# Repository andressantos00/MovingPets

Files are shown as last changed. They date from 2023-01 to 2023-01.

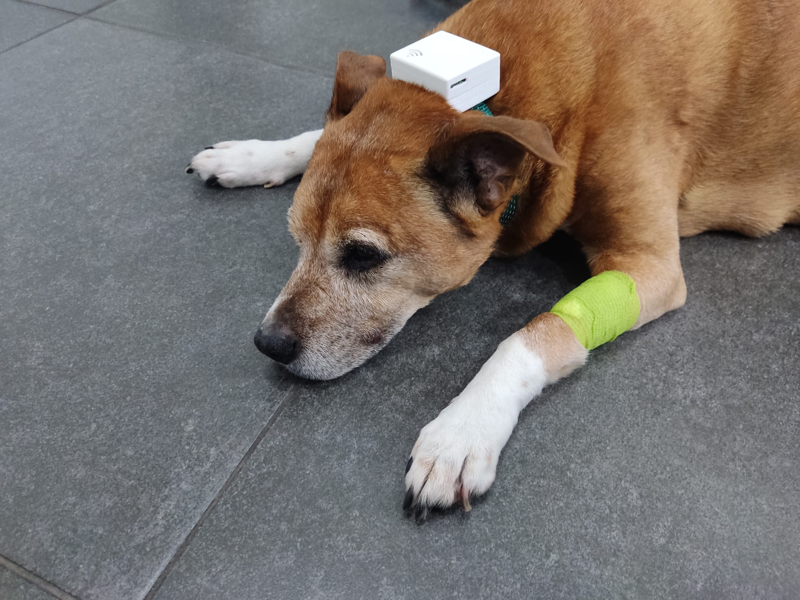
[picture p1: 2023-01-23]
Documentação/Sessão Final/Moving_Pets.jpg

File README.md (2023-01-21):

# MovingPets
Repositório de ficheiros elaborados no âmbito da cadeira de Projeto Industrial para a empresa "Pet Universal"

## Resumo
Quando um animal é sujeito a uma intervenção cirúrgica e há a necessidade de ficar hospitalizado, torna-se imperativo que, por parte da equipa veterinária, suceda um acompanhamento do estado de saúde do mesmo. Neste sentido, o projeto Moving Pets vem solucionar este problema, através do desenvolvimento de uma coleira capaz de medir o ritmo cardíaco, os níveis de oxigénio, a temperatura e, além disso, detetar o movimento do animal, dados que podem ser visualizados na aplicação móvel desenvolvida.

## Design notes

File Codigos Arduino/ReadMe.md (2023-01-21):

## Informações

Códigos criados pela equipa de hardware, com base nas bibliotecas existentes dos sensores usados, que se resumem a:
  - Código no concentrador;
  - Receber dados da esp8266 e enviar para a firebase;
  - Enviar dados da Esp8266 e enviar para o concentrador, com posterior envio destes para o wi-fi da clinica.

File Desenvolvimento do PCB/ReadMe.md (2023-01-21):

## Informações
A criação dos PCB`s foi da autoria dos membros do grupo, de modo a auxiliar a criação do primeiro protótipo de uma coleira.

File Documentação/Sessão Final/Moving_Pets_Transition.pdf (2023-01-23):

## 42088 – Projeto Industrial

# Relatório Final do Projeto

## Sessão Final - Transição

Nome do Projeto: | Moving Pets
Empresa: | Pet Universal
Orientador da Empresa: | Eng. Luís Pinto
Data: | 23/01/2023
Membros da Equipa: | Contacto principal: Bruna Pires | bruna.ramos.pires@ua.pt | +351 936 038 835 Membros do grupo: André Santos | andre.ssantos@ua.pt | +351 910 848 545 Daniel Almeida | danielba@ua.pt | +351 960 436 934 Gonçalo Martins | goncalom23@ua.pt | +351 934 554 483 João Francisco | joaofpedrosa@ua.pt | +351 962 478 430
Orientador: | Prof. Osvaldo Pacheco

## Índice

## I. Introdução

Atualmente, em situações onde um animal é sujeito a uma intervenção cirúrgica e se mostra necessário ficar hospitalizado, surge a necessidade, por parte da equipa veterinária, de verificar regularmente o estado de saúde destes seres, para garantir que está tudo bem com eles e acompanhar a sua evolução.

Neste sentido, o projeto Moving Pets vem solucionar este problema, uma vez que permitirá a monitorização do nível de atividade dos animais internados em box hospitalar.

Com o referido em mente, a solução idealizada pelo grupo é baseada na implementação de uma coleira com um microcontrolador - ESP8266 - e um conjunto de sensores, tais como: temperatura, ritmo cardíaco e níveis de oxigénio, como também um módulo acelerómetro digital. No que respeita à bateria, será utilizada uma Li-Po, que visa uma autonomia mínima de, aproximadamente, 5 dias.

Os dados recolhidos pelos sensores, face à interligação que terão com o microcontrolador, serão encaminhados via WiFi para um concentrador, também este composto por um microcontrolador - ESP8266.

Este concentrador irá estar ligado à rede WiFi da clínica veterinária e enviará os dados para uma base de dados (Firebase).

Através de uma aplicação móvel para tablet, o utilizador final terá acesso aos valores dos dados recolhidos pelos sensores.

O presente documento, referente à Sessão Final, aborda o progresso no desenvolvimento do projeto até ao momento e engloba a fase de transição, encontrando-se dividido em dezasseis secções, além da atual.

Começa-se por fazer um breve resumo, de forma a situar o leitor acerca das tarefas referentes ao projeto Moving Pets que se encontram concluídas, para que, a partir daí, se possam aprofundar mais os detalhes inerentes ao trabalho já efetuado.

O sexto ponto descrito, a Arquitetura do projeto, faz referência a diagramas de blocos e ao fluxograma, elementos desenvolvidos como parte da apresentação da solução idealizada para este produto.

De seguida, são apresentados as Tarefas especificadas (Calendarização vs. Implementação), englobando a explanação do progresso e desvio do plano inicial, bem como evidenciando o plano de trabalho para a próxima iteração, para que seja possível aferir, de uma forma mais detalhada, o que foi relatado no resumo previamente referido nesta secção.

O décimo tópico a abordar refere-se aos Riscos que afetaram o desenvolvimento do trabalho previsto, provocando alterações na forma como foi planeado e distribuído, quer temporalmente, quer com base nos recursos humanos disponíveis no momento inicial.

Segue-se uma análise ao orçamento apresentado na última entrega, com a respetiva retificação que se encontra detalhada e justificada no ponto Estado financeiro.

No décimo segundo ponto deste documento é elencado o trabalho que cada elemento da equipa desenvolveu, de uma forma mais pormenorizada, sendo possível aferir qual a contribuição individual de cada elemento para o bom desempenho que o grupo apresentou até ao momento.

Por fim, o último ponto deste documento pretende evidenciar as principais conclusões a retirar do trabalho efetuado, bem como deixar uma perspetiva clara acerca das tarefas a desenvolver num trabalho futuro.

## II. Breve sumário do estado do projeto

Até ao momento, uma vez concluída a fase de transição, o projeto possui um protótipo final da solução idealizada inicialmente pelo grupo.

De salientar que a equipa de hardware, responsável pela parte de sensorização do projeto, estabeleceu conectividade entre o microcontrolador - ESP8266 - e os três sensores utilizados no projeto:

- Sensor de temperatura;
- Sensor de ritmo cardíaco e níveis de oxigénio;
- Módulo acelerómetro.

Por sua vez, a equipa de backend, encarregue pelo desenvolvimento, numa fase inicial, de um web service - que permitisse expor, numa tabela, os dados recolhidos pelos sensores - encontrou-se a formular um setup que possibilite aos médicos veterinários definir o tempo de recolha de dados que considerem mais adequado.

No que concerne ao desenvolvimento da aplicação móvel para tablet a mesma apresenta as seguintes páginas, a saber:

- Página de Login;
- Escolha do concentrador sobre o qual o utilizador pretende obter informações;
- Indicação do nome do animal associado à coleira especificada;
- Apresentação dos dados recolhidos pelos sensores.

Tendo em consideração as fases de um projeto (Inception, Elaboration, Construction e Transition), bem como os objetivos principais inerentes às mesmas, e ainda a planificação destinada ao desenvolvimento do projeto, representada no Gantt Chart (em anexo), desenvolvido na fase Inception, podemos considerar que o projeto se encontrou alinhado, de forma a cumprir-se com as datas de entrega estipuladas.

No que concerne ao orçamento do projeto, este encontra-se dentro dos limites estabelecidos pela empresa Pet Universal.

Como referido acima, o projeto decorreu como previsto.

## III. Estado do projeto

Numa fase inicial do projeto e, após reunir com o Engenheiro Luís Pinto, orientador por parte da empresa, ficou definido que o produto a desenvolver se focava numa coleira capaz de recolher dados clínicos do animal, a saber: ritmo cardíaco e níveis de oxigénio, temperatura e o nível de atividade do animal.

Na sua versão final, o presente projeto é composto por uma coleira standart, por um concentrador e por uma aplicação móvel para tablet.

A coleira acima referida foi desenvolvida com o propósito de medir o ritmo cardíaco, os níveis de oxigénio, a temperatura e, além do elencado, detetar o movimento do animal.

O protótipo final da mesma é composto pela coleira (tecido) e por duas caixas, em que uma delas é composta por: um microcontrolador (ESP8266), um módulo boost step up (0.9..4.2V para 5V -40..480mA), uma bateria 3.7V (500mAh Li-Po), um módulo carregador de bateria Li-Ion 1A e, por último, um interruptor deslizante de duas posições. Por outro lado, a segunda caixa incorpora três sensores, a saber: sensor de ritmo cardíaco e níveis de oxigénio, sensor de temperatura e o módulo acelerómetro digital (três eixos).

No que respeita ao concentrador, está previsto que este se encontre ligado à rede WiFi da clínica veterinária e envie os dados recolhidos pelos sensores para uma base de dados, mais concretamente, para a Firebase.

O mesmo é composto por uma caixa que contém no seu interior um microcontrolador (ESP8266), sendo ainda constituído por um cabo USB 2.0 A macho/ micro-USB macho e por um carregador de tomada USB.

Em relação ao desenvolvimento da aplicação móvel para tablet, a mesma apresenta as seguintes páginas, a saber:

- Página de Login;
- Escolha, por parte do utilizador, do concentrador sobre o qual pretende obter informações;
- Indicação do nome do animal associado à coleira especificada;
- Apresentação dos dados recolhidos pelos sensores, em tempo real.

A Pet Universal, empresa com a qual o nosso grupo estabeleceu parceria ao longo do semestre, pretendia que, com o desenvolvimento do projeto Moving Pets, se criasse um produto capaz de monitorizar o nível de atividade de animais internados em box hospitalar.

Tendo em conta o mencionado anteriormente, podemos afirmar que o objetivo deste projeto foi concluído com êxito.

## IV. Resumo do projeto

Com o referido em mente, a solução idealizada pelo grupo foi baseada na implementação de uma coleira com um microcontrolador - ESP8266 - e um conjunto de sensores, tais como: temperatura, ritmo cardíaco e oxímetro, como também um módulo acelerómetro digital. No que respeita à
bateria, será utilizada uma célula de lithium 18650, com um módulo de carregamento visando uma autonomia mínima de 5 dias.
Os dados recolhidos pelos sensores, face à interligação que terão com o microcontrolador, serão encaminhados via WiFi para um concentrador, também este composto por um microcontrolador -ESP8266.
Este concentrador irá estar ligado à rede WiFi da clínica veterinária e enviará os dados para uma base de dados.
Através de uma aplicação móvel para tablet, o utilizador final terá acesso aos dados recolhidos pelos sensores.
A implementação desta solução permitirá a recolha de uma vasta gama de informações acerca do animal, a saber: a temperatura do mesmo, movimento do animal bem como batimentos cardíacos e níveis de oxigénio.

## V. Definição e esboço do projeto

Com este projeto ambicionamos obter uma coleira capaz de analisar os sinais vitais de animais em box hospitalares.
Uma coleira que deteta e interpreta nos animais os seus:
- Movimentos;
- Batimentos cardíacos;
- Níveis de Oxigénio no sangue;
- Temperatura.

Através do WiFi estas informações serão enviadas para uma base de dados - a Firebase - e a Pet Universal responsabilizou-se por criar um software que processa estes dados.

## VI. Arquitetura do projeto

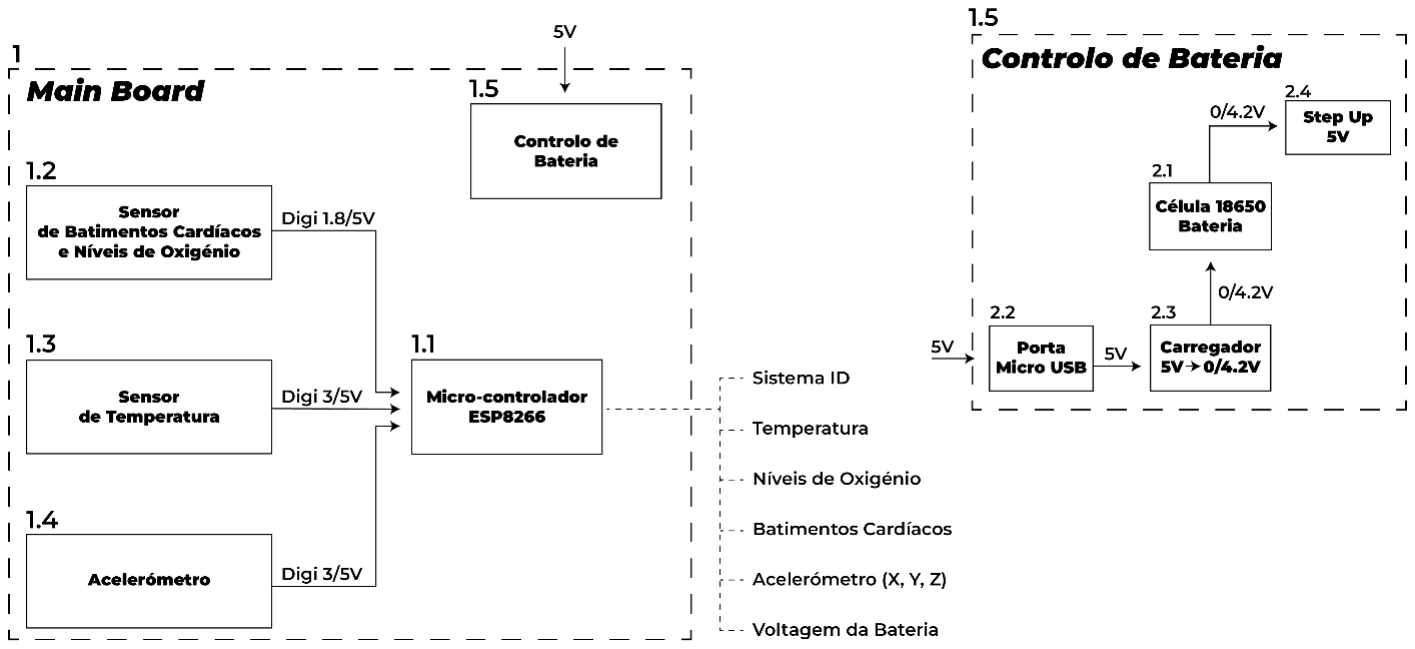
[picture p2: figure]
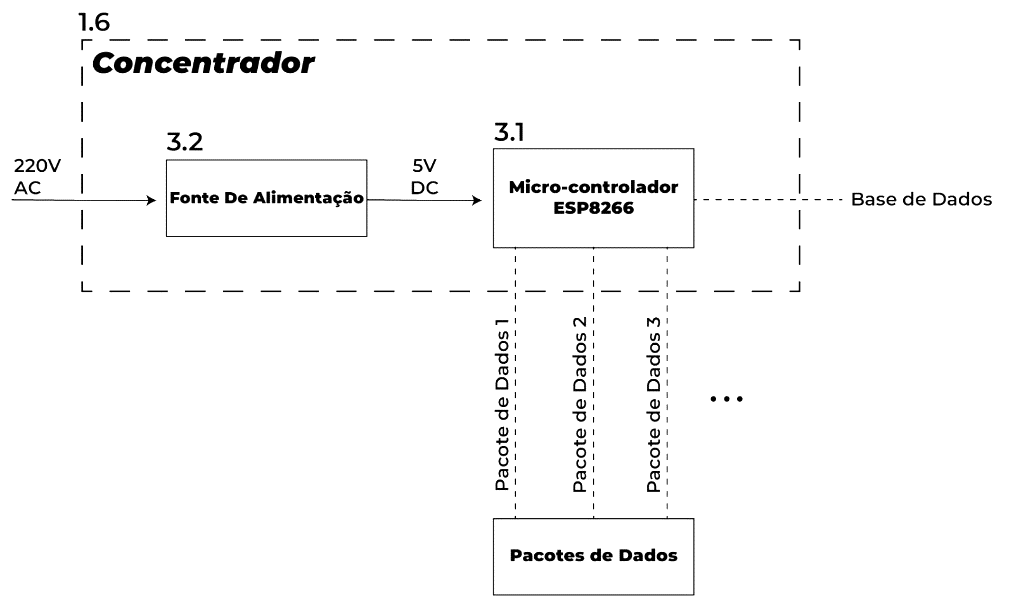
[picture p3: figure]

Figura 1 - Solução: Diagrama de Blocos

Em relação à arquitetura do sistema, contamos com dois diagramas de blocos, que correspondem ao sistema que vai estar presente na coleira do animal, e ao concentrador, que vai permitir o envio dos variados pacotes recebidos da coleira para a internet do hospital veterinário (Figura 1).

No fluxograma apresentado de seguida (Figura 2), temos os diferentes estados que o sistema empregue na coleira irá possuir.

Começamos pelo “DeepSleep” da ESP8266, que se concretiza por um modo de poupança de energia, com a duração de 5 minutos, onde esta estará desligada.

Após a passagem do tempo definido, a ESP8266 irá ligar-se, pedir valores aossensores(Acelerómetro, Temperatura e Oxímetro) e posteriormente criar um pacote de dados que irá ser enviado via WiFi para o concentrador.

De seguida, a ESP8266 irá voltar ao estado “DeepSleep”, o que resulta num período de operação de 1 segundo no seu estado ativo, intervalado por 5 minutos inativa. Com isto, temos um consumo 165mA por dia, o que se traduz em cerca de 5 dias de uso.

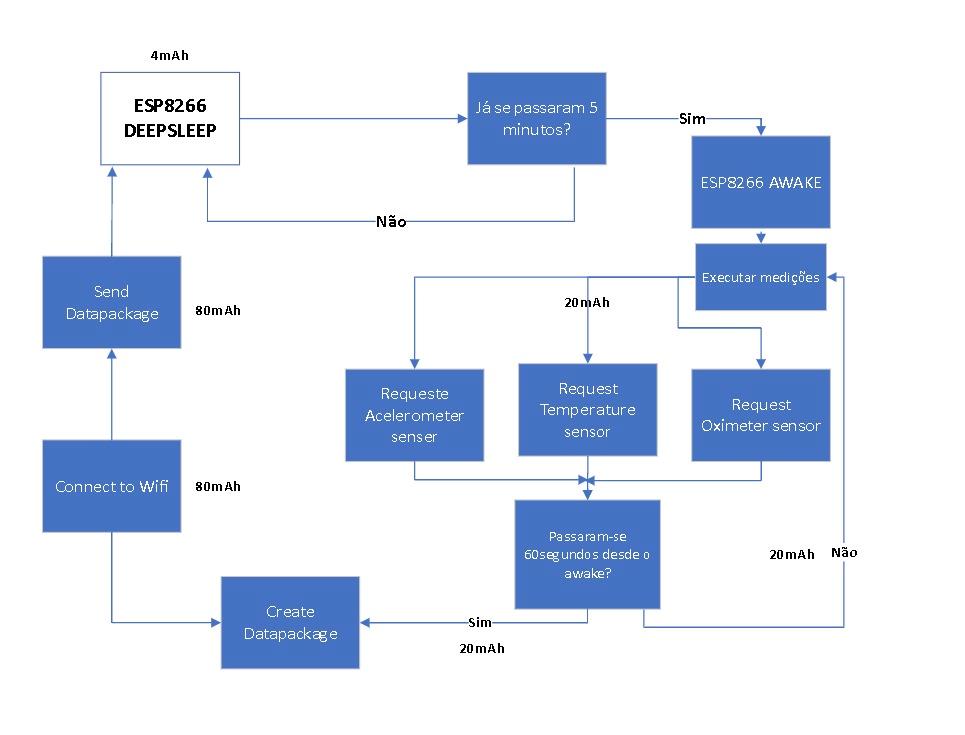
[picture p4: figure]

Figura 2 - Solução: Fluxograma

## VII. Documentos de design e produção

O grupo criou um repositório no GitHub onde se encontra a documentação técnica necessária para o desenvolvimento do presente projeto, pode ser consultado em:
- https://github.com/andressantos00/MovingPets

## VIII. Testes

No decorrer do desenvolvimento do projeto, o grupo testou o hardware desenvolvido que, posteriormente, será implementado nas coleiras. Esta ação teve como finalidade verificar a operacionalidade dos sensores, bem como a precisão dos dados recolhidos, quando empregues em animais.
Para isso, o primeiro teste realizado teve como cobaia uma gata de seis meses. O hardware implementado em placa branca, constituído por um microcontrolador - ESP8266 - e três sensores, foi aproximado junto do pescoço do animal e os dados recolhidos pelos sensores foram armazenados e apresentados num Google Sheets concretizado para o efeito – [Testes] - Coleira.
Alternativamente, o hardware foi aproximado na região tórax do animal a fim de verificar a variação dos dados recolhidos, permitindo concluir em que zona os dados se mostravam mais fidedignos e estáveis.
O resultado destes testes teve parecer positivo, porém o grupo quis generalizar mais esta testagem, por isso deslocou-se até ao Hospital Veterinário de Aveiro. Este contexto permitiu que o grupo realizasse ensaios, tanto em cães, como em gatos, com características diferenciadas, tais como: pelagens e dimensões.
Em suma, este primeiro período de testagens permitiu concluir que os dados recolhidos pelos sensores são mais satisfatórios quando são retirados junto do pescoço do animal, ou seja, existe a propensão de uma coleira standard para o protótipo do produto final.

IX. Tarefas especificadas (Calendarização vs.

## Implementação)

ID | Descrição | Data original | Data Reformulada | Data Real
1 | Especificação, escolha e aquisição dos sensores | 2ª e 3ª semana de outubro | Data original | Data original
2 | Especificação do concentrador | 2ª e 3ª semana de outubro | Data original | Data original
3 | Estudo e especificação do layout da coleira | 2ª e 3ª semana de outubro | Data original | Data original
4 | Design da arquitetura do sistema: Diagrama de blocos | 4ª semana de outubro à 1ª semana de novembro | Data original | Data original
5 | Implementação da componente de hardware: conectividade entre o microcontrolador (ESP8266) e os três sensores aplicados no projeto (sensor de temperatura, módulo acelerómetro e sensor de ritmo cardíaco eníveis de oxigénio) | 2ª semana de novembro à 3ª semana de dezembro | 3ª semana de novembro | 3ª semana de novembro
6 | Implementação do concentrador: comunicação entre microcontroladores e visualização em dashboard dos dados recebidos | 2ª semana de novembro à 3ª semana de dezembro | 3ª semana de novembro | 4ª semana de novembro
7 | Interligação Backend-Hardware | 1ª, 2ª e 3ª semana de dezembro | 4ª semana de novembro à 2ª semana de dezembro | 4ª semana de novembro
8 | Especificação da implementação do hardware na coleira | 1ª, 2ª e 3ª semana de dezembro | Data original | 1ª semana de janeiro
9 | Testes do produto | 1ª, 2ª e 3ª semana de dezembro | Data original | 2ª semana de janeiro
10 | Validação | 4ª semana de dezembro e 1ª semana de janeiro | Data original | 2ª semana de janeiro
11 | Montagem do produto | 2ª e 3ª semana de janeiro | Data original | 2ª semana de janeiro

## a) Progresso e desvio do plano

No que concerne ao layout da coleira, o plano inicial que o grupo equacionou consistia no desenvolvimento de uma caixa, onde estaria contida a parte de hardware - sensores e microcontrolador, e que, posteriormente, seria integrada numa coleira standard, como se encontra representado na Figura 3.

Porém, de forma a conseguir recolher a informação mais fidedigna possível, o grupo irá também considerar o layout de uma coleira dorsal, como se encontra representado na Figura 4, fazendo com que a recolha dos dados seja feita em dois locais diferentes, e se possam fazer testes, de forma a que a escolha entre coleira standard e a coleira dorsal, para o produto final, seja feita segundo a que mostre recolher melhores resultados.

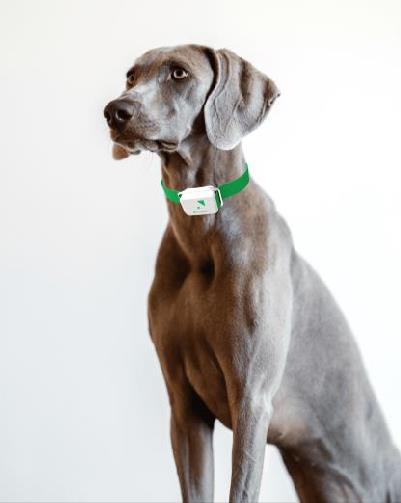
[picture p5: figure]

Figura 3 - Protótipo inicial da coleira a desenvolver

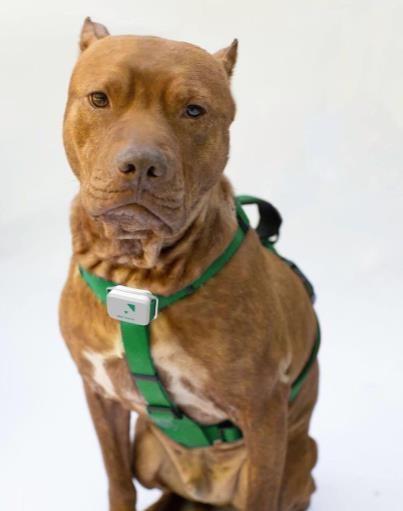
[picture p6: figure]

Figura 4 - Protótipo a considerar da coleira a desenvolver

## X. Riscos

Em relação aos riscos, não serão abordados os riscos de nível 4, uma vez que a probabilidade de se verificarem é muito baixa.

Iniciaremos pelos riscos que ocorreram ao longo do desenvolvimento do projeto.
O primeiro ponto a referir passa pelo software de visualização dos dados recolhidos desenvolvido pela empresa não ter sido terminado (em tempo útil). Neste contexto, o grupo para mitigar o risco em questão, passou pela elaboração de uma aplicação móvel para tablet, para que seja possível apresentar o produto final completamente funcional, sem depender de recursos externos para tal.

Outro risco a evidenciar é a qualidade do produto não atingir a expectativa do cliente, isto é, com o decorrer dos trabalhos, o produto que se está a desenvolver não corresponder ao idealizado pelo cliente. Como forma de mitigar este risco, utilizamos um método Agile para o desenvolvimento deste projeto, de forma a garantir a sinergia entre o que é desenvolvido pela equipa e o que é pretendido pelo cliente.

O terceiro maior risco a abordar, passa pela existência de defeitos no software. Estes podem não ser detetados até à implementação total dos componentes, ou seja, durante os testes individuais podem funcionar como pretendido, mas quando o produto estiver concluído e for testado no ambiente real, podem surgir falhas, provenientes de fatores não considerados em testes individuais dosmódulos funcionais.

De forma a colmatar situações como a descrita acima, serão efetuados testes em vários ambientes reais e será feita uma revisão do código frequente.

Apontando agora os riscos de nível 3, identificamos três riscos que vão ter influência direta no desenvolvimento do trabalho.

Um dos riscos que foi apresentado até ao momento, prendeu-se com a possibilidade de ocorrer um atraso na impressão do PCB desenvolvido, risco que acabou por se verificar, o que provocou demora no progresso dos trabalhos que, por sua vez, afetou a calendarização planeada. Na tentativa de evitar percalços deste género, optámos por criar uma margem de erro na calendarização, para minimizar o efeito de eventuais imprevistos como este.

O último risco a evidenciar prende-se com a imprecisão dos dados recolhidos pelos sensores, o que pode resultar no envio de valores pouco precisos para a aplicação. Uma situação deste género, além de desvalorizar o produto, trará uma vertente de incerteza e desconfiança por parte dos utilizadores, que não sabem se podem confiar nos dados apresentados. Especificando, podem pensar que está tudo beme o animal necessita de cuidados, e o inverso. Como medida para mitigar este risco, vamos testar, sempre que possível, em ambiente real.

De seguida, são apresentadas as tabelas de gestão de riscos.

11

Tabela 1 - Análise Inicial

Análise Inicial

# | Risco | Consequência | Probabilidade | Gravidade | Nível | Solução

1 | Imprecisão dos dados recolhidos pelos
| sensores | Alertas errados para a
| | aplicação | Ocasional | Marginal | 3 | Recolha de informação + Testes

3

Software de visualização dos dados recolhidos desenvolvido pela empresa (tempo útil)

Não ser possível analisar
os dados | Remoto | Crítico | 2 | Feature extra: Aplicação Móvel

### 5 Doença Inesperada

Falta defuncionamento
num dos componentes | Remoto | Negligenciável | 4 | Ter o trabalho sempre dentro dos prazos

9

Defeitos no software que poderão não

ser detetados atéà sua implementação Alterações de última hora | Ocasional | Crítico | 2 | Revisões dos programas e testagens sobre
| | | | qualquer ambiente

12

Tabela 2 - Análise Riscos Residuais

Análise Riscos Residuais

Consequência | R_Likel. | R_Sever. | R_Level
Alertas com uma imprecisão de percentagem baixa | Remoto | Negligenciável | 4
Nem todos os dados serem possíveis para análise | Ocasional | Marginal | 3
Produto ligeiramente desviado do pretendido | Remoto | Negligenciável | 4

## XI.Estado financeiro

Tabela 3 - Orçamento

# | Categoria | Descrição | Estado | Valor/un

4 | Microcontrolador | Microcontrolador com acesso ao WiFi (ESP8266) | Adquirido | 5,99 €
2 | Sensores | Módulo acelerómetro digital-3 eixos (ADXL-345) | Adquirido | 4,94 €
2 | Sensores | Sensor de temperatura | Adquirido | 3,70 €
2 | Sensores | Sensor de ritmo cardíaco e níveis de oxigenação | Adquirido | 7,32 €
2 | Botões e Interrupto-res/ Deslizantes | Interruptor deslizante 2 posições estáveis - ON-ON -250VAC 1A (6 pinos) | Adquirido | 0,73 €
1 | Baterias | 18650 cell | Adquirido | 5,48 €
2 | Baterias e Pilhas | Bateria Lítio Polímero 3.7v 500 mAh | Adquirido | 7,66 €
3 | Carregamento de ba-terias e BMS | Módulo carregador de bateria Li-Ion 1A - entrada Mi-cro-USB | Adquirido | 1,96 €
3 | Conversores Step Up | Módulo Boost Step Up - 0.9..4.2V para 5V -40..480mA | Adquirido | 2,05 €
6 | Terminais | Ficha Micro-USB (fêmea) | Adquirido | 0,85 €
Total: | 95,27 €

Foi adquirido um componente de cada tipo, para que fosse possível começar a realizar testes. Nesta primeira fase foi feito um investimento total de 45,27 €.

Após a aquisição anteriormente referida, no momento da montagem, em placa branca, da componente de hardware, o grupo deparou-se com dois componentes não funcionais, o que originou a necessidade de encomendar, novamente, esses componentes - módulo carregador de bateria Li-Ion 1A e módulo Boost Step Up.

Relativamente à bateria das coleiras, o grupo adquiriu, na primeira fase de compras, uma bateria 18650, porém optou-se pela escolha de uma bateria Li-Po ao invés da referida anteriormente, uma vez que o peso destas é um fator a ter em conta, não podendo este apresentar um valor significativo, já que nos referimos a uma coleira destinada a animais.

Desta forma, até ao momento, foi realizado um investimento total de 60,61 € (45,27 € + 15,34 €).

Se a testagem apresentarresultados positivos, está planeada a aquisição dosrestantes componentes, para que se possa terminar o projeto com duas coleiras funcionais bem como dois concentradores, o que vai culminar no orçamento total descrito na tabela acima (Tabela 3).

## XII. Contribuição do grupo

Membro do

Grupo | Maior(es) Contribuição(ões) | Percentagem de trabalho (%)

Bruna Pires

Fase Inicial até à fase de Elaboração, inclusive:
- Desenvolvimento da documentação referente a três propostas de projetos;
- Pesquisa: sensores a utilizar e métodos de implementação da solução idealizada;
- Desenvolvimento da apresentação referente à Milestone 1 e Milestone 2;
- Desenvolvimento do documento “Planeamento do Projeto”;
- Participação no desenvolvimento do Excel “Gestão Dos Riscos”;
- Participação no desenvolvimento do documento “Relatório do Estado do Projeto”;
- Realização da conectividade entre o microcontrolador - ESP8266 - e o sensor de ritmo cardíaco e níveis de oxigénio e posterior testagem do mesmo.
Fase de Construção I:
- Desenvolvimento da apresentação referente à Milestone 3;
- Participação no desenvolvimento de testes em animais do hardware a ser implementado nas coleiras;
- Desenvolvimento de uma aplicação móvel para tablet;
- Desenvolvimento do documento “Relatório do Estado do Projeto”.
Fase de Construção II:
- Arduino IDE: Conectividade entre os sensores e a base de dados (Firebase);
- Apresentação dos dados armazenados na Firebase na aplicação móvel para tablet;
- Desenvolvimento da apresentação referente à Milestone 4;
- Desenvolvimento do documento “Relatório do Estado do Projeto”.
Fase de Transição:
- Desenvolvimento da apresentação referente à Sessão Final;
- Desenvolvimento do documento “Relatório Final do Projeto”;
- Preenchimento do ficheiro markdown.

23%

André Santos

Fase Inicial até à fase de Elaboração, inclusive:
- Pesquisa: sensores a utilizar, métodos de implementação da solução idealizada, consumos energéticos e receção de dados com o Google Sheets;
- Participação no desenvolvimento do documento “Visão do Projeto”;
- Participação no desenvolvimento do Excel “Gestão Dos Riscos”;
- Participação no desenvolvimento do documento “Relatório do Estado do Projeto”;
- Criação de um esboço no Fusion 360 do modelo da coleira.
Fase de Construção I:
- Participação no desenvolvimento do modelo 3D da caixa do concentrador no Fusion 360;
- Participação no desenvolvimento de testes em animais do hardware a ser implementado nas coleiras.
Fase de Construção II:
- Desenvolvimento do modelo 3D da caixa a incorporar na coleira por intermédio do Fusion 360.
Fase de Transição:
- Desenvolvimento de um repositório no GitHub com a documentação do projeto.

18,5%

Membro do

Grupo | Maior(es) Contribuição(ões) | Percentagem de trabalho (%)

Daniel Almeida

Fase Inicial até à fase de Elaboração, inclusive:
- Participação no desenvolvimento do documento “Visão do Projeto”;
- Participação no desenvolvimento do Excel “Gestão Dos Riscos”;
- Participação no desenvolvimento do documento “Relatório do Estado do Projeto”;
- Formulação da comunicação entre dois microcontroladores - ESP8266 - e visualização em dashboard de dados recebidos.
Fase de Construção I:
- Participação no desenvolvimento do PCB no Fusion 360.
Fase de Construção II:
- Configuração da UI que permite ao utilizador configurar a ligação à rede com acesso à internet.
Fase de Transição:
- Participação no desenvolvimento do vídeo do projeto.

18,5%

Gonçalo
Martins

Fase Inicial até à fase de Elaboração, inclusive:
- Pesquisa: sensores a utilizar, métodos de implementação da solução idealizada, consumos
energéticos | e | receção | de | dados | com | o | Google | Sheets;
- Participação no desenvolvimento do documento “Visão do Projeto”;
- Desenvolvimento dos diagramas de blocos presentes na apresentação referente Milestone 2;
- Participação no desenvolvimento do documento “Relatório do Estado do Projeto”;
- Realização da conectividade entre o microcontrolador - ESP8266 - e o sensor de temperatura bem como o módulo acelerómetro;
- Arduino IDE: Programação do módulo ESP8266.
Fase de Construção I:
- Participação no desenvolvimento do modelo 3D da caixa do concentrador no Fusion 360;
- Impressão 3D do modelo desenvolvido da caixa do concentrador;
- Participação no desenvolvimento de testes em animais do hardware a ser implementado nas coleiras.
Fase de Construção II:
- Desenvolvimento do PCB no EasyEDA;
- Impressão 3D do modelo desenvolvido da caixa a incorporar na coleira.
Fase de Transição:
- Implementação de uma tabela de dados com comunicação com a Firebase na aplicação;
- Código que fornece a data e hora para o concentrador;
- Montagem e manutenção da coleira, soldar e ressoldar o PCB, substituir componentes que queimaram e debug;
- Novo esquemático;
- Novo design de PCB.

22%

João Pedrosa

Fase Inicial até à fase de Elaboração, inclusive:
- Participação no desenvolvimento do documento “Visão do Projeto”;
- Participação no desenvolvimento do Excel “Gestão Dos Riscos”;
- Participação no desenvolvimento do documento “Relatório do Estado do Projeto”;
- Formulação da comunicação entre dois microcontroladores - ESP8266 - e visualização em dashboard de dados recebidos.
Fase de Construção I:
- Participação no desenvolvimento do PCB no Fusion 360;
- Participação no desenvolvimento de testes em animais do hardware a ser implementado nas coleiras.
Fase de Construção II:
- Formulação do setup que possibilite aos médicos veterinários definir o tempo de recolha de dados que considerem mais adequado.
Fase de Transição:
- Participação no desenvolvimento do vídeo do projeto.

18%

## XIII. Outras questões

Nada a assinalar.

## XIV. Comentários e observações

Nada a assinalar.

## XV.Conclusões

Dado o atual progresso deste projeto, pode-se aferir que os objetivos essenciais, propostos numa fase inicial, foram cumpridos com sucesso.

De uma forma mais detalhada, o facto de ser possível recolher dados com valores credíveis provenientes de todos os sensores, de conseguir que estes comuniquem eficazmente com o concentrador e de armazenar e apresentar esses mesmos dados (no Google Sheets), todos estes fatores espelham o bom rumo do trabalho efetuado, até ao momento.

No seguimento do anteriormente referido, os avanços significativos alcançados pela equipa, fizeram com que fosse possível alocar alguns dos elementos a tarefas distinguidas inicialmente como secundárias, com vista a aumentar a utilidade e o valor do produto que se está a desenvolver, no seu mercadoalvo.

## XVI. Anexos Anexo 1 – Gantt Chart

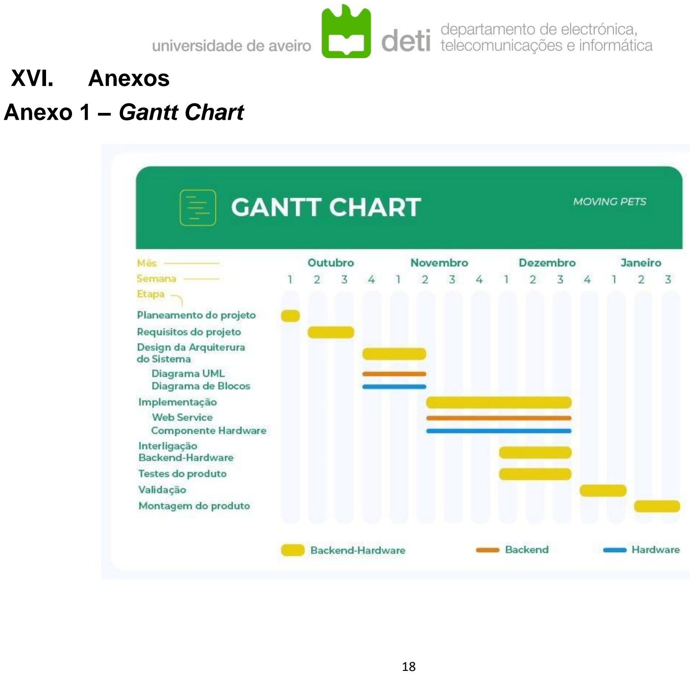
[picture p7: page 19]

18

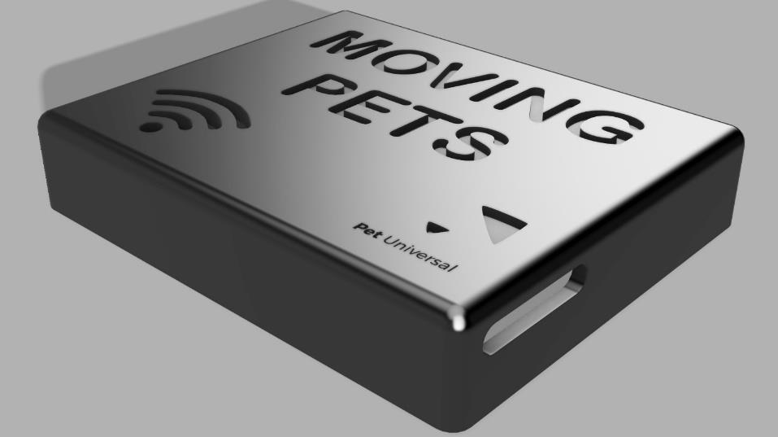
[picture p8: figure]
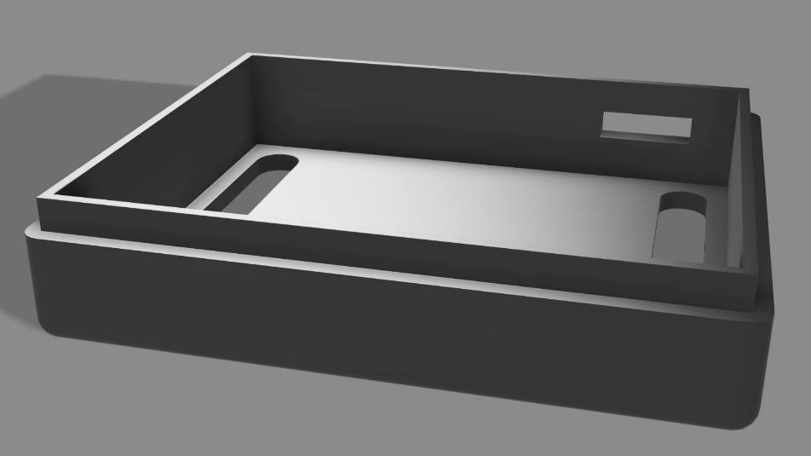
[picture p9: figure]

18

## Anexo 2 – Protótipo da caixa a incorporar na coleira

Figura 5 – Tampa da caixa

Figura 6 – Base da caixa

19

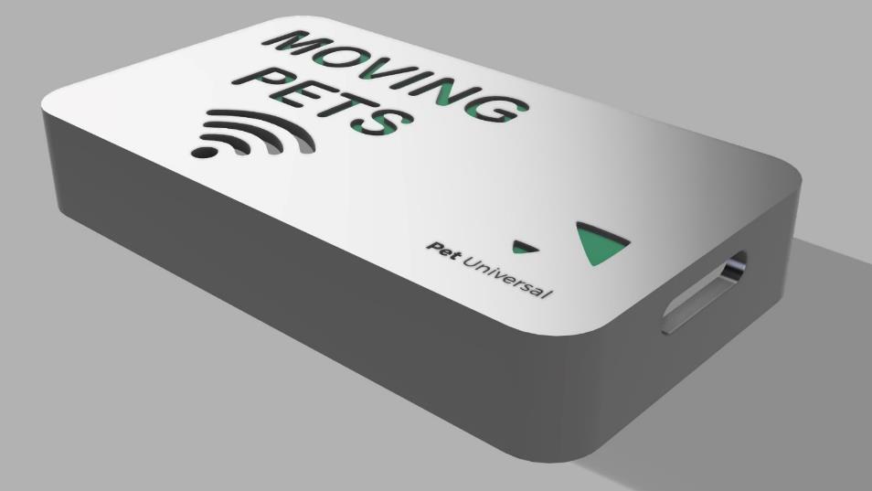
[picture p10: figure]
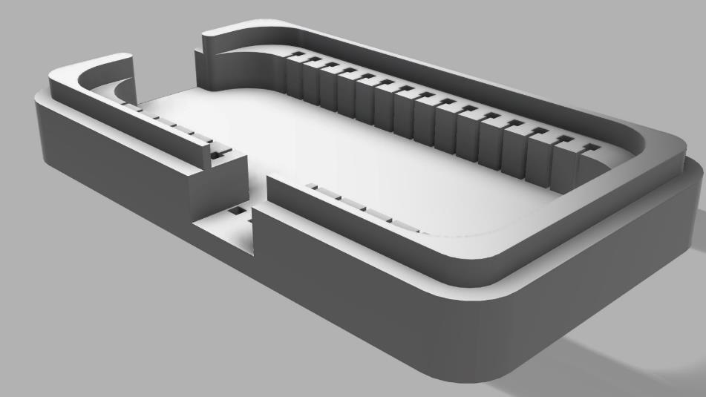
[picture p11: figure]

18

## Anexo 3 – Protótipo da caixa do concentrador

Figura 7 – Tampa do concentrador

Figura 8 – Base do concentrador

20

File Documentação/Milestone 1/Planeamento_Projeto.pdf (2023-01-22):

## 42088 – Projeto Industrial

# Planeamento do Projeto

Nome do projeto: | Moving pets
Empresa: | Pet Universal

Membros da equipa:

Contacto principal:
Bruna Pires | bruna.ramos.pires@ua.pt | +351 936 038 835.
Membros do grupo:
André Santos | andre.ssantos@ua.pt | +351 910 848 545
Daniel Almeida | danielba@ua.pt | +351 960 436 934
Gonçalo Martins | goncalom23@ua.pt | +351 934 554 483
João Francisco | joaofpedrosa@ua.pt | +351 962 478 430
Data: | 26/10/2022

Histórico de Revisões
Data | Edição | Descrição | Autor
22/10/2022 | 1.1 | Definição do que é o backend, o frontend e a sensorização; Definição das tarefas macro do projeto; Incorporar no documento as tarefas referidas no Gantt Chart; Fazer referência das tarefas que irão estar ao encargo da Pet Universal; Discriminar os valores finais da coleira e do concentrador. | Bruna Pires
25/10/2022 | 1.2 | Explicar a ideia inerente ao desenvolvimento de um diagrama UML. | Bruna Pires

### 1 Objetivos

Atualmente, em situações onde um animal é sujeito a uma intervenção cirúrgica e se mostra necessário ficar hospitalizado, surge a necessidade, por parte da equipa veterinária, de verificar regularmente o estado de saúde destes seres, para garantir que está tudo bem com eles e acompanhar a sua evolução.
Neste sentido, o projeto Moving Pets vem solucionar este problema, uma vez que permitirá a monitorização do nível de atividade dos animais internados em box hospitalar.
Com o referido em mente, a solução idealizada pelo grupo é baseada na implementação de uma coleira com um microcontrolador - ESP8266 - e um conjunto de sensores, tais como: temperatura, batimentos cardíacos e oxímetro, como também um módulo acelerômetro digital. No que respeita à bateria, será utilizada uma célula de lithium 18650, com um módulo de carregamento e manutenção da mesma, visando uma autonomia mínima de 30 dias.
Os dados recolhidos pelos sensores, face à interligação que terão com o microcontrolador, serão encaminhados via WiFi para um concentrador, também este composto por um microcontrolador - ESP8266. Este concentrador irá estar ligado à rede WiFi da clínica veterinária e enviará os dados para uma base de dados.
Através de um web service, o utilizador final terá acesso a uma tabela com os valores dos dados recolhidos pelos sensores.
O tratamento dos dados ficará encarregue da empresa - Pet Universal -, isto é, a plataforma que permitirá o utilizador final ser notificado sobre alterações do estado de cada animal e, em situações que o justifiquem, receber alertas.
A implementação desta solução permitirá a recolha de uma vasta gama de informações acerca do animal, a saber: a temperatura do mesmo, períodos/qualidade de descanso, a sua atividade (fazendo referência à intensidade da mesma), batimentos cardíacos e níveis de oxigénio.
Caso a solução apresentada seja concluída, com sucesso, dentro dos prazos convencionados, a nossa equipa compromete-se a desenvolver uma aplicação móvel que permitirá a visualização dos parâmetros recolhidos pelos sensores.

### 2 Calendário

Segue, em anexo (Anexo 1 – Gantt Chart), a calendarização prevista para o trabalho a realizar pela equipa.

### 2.1 Objetivos de cada iteração

Para o desenvolvimento da solução descrita no ponto 1 do presente documento, a equipa irá subdividir-se em duas: a equipa de hardware e a equipa de backend.
A equipa de hardware, que será composta por três elementos, ficará responsável pela parte de sensorização do projeto. Como tarefas macro do projeto, a equipa terá que especificar, escolher e adquirir os sensores bem como configurá-los e parametrizá-los.
Por sua vez, a equipa de backend, constituída por dois elementos, encarregar-se-á pelo desenvolvimento de um web service, permitindo, desta forma, expor numa tabela os dados recolhidos pelos sensores. Esta terá como tarefas macro do projeto, especificar e implementar o concentrador assim como implementar o software deste.
Em anexo a este documento, encontra-se um Gantt Chart com micro tarefas inerentes ao desenvolvimento da solução proposta.
Com o referido em mente, a equipa de backend ao longo das próximas três semanas, mais concretamente, até à fase seguinte – fase de elaboração –, irá obter de forma mais detalhada os requisitos necessários de maneira a comunicar com o microcontrolador. Assim sendo, a equipa desenvolverá um diagrama Unified Modeling Language - UML - de modo a especificar como todas as interações irão ser realizadas, isto é, um diagrama de componentes para um sistema de sensores onde será ilustrada a página Web e o desktop do utilizador final todos dependentes da base de dados, salientar que a parte de frontend está encarregue da Pet Universal.
A fim de mitigar alguns dos riscos que poderão estar inerentes, a equipa irá, com base neste documento, detalhar a solução que será mais eficiente.
Por sua vez, a equipa de hardware, paralelamente, irá de igual forma detalhar de forma mais pormenorizada os requisitos necessários de forma a obter interligação entre o microcontrolador e os sensores. Por esse motivo, desenvolverá um diagrama de blocos de modo a clarificar o funcionamento que se pretende que seja realizado.

### 3 Orçamento

Neste ponto são apresentados os custos referentes a cada componente a considerar nesta proposta.

Tabela 1 - Orçamento

Quantidade | ID | Categoria | Descrição | Valor
5 | ESP8266 | Microcontrolador | Microcontrolador com acesso ao WiFi | 5.99 €
2 | ADXL-345 | Sensores | Giroscópio | 4.94 €
2 | DS18B20 | Sensores | Sensor de temperatura | 3.70 €
2 | MAX30100 | Sensores | Sensor de ritmo cardíaco e níveis de oxigenação | 7.32 €
3 - | | Botões e Interrupto-res/ Deslizantes | Interruptor deslizante 2 posições estáveis - ON-ON - 250VAC 1A (6 pinos) | 0.73 €
2 | - | Baterias | 18650 cell | 5.48 €
3 | - | Baterias e Pilhas | Bateria Lítio Polímero 3.7v 500 mAh | 7.66 €
3 - | | Módulos e Kits/Alimentação/ Carregamento de baterias e BMS | Módulo carregador de bateria Li-Ion 1A - entra-da Micro-USB | 1.96 €
3 - | | Módulos e Kits/Alimentação/ Conversores Step Up | Módulo Boost Step Up - 0.9..4.2V para 5V -40..480mA | 2.05 €
6 - | | Fichas/Conectores/ Terminais | Ficha Micro-USB (fêmea) | 0.85 €
2 | - | - | PCB | 10.62 €
2 - | | Animais de Estima-ção/Coleiras, Trelas e Peitorais | Coleira TRIXIE Ajustável | 1.30 €
1 | - | Carregadores | Carregador Ewent USB Compacto 5W | 3.90 €
1 - | | Fichas e Cabos/ USB/ USB-A - micro-USB | Cabo USB 2.0 A macho - micro-USB macho 0.3m | 1.10 €
Total: | 143.97 €

Abaixo, segue-se de forma particularizada, o custo total intrínseco ao desenvolvimento de uma coleira, bem como, ao desenvolvimento de um concentrador.

Tabela 2 - Orçamento para o desenvolvimento de uma coleira

Quantidade | ID | Categoria | Descrição | Valor
1 | ESP8266 | Microcontrolador | Microcontrolador com acesso ao WiFi | 5.99 €
1 | DS18B20 | Sensores | Sensor de temperatura | 3.70 €
1 | MAX30100 | Sensores | Sensor de batimento cardíaco e níveis de oxigénio | 7.32 €
1 | ADXL-345 | Sensores | Giroscópio | 4.94 €
1 | - | Baterias | 18650 cell | 5.48 €
1 | - | Baterias e Pilhas | Bateria Lítio Polímero 3.7v 500 mAh | 7.66 €
1 - | | Módulos e Kits/Alimentação/ Carregamento de baterias e BMS | Módulo carregador de bateria Li-Ion 1A - entrada Micro-USB | 1.96 €
1 - | | Módulos e Kits/Alimentação/ Conversores Step Up | Módulo Boost Step Up - 0.9..4.2V para 5V - 40..480mA | 2.05 €
1 - | | Fichas/Conectores/ Terminais | Ficha Micro-USB (fêmea) | 0.85 €
1 | - | Botões e Interruptores/ Deslizantes | Interruptor deslizante 2 posições estáveis - ON-ON - 250VAC 1A (6 pinos) | 0.73 €
1 | - | - | PCB | 10.62 €
1 - | | Animais de Estimação/Coleiras, Trelas e Peitorais | Coleira TRIXIE Ajustável | 1.30 €
Total: | 52.60 €

Tabela 3 - Orçamento para o desenvolvimento de um concentrador

Quantidade | ID | Categoria | Descrição | Valor
1 | ESP8266 | Microcontrolador | Microcontrolador com acesso ao WiFi | 5.99 €
1 | - | Carregadores | Carregador Ewent USB Compacto 5W | 3.90 €
1 - | | Fichas e Cabos/ USB/ USB-A - micro-USB | Cabo USB 2.0 A macho - micro-USB macho 0.3m | 1.10 €
Total: | 10.99 €

### 4 Recursos

Para o desenvolvimento da solução apresentada no ponto 1 do presente documento, a equipa, coordenada pela Bruna Pires, irá subdividir-se em duas: a equipa de hardware e a equipa de backend.
A equipa responsável pelo hardware ficará encarregue pela parte do desenvolvimento do concentrador, bem como da sensorização do projeto – sensor de temperatura, sensor de ritmo cardíaco e níveis de oxigenação e pelo giroscópio – será composta pelo André Santos, pela Bruna Pires e pelo Gonçalo Martins, que ficarão encarregues por cada um dos sensores referidos anteriormente, respetivamente. Tendo em consideração que existirá no projeto uma parte dedicada ao desenvolvimento de um web service e uma aplicação móvel, esta última como feature extra, há uma parte a destacar: a parte que os utilizadores não podem ver ou interagir e que contém todas as funcionalidades do software, daí ser necessária a existência de uma equipa de backend, que estará ao encargo do João Francisco e do Daniel Almeida.
De forma a acompanhar os progressos de cada equipa, está prevista a realização de, pelo menos, três reuniões semanais, sendo uma delas a reunião com os orientadores, tanto por parte do DETI, como o representante da empresa, Pet Universal, que irá intervir na aprovação de decisões, bem como de documentos.

### 5 Comentários e observações

No ponto 3 do presente planeamento do projeto é elencado o orçamento, tendo em conta a abordagem referida nos objetivos.
Apesar de serem apresentadas nas tabelas 1 e 2 o valor inerente à aquisição de duas coleiras, estas irão ser fornecidas pela Pet Universal, porém é relevante a descriminação destas dado que representa um custo associado aquando de uma futura produção.
No desenvolvimento de qualquer produto, existem sempres riscos associados, não sendo este exceção.
Alguns destes riscos centram-se em aspetos tais como:
1. Imprecisão dos dados recolhidos pelos sensores:
a. Classificação do risco:
i. Possibilidade de ocorrer: Alta ii. Impacto: Alto
2. Atrasos na aquisição dos componentes:
a. Classificação do risco:
i. Possibilidade de ocorrer: Média ii. Impacto: Alto
3. Calendarização inadequada:
a. Classificação do risco:
i. Possibilidade de ocorrer: Baixa ii. Impacto: Médio
4. Software de visualização dos dados recolhidos desenvolvido pela empresa (em tempo útil) :
a. Classificação do risco:
i. Possibilidade de ocorrer: Baixa ii. Impacto: Alto
5. Dificuldades na integração com a equipa:
a. Classificação do risco:
i. Possibilidade de ocorrer: Baixa ii. Impacto: Médio.

Abaixo, é apresentado uma forma de mitigação dos riscos acima referidos, respetivamente:

1. Recolha de informação relativa a projetos no âmbito do desenvolvimento de hardware de monitorização de sinais fisiológicos em animais;
a. A equipa irá ter uma fase de testes de modo a averiguar a precisão dos sensores quando aplicados em animais.
2. Especial atenção na escolha do site para compra dos componentes, evitar AliExpress e derivados.
3. Calendarização com margens para erro e, caso se justifique, reformulação da mesma;
4. Feature extra: Aplicação Móvel;
5. Duas soluções possíveis a serem executadas: reformulação das equipas ou elemento “móvel”.
a. Como elemento “móvel” entende-se alguém com capacidades de ajudar tanto na equipa de hardware como na equipa de backend.

### 6 Anexo 1 – Gantt Chart

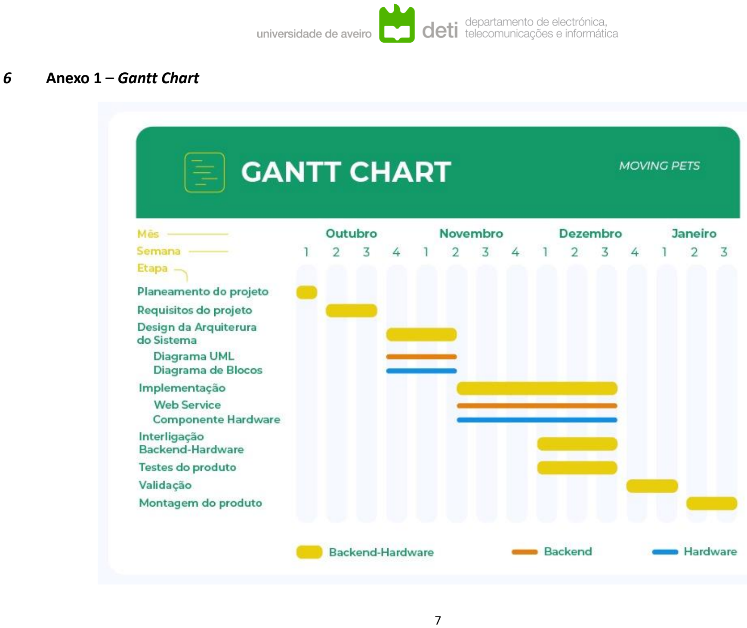
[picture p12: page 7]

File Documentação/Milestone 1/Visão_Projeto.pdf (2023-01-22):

## 42088 – Projeto Industrial

# Visão Do Projeto

Nome do projeto: | Moving pets
Empresa: | Pet Universal

Membros da equipa:

Contacto principal:
Bruna Pires | bruna.ramos.pires@ua.pt | +351 936 038 835.
Membros do grupo:
André Santos | andre.ssantos@ua.pt | +351 910 848 545
Daniel Almeida | danielba@ua.pt | +351 960 436 934
Gonçalo Martins | goncalom23@ua.pt | +351 934 554 483
João Francisco | joaofpedrosa@ua.pt | +351 962 478 430
Data: | 26/10/2022

Histórico de Revisões
Data | Edição | Descrição | Autor
22/10/2022 | 1.1 | Tópico 2: Especificação do produto principal a ser desenvolvido pela equipa. | Gonçalo Martins

### 1 Descrição do Projeto

Atualmente, em situações onde um animal é sujeito a uma intervenção cirúrgica e se mostra necessário ficar hospitalizado, surge a necessidade, por parte da equipa veterinária, de verificar regularmente o estado de saúde destes seres, para garantir que está tudo bem com eles e acompanhar a sua evolução.
Neste sentido, o projeto Moving Pets vem solucionar este problema, uma vez que permite a monitorização do nível de atividade dos animais internados em box hospitalar.
Com esta questão em mente, a solução idealizada pelo grupo é baseada na implementação de uma coleira com um microcontrolador - ESP8266 - e um conjunto de sensores, tais como: temperatura, batimentos cardíacos e oxímetro, bem como um módulo acelerômetro digital.
No que respeita à bateria, é utilizada uma célula de lithium 18650, com um módulo de carregamento e manutenção da mesma, visando uma autonomia mínima de 30 dias.
Os dados recolhidos pelos sensores, interligados com o microcontrolador, são encaminhados via WiFi para um concentrador, também este composto por um microcontrolador - ESP8266.
Este concentrador está ligado à rede WiFi da clínica veterinária e envia a informação recolhida para uma base de dados.
Através de um web service, o utilizador final tem acesso a uma tabela com os dados recolhidos pelos sensores.
A Pet Universal fica encarregue do tratamento dos dados, isto é, a plataforma que permite ao utilizador final ser notificado sobre alterações do estado de cada animal e, em situações que o justifiquem, receber alertas, fica ao encargo da empresa.
A implementação desta solução permite, através dos sensores referidos acima, a recolha de uma vasta gama de informações acerca do animal, a saber: a temperatura do mesmo, períodos/qualidade de descanso, a sua atividade (fazendo referência à intensidade da mesma), batimentos cardíacos e níveis de oxigénio.
Caso a solução apresentada seja concluída, com sucesso, dentro dos prazos convencionados, a nossa equipa compromete-se a desenvolver uma aplicação móvel que permitirá a visualização dos parâmetros recolhidos pelos sensores.

### 2 Entregas/Resultados

Com este projeto ambicionamos obter uma coleira capaz de analisar os sinais vitais de animais em box hospitalares.
Uma coleira que deteta e interpreta nos animais os seus:
- Movimentos;
- Batimentos cardíacos;
- Níveis de Oxigénio no sangue;
- Temperatura.
Através do WiFi estas informações serão enviadas para uma base de dados e a Pet Universal responsabilizou-se por criar um software que processa estes dados.

### 3 Funcionalidade e Tecnologia

O produto tem como finalidade monitorizar animais em box hospitalares.
- Vai recolher os seguintes dados:
- Movimentos;
- Batimentos cardíacos e níveis de oxigénio no sangue;
- Temperatura;
Os utilizadores irão ter ao seu dispor um software, cujo a Pet Universal se responsabilizou por criar, que os irá notificar quando os limites monitorizados forem causa de preocupação.

A informação é recolhida através de uma coleira com uma bateria, composta por uma célula 18650 e uma BMS (Batery Management System) com output de 5V, um microcontrolador ESP8266 que rege os sensores:
- Acelerómetro ADXL-345 (Movimentos)
- Sensor de ritmos cardíacos e níveis de oxigenação MAX30100 (Batimentos cardíacos e Níveis de Oxigénio)
- Temperatura -> Sensor de temperatura DS18B20
Todos estes dados vão ser encaminhados pelo microcontrolador para um concentrador (Composto também por um microcontrolador ESP8266) para uma rede WiFi que este mesmo gera para obter os dados de todas as box.
Este concentrador vai estar ligado à rede WiFi do hospital e enviará os dados para uma base de dados que será posteriormente processada por um software externo.

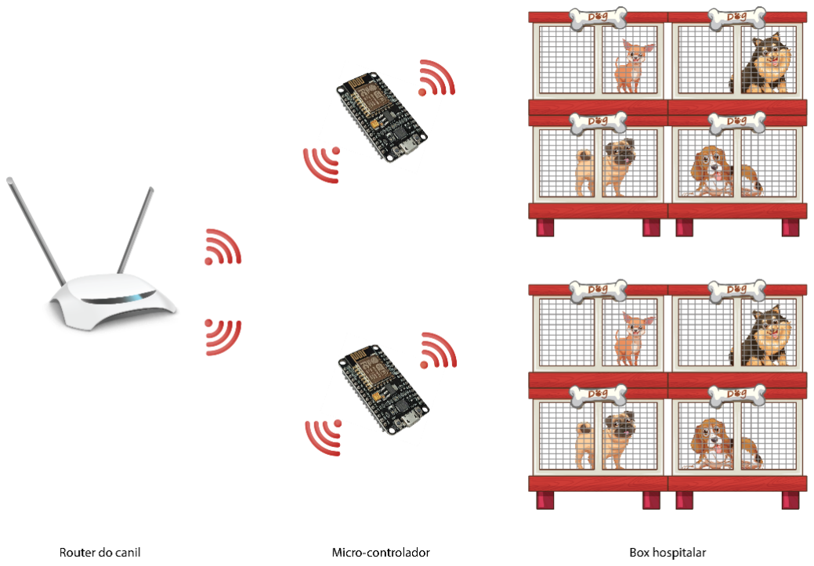
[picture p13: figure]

Figura 1 – Esquematização a ser desenvolvida num cenário real

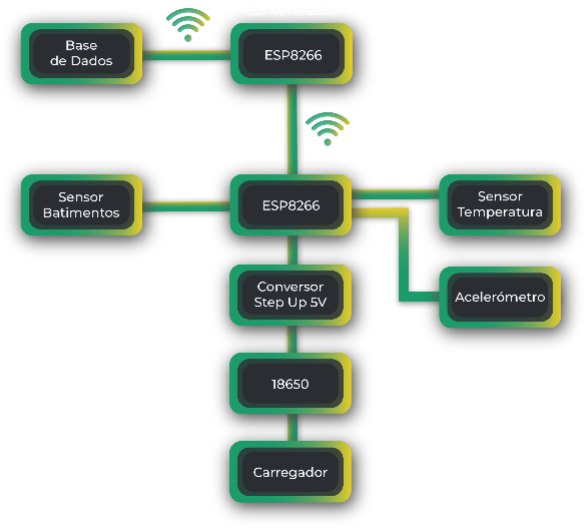
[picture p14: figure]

Figura 2 – Diagrama de blocos da solução a implementar

### 4 Cliente / Utilizadores Finais / Mercado

O cliente deste projeto é a Pet Universal, empresa dedicada ao sector veterinário, mais concretamente à gestão de centros, clínicas e hospitais veterinários. O produto a desenvolver vai ser maioritariamente usado em hospitais ou clínicas que pretendam monitorizar o estado de animais, sujeitos ou não a cirurgias, onde se mostre necessária uma vigilância durante algumas horas ou até dias. Pretendemos testar este produto presencialmente em hospitais/clínicas e entender se os dados apresentados são fidedignos para analisar o bem-estar do animal.

### 5 Parceiros

O projeto Moving Pets conta com a parceria entre duas entidades de grande prestígio: a Universidade de Aveiro e a Pet Universal.
A Universidade de Aveiro surge como a instituição que conduz os estudos dos elementos de todo o grupo. A mesma disponibiliza um docente para orientar a execução do presente projeto, realizado no âmbito da Unidade Curricular Projeto Industrial.
A Pet Universal é uma empresa de referência no sector veterinário, materializada numa plataforma modular de gestão veterinária, e foi deste parceiro que surgiu a ideia base deste projeto. Contamos com o seu apoio, quer no que respeita a financiamento de material, mas também no alinhamento e desenvolvimento do software, de forma a alinhar o nosso produto com a plataforma que vai receber e gerir os dados que estamos a recolher.
Além do referido, a Pet Universal, à semelhança da Universidade de Aveiro, disponibiliza um orientador, elemento que se mostra crucial no desenvolvimento do projeto, uma vez que tem um conhecimento ímpar sobre esta área e consegue alinhar o produto idealizado ao produto que está a ser criado efetivamente.
Como grupo, deixamos desde já, um agradecimento às duas instituições, em particular aos orientadores que as representam.

### 6 Comentários e observações

Nada a assinalar.

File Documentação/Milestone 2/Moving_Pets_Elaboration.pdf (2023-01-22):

## 42088 – Projeto Industrial

# Relatório do estado do projeto

## Milestone 2 – Elaboração

Nome do Projeto: | Moving Pets
Empresa: | Pet Universal
Orientador da Empresa: | Eng. Luís Pinto
Data: | 15/11/2022
Membros da Equipa: | Contacto principal: Bruna Pires | bruna.ramos.pires@ua.pt | +351 936 038 835 Membros do grupo: André Santos | andre.ssantos@ua.pt | +351 910 848 545 Daniel Almeida | danielba@ua.pt | +351 960 436 934 Gonçalo Martins | goncalom23@ua.pt | +351 934 554 483 João Francisco | joaofpedrosa@ua.pt | +351 962 478 430
Orientador: | Prof. Osvaldo Pacheco
Orientador de Aula: | Prof. Pedro Fonseca

## Breve sumário do estado do projeto:

Até ao momento, uma vez concluída a fase de elaboração, o projeto já possui uma arquitetura detalhada do que será a solução a ser implementada.

Além disso, a equipa de hardware, responsável pela parte de sensorização do projeto, já estabeleceu conectividade entre o microcontrolador - ESP8266 - e os três sensores aplicados no projeto:

- Sensor de temperatura;
- Sensor de ritmo cardíaco e níveis de oxigénio;
- Módulo acelerómetro.

Por sua vez, a equipa de backend, encarregue pelo desenvolvimento de um web service - que permita expor numa tabela os dados recolhidos pelos sensores - encontra-se a formular a comunicação entre dois microcontroladores - ESP8266 - e visualização em dashboard de dados recebidos.

Tendo em consideração as fases de um projeto (Inception, Elaboration, Construction e Transition), bem como os objetivos principais inerentes às mesmas, e ainda a planificação destinada ao desenvolvimento do projeto, representada no Gantt Chart (em anexo), que por sua vez foi desenvolvido na fase Inception, podemos considerar que o projeto se encontra alinhado de forma a cumprir as datas de entrega estipuladas.

No que concerne ao orçamento do projeto, este encontra-se dentro dos limites estabelecidos pela empresa Pet Universal. O orçamento contemplado tem em consideração possíveis danos em componentes, isto é, tem em conta um componente extra, caso exista algum percalço.

Como referido acima, o projeto está a decorrer como previsto. O único ponto ainda por ser decidido, prende-se com a definição do local onde serão integrados os sensores: se numa caixa ou se incorporados na coleira.

Esta questão surgiu pela eventualidade de surgirem dificuldades de comunicação entre a pulseira e o concentrador.

De forma a compreender qual a solução mais eficiente, o grupo desenvolverá os dois sistemas - caixa e coleira de Kevlar - para que seja possível testar e depreender qual irá trazer resultados mais fidedignos.

## Arquitetura

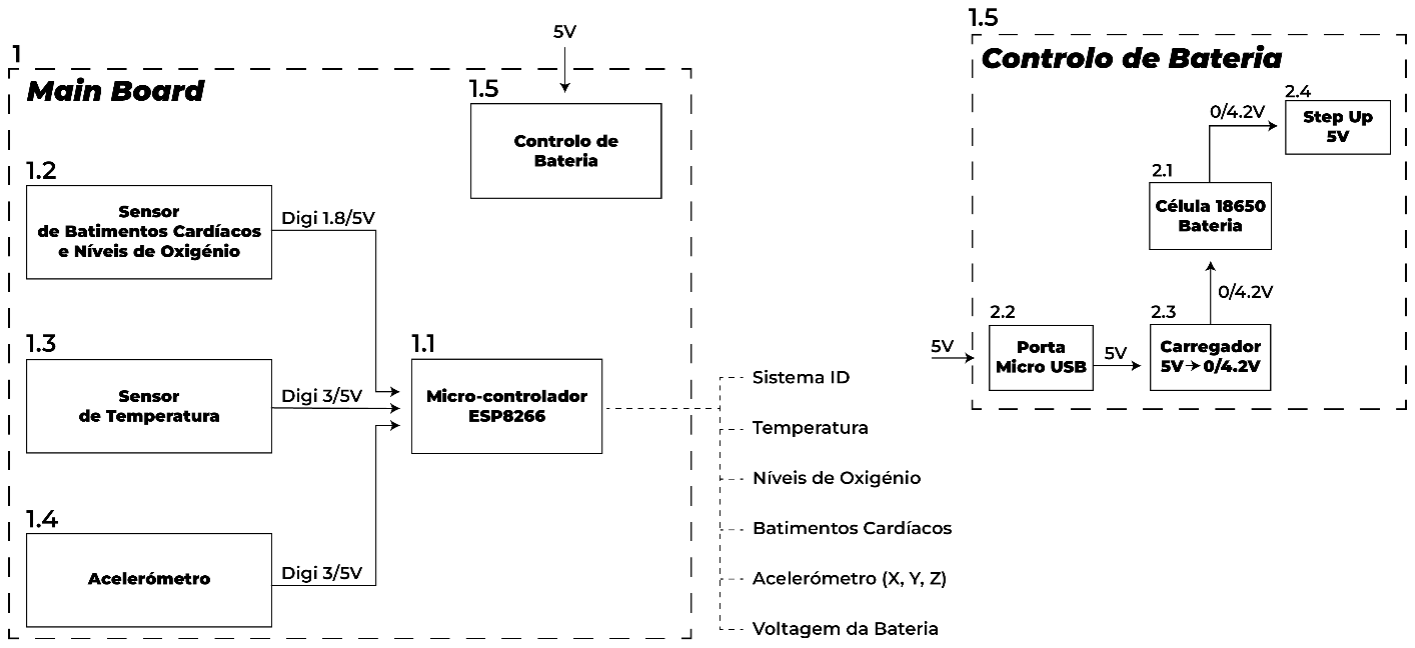
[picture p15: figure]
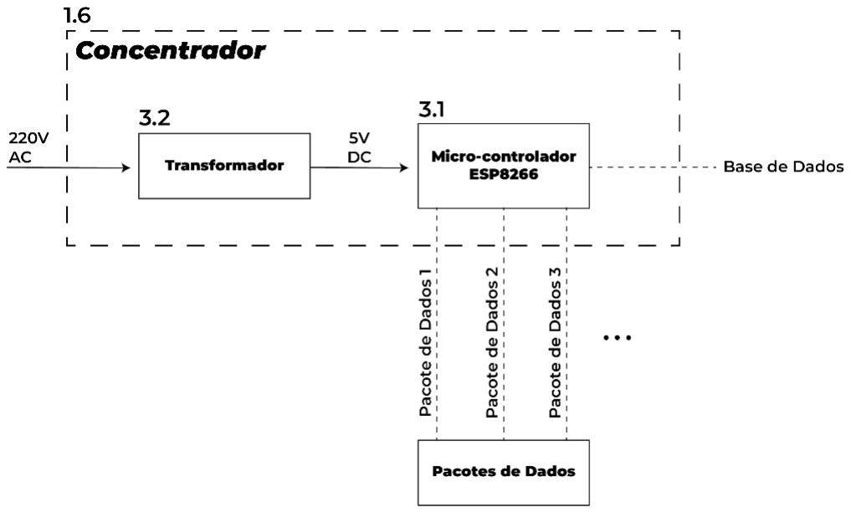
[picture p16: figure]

Figura 1 - Solução: Diagrama de Blocos

Em relação à arquitetura do sistema, contamos com dois diagramas de blocos, que correspondem ao sistema que vai estar presente na coleira do animal, e ao concentrador, que vai permitir o envio dos variados pacotes recebidos da coleira para a internet do hospital veterinário.

No fluxograma apresentado, temos os diferentes estados que o sistema empregue na coleira irá ter. Começando pelo “DeepSleep” da ESP8266 em que esta irá estar neste modo de poupança de energia durante 5 segundo, onde irá estar desligada. Após a passagem do tempo, a ESP8266 irá ligar-se, pedir valores aos sensores (Acelerómetro, Temperatura e Oxímetro) e posteriormente criar um pacote de dados que irá ser enviado por WiFi para o concentrador. De seguida, a ESP8266 irá voltar ao estado “DeepSleep”, no que resulta de 1 segundo de operação da ESP8266 no seu estado ativo, intervalado por 5 segundos inativa. Com isto, temos um consumo 192mA por dia, tendo por base que a ESP8266 irá estar ativa durante 2.4horas/dia.

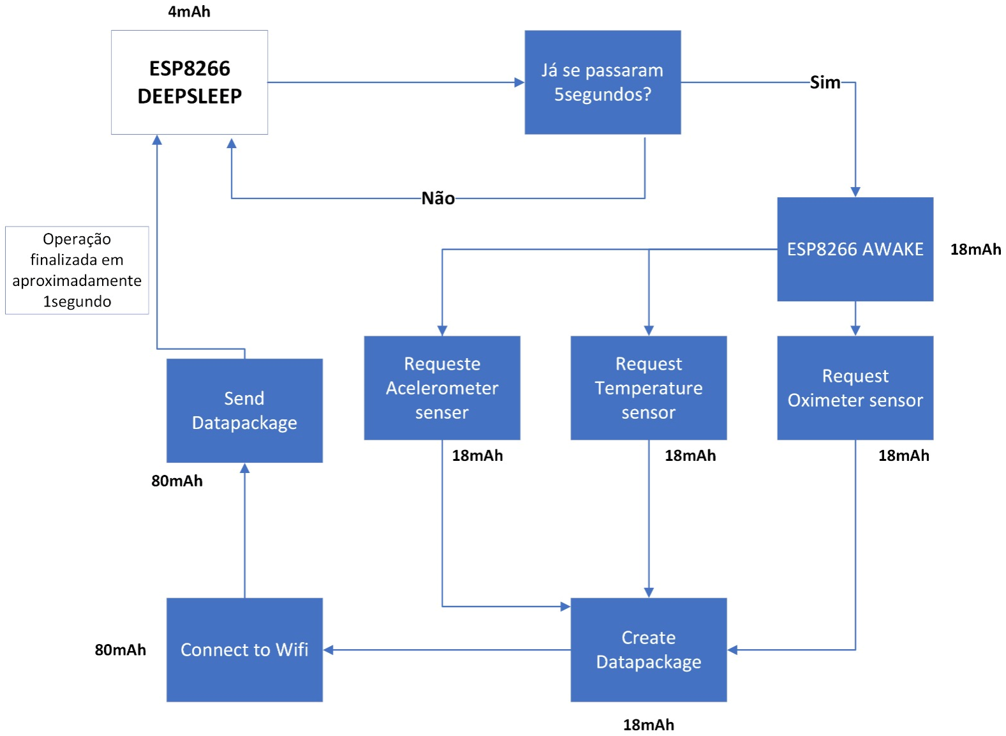
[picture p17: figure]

Figura 2 - Solução: Fluxograma

## Marcos principais

ID | Descrição | Data original para o término da tarefa | Data planeada para o término da tarefa | Data real para o término da tarefa
1 | Especificação, escolha e aquisição dos sensores | 2ª e 3ª semana de outubro | Data original | Data original
2 | Especificação do concentrador | 2ª e 3ª semana de outubro | Data original | Data original
3 | Estudo e especificação do layout da coleira | 2ª e 3ª semana de outubro | Data original | Data original
4 | Design da arquitetura do sistema: Diagrama de blocos | 4ª semana de outubro à 1ª semana de novembro | Data original | Data original

5

Implementação da componente de hardware: conectividade entre o microcontrolador (ESP8266) e os três sensores aplicados no projeto (sensor de temperatura, módulo acelerómetro e sensor de ritmo cardíaco e níveis de oxigénio)

2ª semana de
novembro à 3ª
semana de
dezembro

3ª semana de
novembro

3ª semana de
novembro
6 | Implementação do concentrador: comunicação entre microcontroladores e visualização em dashboard dos dados recebidos | 2ª semana de novembro à 3ª semana de dezembro | 3ª semana de novembro | -
7 | Interligação Backend-Hardware | 1ª, 2ª e 3ª semana de dezembro | 4ª semana de novembro à 2ª semana de dezembro | -
8 | Especificação da implementação do hardware na coleira | 1ª, 2ª e 3ª semana de dezembro | Data original | -
9 | Testes do produto | 1ª, 2ª e 3ª semana de dezembro | Data original | -
10 | Validação | 4ª semana de dezembro e 1ª semana de janeiro | Data original | -
11 | Montagem do produto | 2ª e 3ª semana de janeiro | Data original | -

## Progresso e desvio do plano

O plano inicial que o grupo idealizou para o layout da coleira, centrava-se no desenvolvimento de uma caixa que envolvia a componente de hardware, e que, posteriormente, seria integrada na coleira, como se encontra representado na figura 3. Porém, esta alternativa poderá apresentar algumas dificuldades na comunicação com o concentrador a ser desenvolvido.

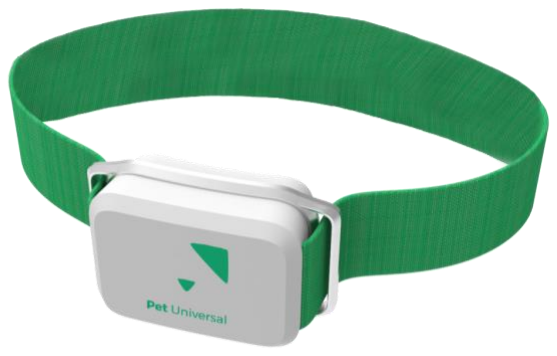
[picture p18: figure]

Figura 3 - Protótipo inicial da coleira a desenvolver

Adicionalmente, propomos também incorporar o PCB a ser desenvolvido numa coleira composta por Kevlar que, por sua vez, traz mais comodidade ao animal (Figuras 4 e 5).

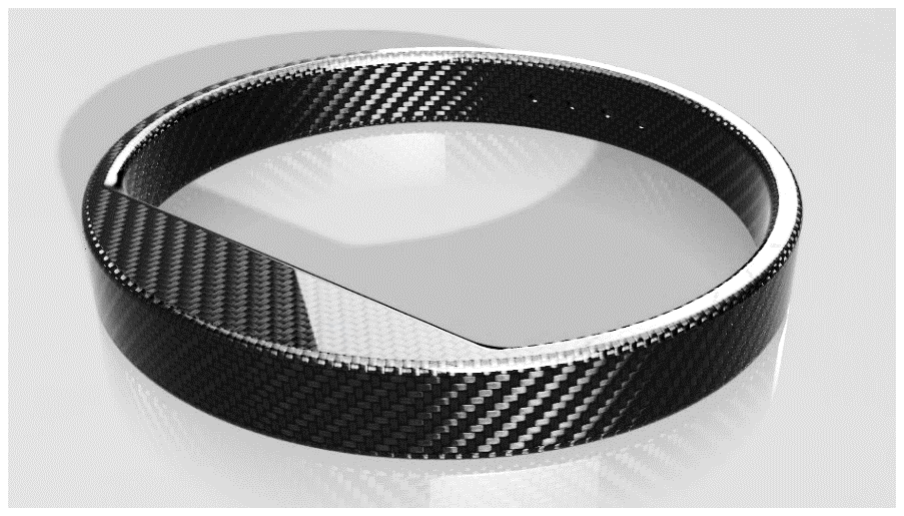
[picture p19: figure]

Figura 4 - Protótipo alternativo da coleira a desenvolver (perspetiva 1)

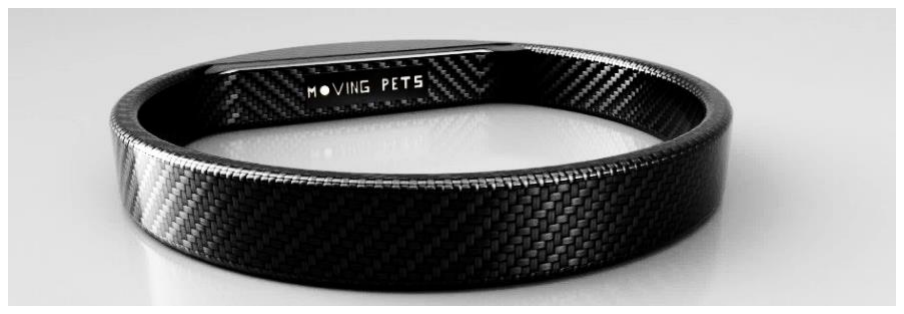
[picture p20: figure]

Figura 5 - Protótipo alternativo da coleira a desenvolver (perspetiva 2)

Uma outra opção, passa por substituir uma coleira típica por uma coleira dorsal, visto que poderá melhorar a precisão dos sensores nos animais, dado que o pelo pode interferir nos dados recolhidos.

## Plano de trabalho para a próxima iteração

Tendo em conta o trabalho desenvolvido até ao momento, a próxima etapa passa por enviar os dados recolhidos pelos sensores para o concentrador a ser implementado. Em relação à implementação do software, falta apenas registar os valores numa base de dados em tabela.

No que respeita ao protótipo da coleira, será estudada, junto do cliente, a solução a ser implementada.

Tendo em consideração o referido, já foi desenvolvido um modelo 3D da caixa a ser integrada na coleira bem como a sua especificação.

## Riscos

Em relação aos riscos, não iremos abordar os riscos de nível 4, uma vez que a probabilidade de se verificarem é muito baixa.

Começamos pelos riscos que, caso ocorram, nos vão provocar mais problemas, ou seja, os riscos de nível 2.

O primeiro ponto a referir passa pelo software de visualização dos dados recolhidos. Caso haja alguma falha de comunicação, que impossibilite o acesso aos dados dos sensores, não será possível mostrar ao cliente os dados sobre os animais. Em casos onde o animal tenha alguma necessidade de receber suporte após a cirurgia, a mesma não vai ser detetada rapidamente.

Outro risco a evidenciar é o desvio do objetivo inicial, isto é, com o decorrer dos trabalhos, o produto que se está a desenvolver não corresponder ao idealizado pelo cliente. Como forma de mitigar este risco, utilizamos o método Agile, de forma a garantir a sinergia entre o que é desenvolvido pela equipa e o que é pretendido pelo cliente.

O terceiro maior risco a abordar, passa pela existência de defeitos no software. Estes podem não ser detetados até à implementação total dos componentes, ou seja, durante os testes individuais podem funcionar como pretendido, mas quando o produto estiver concluído e for testado no ambiente real, podem surgir falhas, provenientes de fatores não considerados em testes individuais dos módulos funcionais.

De forma a colmatar situações como a descrita acima, serão efetuados testes em vários ambientes reais e será feita uma revisão do código frequente.

Apontando agora os riscos de nível 3, identificamos três riscos que vão ter influência direta no desenvolvimento do trabalho.

O primeiro prende-se com a eventualidade de ocorrer um atraso na aquisição dos componentes, o que iria provocar demora no começo dos trabalhos que, por sua vez, iria afetar a calendarização planeada. Para que não surjam percalços deste género, será tido em consideração o prazo de entrega apresentado pelos sites onde encomendamos os componentes. Além disso, optámos por criar uma margem de erro na calendarização, para minimizar o efeito de eventuais imprevistos como este.

Uma situação que pode afetar o desenvolvimento do trabalho passa por existir um (ou mais) elemento(s) com dificuldade(s) de integração na equipa, o que pode afetar o desenvolvimento do projeto. De forma a colmatar esta situação, fomentamos a mobilidade dentro do grupo, o que faz com que as funções nãos sejam definitivas e possa haver permuta entre elementos.

O último risco a evidenciar prende-se com a imprecisão dos dados recolhidos pelos sensores, o que pode resultar no envio de valores falsos para a aplicação. Uma situação deste género, além de desvalorizar o produto, trará uma vertente de incerteza e desconfiança por parte dos utilizadores, que não sabem se podem confiar nos dados apresentados. Especificando, podem pensar que está tudo bem e o animal necessita de cuidados, e o inverso. Como medida para mitigar este risco, vamos testar, sempre que possível, em ambiente real.

De seguida, são apresentadas as tabelas de gestão de riscos.

8

Tabela 1 - Análise Inicial

Análise Inicial

# | Risco | Consequência | Probabilidade | Gravidade | Nível | Solução

1 | Imprecisão dos dados recolhidos pelos sensores | Alertas errados para a aplicação | Ocasional | Marginal | 3 | Recolha de informação + Testes

### 2 Atrasos na aquisição dos componentes

Atraso no começo do trabalho que irá afeta o
ponto seguinte
| | | Ocasional | Marginal | 3

Ter em atenção o site para compra dos componentes

3 | Calendarização inadequada | Trabalho em atraso | Ocasional | Negligenciável | 3

Calendarização com margens para erro e/ou reformulação
4 | Software de visualização dos dados re- colhidos desenvolvido pela empresa (tempo útil) | Não ser possível analisar os dados
Remoto | Crítico | 2 | Feature extra: Aplicação Móvel

5

Dificuldades na integração com a
equipa

Mau ambiente durante o
trabalho
| | | Remoto | Marginal | 3 | Reformulação das equipas/elemento "móvel"

### 6 Doença Inesperada

| | Falta de funcionamento num dos componentes | Remoto | Negligenciável | 4 | Ter o trabalho sempre dentro dos prazos
7 | Desvio do objetivo inicial do trabalho | Alterações de última hora | Remoto | Crítico | 2 | Utilizar método: Agile

### 8 Mudanças Orçamentais

Não obtenção do produto
desenhado
| | | Remoto | Negligenciável | 4 | Criar um modelo de planeamento do projeto para esclarecer possíveis custos, e ir revendo regularmente o orçamento e como vão os gastos
9 | Sobrecarga/Burnout da equipa | Incumprimento de tarefas | Improvável | Marginal | 4 | Melhor divisão do trabalho
10 | Defeitos no software que poderão não ser detetados até à sua implementação | Alterações de última hora | Ocasional | Crítico | 2 | Revisões dos programas e testagens sobre qualquer ambiente

### 11 Falta de coordenação entre as equipas

| | Atraso na obtenção do produto | Remoto | Negligenciável | 4 | Calendarização bem organizada

9

Tabela 2 - Análise Riscos Residuais

Análise Riscos Residuais

Consequência | R_Likel. | R_Sever. | R_Level
Alertas com uma imprecisão de percentagem baixa | Remoto | Negligenciável | 4
Atraso ainda que menor do começa dos trabalhos | Ocasional | Negligenciável | 3
Ter de alterar datas | Remoto | Negligenciável | 4
Nem todos os dados serem possíveis para análise | Ocasional | Marginal | 3
O elemento mesmo assim não conseguir trabalhar | Improvável | Negligenciável | 4
Sobrecarga de um dos elementos | Remoto | Negligenciável | 4
Produto ligeiramente desviado do pretendido | Remoto | Negligenciável | 4
Mais tempo gasto a reorganizar | Improvável | Negligenciável | 4
Cenário de utilização inesperado | Ocasional | Marginal | 3
Equipa pode continuar a ter dificuldade a realizar a tarefa | Improvável | Negligenciável | 4

## Estado financeiro

Tabela 3 - Orçamento

# | Categoria | Descrição | Estado | Valor/un

5 | Microcontrolador | Microcontrolador com acesso ao WiFi(ESP8266) | Adquirido | 5,99 €
2 | Sensores | Módulo acelerómetro digital-3 ei-xos(ADXL-345) | Adquirido | 4,94 €
2 | Sensores | Sensor de temperatura | Adquirido | 3,70 €
2 | Sensores | Sensor de ritmo cardíaco e níveis de oxigenação | Adquirido | 7,32 €
3 | Botões e Interruptores/ Deslizantes | Interruptor deslizante 2 posições está-veis - ON-ON - 250VAC 1A (6 pinos) | Adquirido | 0,73 €
2 | Baterias | 18650 cell | Adquirido | 5,48 €
3 | Baterias e Pilhas | Bateria Lítio Polímero 3.7v 500 mAh | Adquirido | 7,66 €
3 | Carregamento de bate-rias e BMS | Módulo carregador de bateria Li-Ion 1A - entrada Micro-USB | Adquirido | 1,96 €
3 | Conversores Step Up | Módulo Boost Step Up - 0.9..4.2V para 5V - 40..480mA | Adquirido | 2,05 €
6 | Terminais | Ficha Micro-USB (fêmea) | Adquirido | 0,85 €
Total: | 115,13 €

Foi adquirido um componente de cada tipo, para que fosse possível começar a realizar testes. Nesta primeira fase foi feito um investimento total de 40,68 €.

Se a testagem apresentar resultados positivos, está planeada a aquisição dos restantes componentes, para que se possa terminar o projeto com duas coleiras funcionais, o que vai culminar no orçamento total descrito na tabela acima (Tabela 3).

## Contribuição do grupo

Membro do Grupo | Maior(es) Contribuição(ões) | Percentagem de trabalho (%)
Bruna Pires | - Desenvolvimento da documentação referente a três propostas de projetos; - Pesquisa: sensores a utilizar e métodos de implementação da solução idealizada; - Desenvolvimento da apresentação referente à Milestone 1 e Milestone 2; - Desenvolvimento do documento “Planeamento do Projeto”; - Participação no desenvolvimento do Excel “Gestão Dos Riscos”; - Participação no desenvolvimento do documento “Relatório do Estado do Projeto”; - Realização da conectividade entre o microcontrolador - ESP8266 - e o sensor de ritmo cardíaco e níveis de oxigénio e posterior testagem do mesmo. | 22%
André Santos | - Pesquisa: sensores a utilizar, métodos de implementação da solução idealizada, consumos energéticos e receção de dados com o Google Sheets; - Participação no desenvolvimento do documento “Visão do Projeto”; - Participação no desenvolvimento do Excel “Gestão Dos Riscos”; - Participação no desenvolvimento do documento “Relatório do Estado do Projeto”; - Criação de um esboço no Fusion 360 do modelo da coleira. | 19%
Daniel Almeida | - Participação no desenvolvimento do documento “Visão do Projeto”; - Participação no desenvolvimento do Excel “Gestão Dos Riscos”; - Participação no desenvolvimento do documento “Relatório do Estado do Projeto”; - Formulação da comunicação entre dois microcontroladores - ESP8266 - e visualização em dashboard de dados recebidos. | 19%
Gonçalo Martins | - Pesquisa: sensores a utilizar, métodos de implementação da solução idealizada, consumos energéticos e receção de dados com o Google Sheets; - Participação no desenvolvimento do documento “Visão do Projeto”; - Desenvolvimento dos diagramas de blocos presentes na apresentação referente Milestone 2; - Participação no desenvolvimento do documento “Relatório do Estado do Projeto”; - Realização da conectividade entre o microcontrolador - ESP8266 - e o sensor de temperatura bem como o módulo acelerómetro; - Programação do módulo ESP8266 pela IDE do Arduíno; | 21%

João
Pedrosa
- Participação no desenvolvimento do documento “Visão do Projeto”;
- Participação no desenvolvimento do Excel “Gestão Dos Riscos”;
- Participação no desenvolvimento do documento “Relatório do Estado do Projeto”;
- Formulação da comunicação entre dois microcontroladores - ESP8266 - e visualização em dashboard de dados recebidos.

19%

## Outras questões

Nada a assinalar.

## Comentários e observações

Nada a assinalar.

## Anexo 1 – Gantt Chart

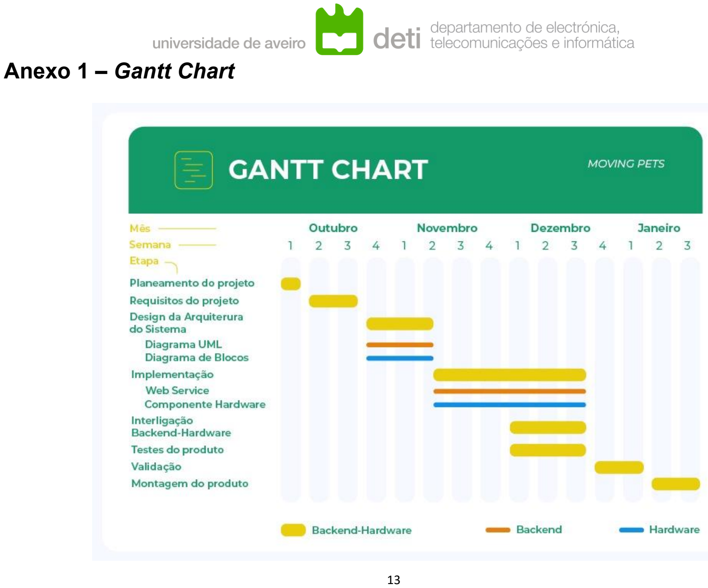
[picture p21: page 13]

13

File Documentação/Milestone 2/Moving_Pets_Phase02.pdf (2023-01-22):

# Moving Pets

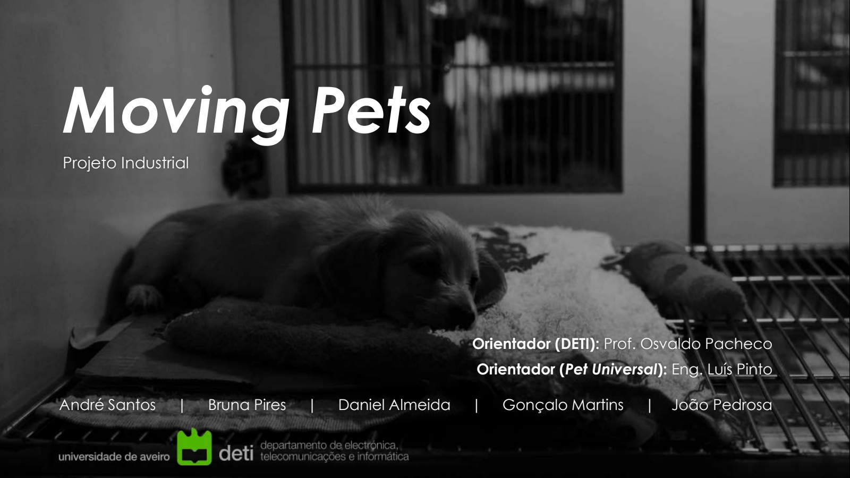
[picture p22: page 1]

Projeto Industrial

André Santos | | | Bruna Pires | | | Daniel Almeida | | | Gonçalo Martins | | João Pedrosa

Orientador (DETI): Prof. Osvaldo Pacheco Orientador (Pet Universal): Eng. Luís Pinto

# Outline

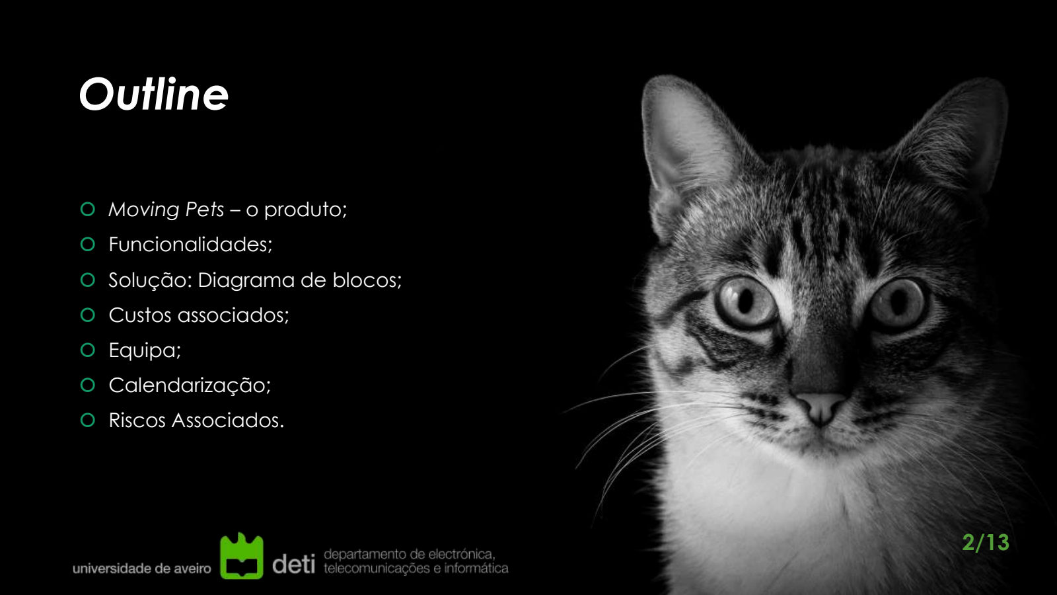
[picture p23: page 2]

- Moving Pets – o produto;
- Funcionalidades;
- Solução: Diagrama de blocos;
- Custos associados;
- Equipa;
- Calendarização;
- Riscos Associados.

2/13

# Moving Pets – o produto

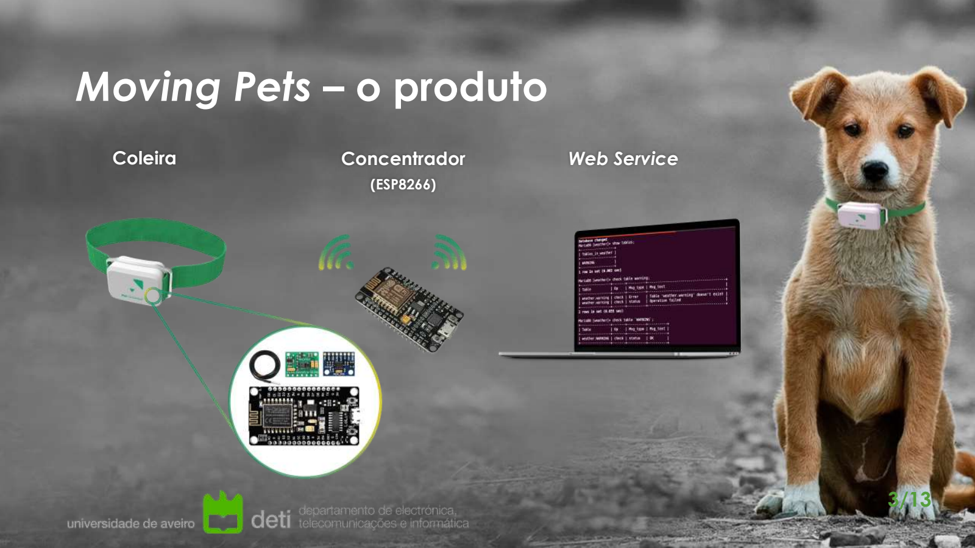
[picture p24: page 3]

Coleira | Concentrador | Web Service
| (ESP8266)

3/13

# Funcionalidades

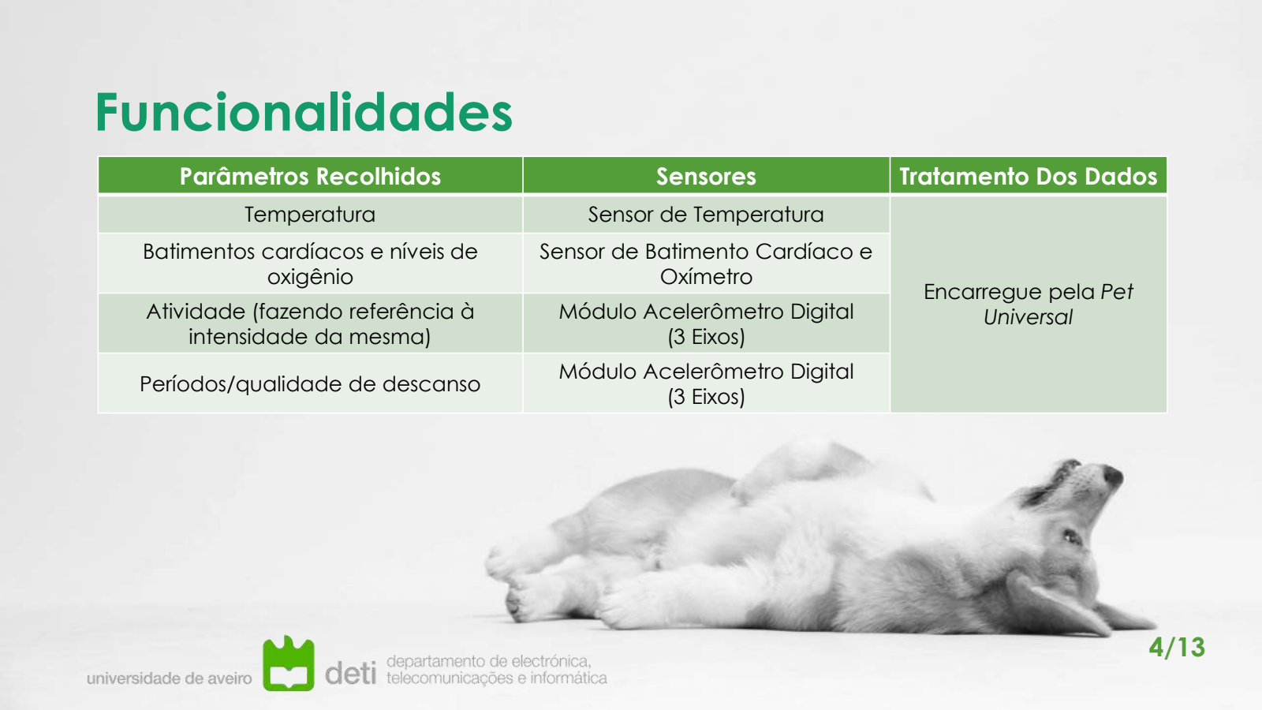
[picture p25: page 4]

Parâmetros Recolhidos | Sensores | Tratamento Dos Dados
Temperatura | Sensor de Temperatura
Batimentos cardíacos e níveis de oxigênio | Sensor de Batimento Cardíaco e Oxímetro
Atividade (fazendo referência à intensidade da mesma) | Módulo Acelerômetro Digital (3 Eixos)
Períodos/qualidade de descanso | Módulo Acelerômetro Digital (3 Eixos)

Encarregue pela Pet
Universal

4/13

# Solução: Diagrama de blocos - coleira


5/13

# Solução: Diagrama de blocos - concentrador


6/13

# Custos associados


Requisitos | Custo associado ao desenvolvimento do projeto
- Microcontrolador com acesso ao WiFi (ESP8266); • Sensores; • Interruptor; • Baterias. | Total | 143.97 €
Requisitos | Custo associado ao produto
Coleira + Concentrador | Total | 63.59 €

7/13

# Equipa


Daniel Almeida
Equipa de Backend

João Pedrosa
Equipa de Backend

Bruna Pires
Equipa de Hardware

André Santos
Equipa de Hardware

Gonçalo Martins
Equipa de Hardware

8/13

# Calendarização


Especificar
e implementar
o concentrador;

Especificar
e implementar
o software
do concentrador.

Especificar, escolher
e adquirir os sensores;

Configurar
e parametrizar
os sensores;

Estudar
e especificar
o layout da
coleira,
bem como a
implementação
das
comunicações;

Equipa
de Backend

Equipa
de Hardware

Tarefas Macro do Projeto

9/13

# Calendarização (Continuação)


10/13

## Riscos associados – processo de desenvolvimento

Riscos

Calendarização inadequada;


Sobrecarga/burnout da equipa;

Falta de coordenação entre as equipas;

Atrasos na aquisição dos componentes;

Dificuldades na integração com a equipa;

Doença inesperada;

Regresso da situação pandémica.


## Riscos associados – deficiente especificação do produto

Riscos

Resolução dos sensores a adquirir inadequada para o problema;

Software de visualização dos dados recolhidos desenvolvido pela empresa (não disponível em tempo útil);

Alterações à especificação inicial do trabalho;

Mudanças orçamentais;

Dificuldades em isolar o hardware da coleira;

Dificuldade em comunicar com o concentrador, por causa da caixa;


# Obrigado

André Santos | | | Bruna Pires | | | Daniel Almeida | | | Gonçalo Martins | | João Pedrosa

Orientador (DETI): Prof. Osvaldo Pacheco Orientador (Pet Universal): Eng. Luís Pinto

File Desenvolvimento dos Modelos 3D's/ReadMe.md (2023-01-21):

## Informações
Todas as figuras/objetos encontrados nesta pasta tem autoria do grupo, de modo a satisfazer as necessidades do mesmo no percurso do projeto.

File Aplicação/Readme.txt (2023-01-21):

A aplicação foi concebida, no Android Studio, por elementos do grupo, de modo a demonstrar os dados do projeto, vindos da ESP8266, num formato mais iterativo.

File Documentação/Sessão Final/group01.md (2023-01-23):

---
# Template para apresentação dos projetos desenvolvidos em 41686 - Projeto em Engenharia de Automação Industrial
# O template tem uma primeira parte com dados sobre o projeto. Após a linha com três traços
# ---
# começa o texto da página web do projeto.
# Não apagar a linha acima com três traços!

# Estes são os campos a adaptar para cada um dos grupos
title:      "Grupo 01 - Moving Pets"
group:      Grupo 01
projname:   Moving Pets
resumo: >- # ">-" serve para definir este campo com várias linhas até ao próximo campo (neste caso "company:")
        Quando um animal é sujeito a uma intervenção cirúrgica e há a necessidade de ficar hospitalizado, torna-se imperativo que, por parte da equipa veterinária, suceda um acompanhamento do estado de saúde do mesmo. Neste sentido, o projeto Moving Pets vem solucionar este problema, através do desenvolvimento de uma coleira capaz de medir o ritmo cardíaco, os níveis de oxigénio, a temperatura e, além disso, detetar o movimento do animal, dados que podem ser visualizados na aplicação móvel desenvolvida.

company:    Pet Universal
companyURL: https://petuniversal.com/pt-pt/

# Orientadores do projeto.
# Esta estrutura é uma lista em YAML, com o nome, email e organização (departamento da Universidade, empresa, ...) de cada orientador.
supervisors:
  - name: Osvaldo Pacheco
    email: orp@ua.pt
    organization: DETI
    organizationURL: http://www.ua.pt/DETI

  - name:  Luís Pinto
    email: luis.pinto@petuniversal.com
    organization: Pet Universal
    organizationURL: https://petuniversal.com/pt-pt/

# Team members
# Coordinator comes first
team:
- name: Bruna Pires
  email: bruna.ramos.pires@ua.pt
  role: coordinator

- name: André Santos 
  email: andre.ssantos@ua.pt
  role: developer

- name: Daniel Almeida 
  email: danielba@ua.pt
  role: developer

- name: Gonçalo Martins  
  email: goncalom23@ua.pt 
  role: developer

- name: João Pedrosa  
  email: joaofpedrosa@ua.pt
  role: developer

# Multimedia...
# Indicar nome dos ficheiros com o video do projeto e a imagem reoresentativa do projeto.
videoFilename:  Vídeo_Moving_Pets.mp4
thumbnailImage: Moving_Pets.jpg
# Não devem alterar as duas linhas seguintes (até à linha com "---")
layout: page
categories: pind
---

<!-- Info sobre o projeto -->
<!-- Não devem apagar a linha com o "include projinfo.md" -->
{% include projinfo.md %}

<!-- A partir deste ponto, e até ao final, está a descrição do vosso projeto -->

Aqui deve ir o texto completo do Projeto. Não deve repetir o que está no resumo escrito em cima.

# Desafio

O projeto Moving Pets tem como finalidade monitorizar o nível de atividade dos animais internados em box hospitalar.
Tendo esse objetivo em mente, as especificações inicias do presente projeto, centravam-se na necessidade de desenvolver uma coleira apta a medir os sinais vitais de um animal, bem como o seu nível de movimento.

# Resultados

Na sua versão final, o presente projeto é constituído por uma coleira standart, por um concentrador e por uma aplicação móvel para tablet.
A coleira acima referida foi desenvolvida com o propósito de medir o ritmo cardíaco, os níveis de oxigénio, a temperatura e, além do elencado, detetar os movimentos do animal. 
No que respeita ao concentrador, está previsto que se encontre ligado à rede WiFi da clínica veterinária e envie os dados recolhidos pelos sensores para uma base de dados, mais concretamente, para a Firebase. 
Em relação ao desenvolvimento da aplicação móvel para tablet, a mesma apresenta as seguintes páginas, a saber: página de login, escolha por parte do utilizador do concentrador sobre o qual pretende obter informações, indicação do nome do animal associado à coleira especificada e, por último, apresentação dos dados recolhidos pelos sensores em tempo real.

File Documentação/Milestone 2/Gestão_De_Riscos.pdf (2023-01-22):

# | Risk | Consequence | Likelihood | Severity | Level | Solution | Consequence | R_Likel. | R_Sever. | R_Level

1 | Imprecisão dos dados recolhidos pelos sensores | Alertas errados para a aplicação | Occasional | Marginal | 3 | Recolha de informação + Testes | Alertas com uma imprecisão de percentagem baixa | Remote | Negligible | 4
2 | Atrasos na aquisição dos componentes | Atraso no começo do trabalho que irá afeta o ponto seguinte | Occasional | Marginal | 3 | Ter em atenção o site para compra dos componentes | Atraso ainda que menor do começa dos trabalhos | Occasional | Negligible | 3
3 | Calendarização inadequada | Trabalho em atraso | Occasional | Negligible | 3 | Calendarização com margens para erro e/ou reformulação | Ter de alterar datas | Remote | Negligible | 4
4 | Software de visualização dos dados recolhidos desenvolvido pela empresa (tempo útil) | Não ser possivel analisar os dados | Remote | Critical | 2 | Feature extra: Aplicação Móvel | Nem todos os dados serem possiveis de análise | Occasional | Marginal | 3
5 | Dificuldades na integração com a equipa | Mau ambiente durante o trabalho | Remote | Marginal | 3 | Reformulação das equipas/elemento "móvel" | O elemento mesmo assim não conseguir trabalhar | Unlikely | Negligible | 4
6 | Doença Inesperada | Falta de funcionamento num dos componentes | Remote | Negligible | 4 | Ter o trabalho sempre dentro dos prazos | Sobrecarga de um dos elementos | Remote | Negligible | 4
7 | Desvio do objetivo inicial do trabalho | Alterações de última hora | Remote | Critical | 2 | Utilizar método: Agile | Ter de alterar datas | Occasional | Marginal | 3
8 | Mudanças Orçamentais | Não obtenção do produto desenhado | Remote | Negligible | 4 | Criar um modelo de planeamento do projeto para esclarecer possíveis custos,e ir revendo regularmente o orçamento e como vão os gastos | Produto ligeiramente desviado do pretendido | Remote | Negligible | 4
9 | Sobrecarga/Burnout da equipa | Incumprimento de tarefas | Unlikely | Marginal | 4 | Melhor divisão do trabalho | Mais tempo gasto a reorganizar | Unlikely | Negligible | 4
10 | Defeitos no software que poderão não ser detetados até à sua implementação | Alterações de última hora | Occasional | Critical | 2 | Revisões dos programas e testagens sobre qualquer ambiente | Cenário de utilização inesperado | Occasional | Marginal | 3
11 | Falta de coordenação entre as equipas | Atraso na obtenção do produto | Remote | Negligible | 4 | Calendarização bem organizada | Equipa pode continuar a ter dificuldade a realizar a tarefa | Unlikely | Negligible | 4
Initial analysis | Residual risk analysis

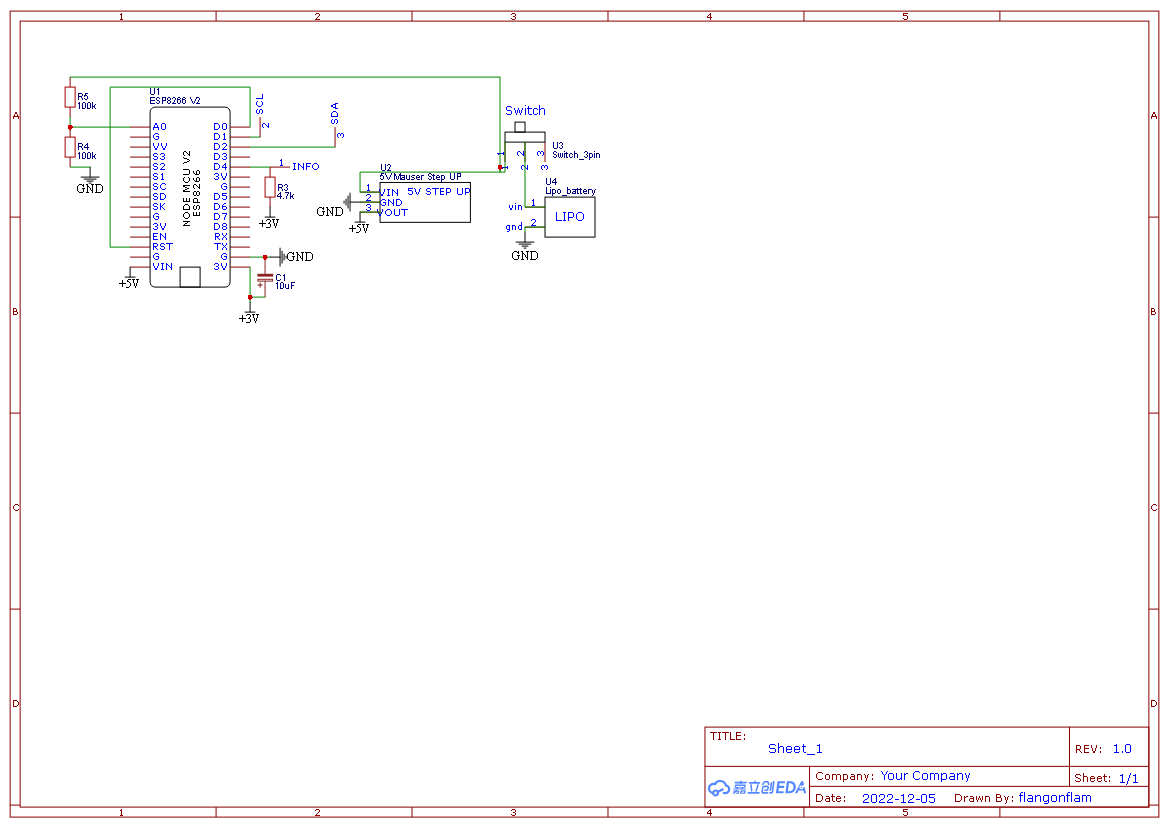
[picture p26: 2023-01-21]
Desenvolvimento do PCB/Schematic_MovingPets_ESP_2023-01-21.png

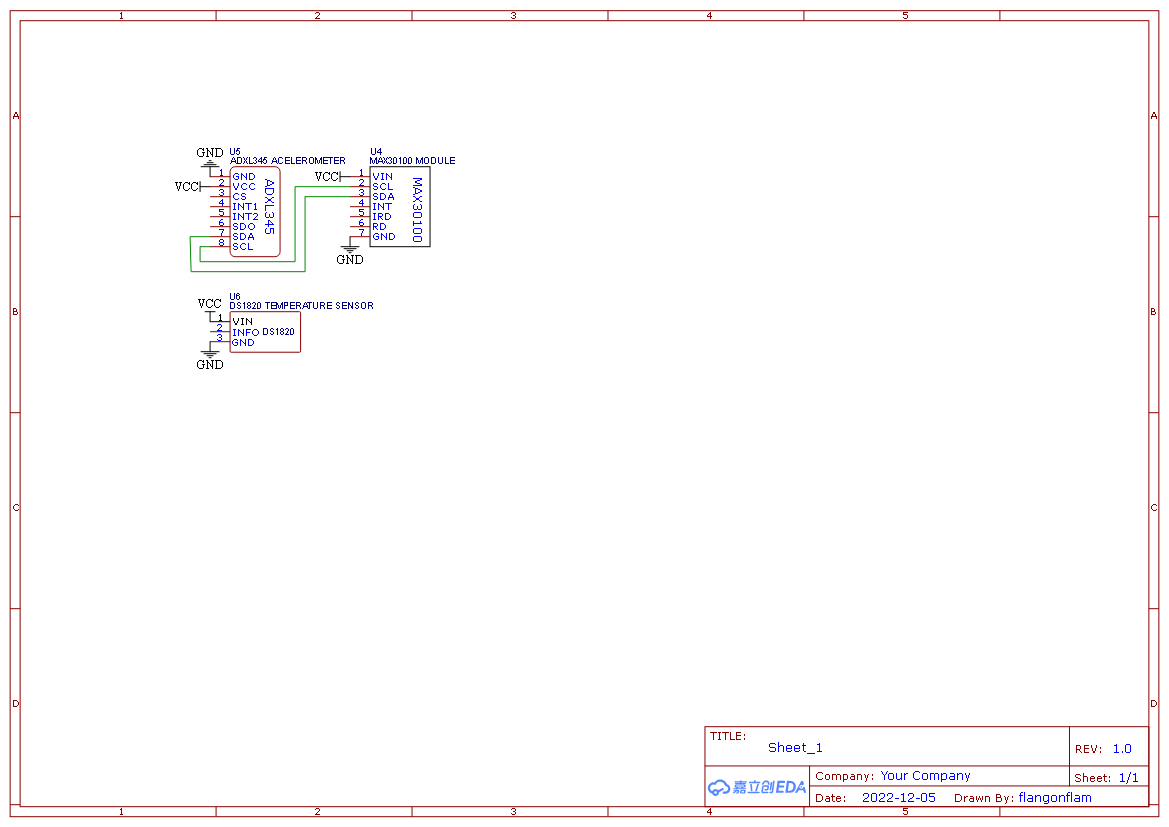
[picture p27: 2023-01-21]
Desenvolvimento do PCB/Schematic_MovingPets_Sensores_2023-01-21.png

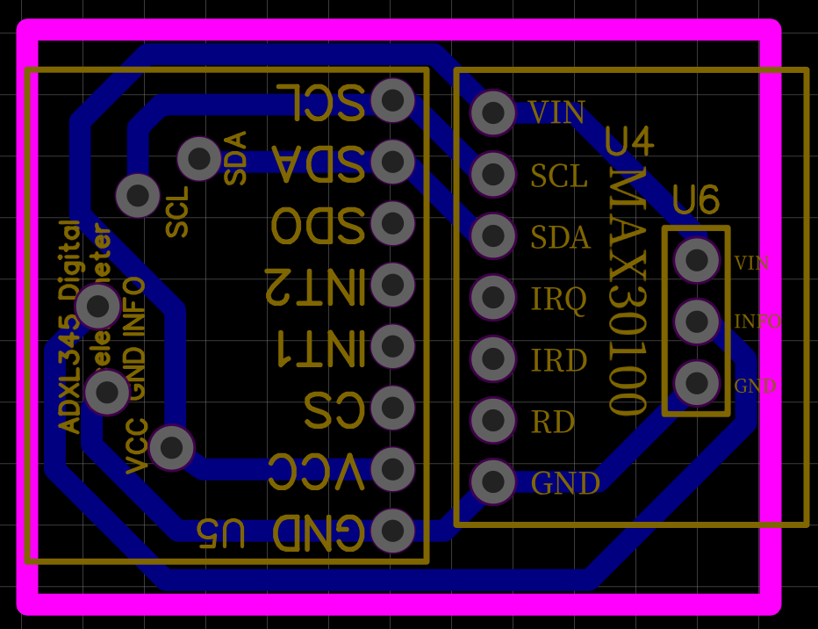
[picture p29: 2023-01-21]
Desenvolvimento do PCB/PCB_Sensores_2023-01-21.png

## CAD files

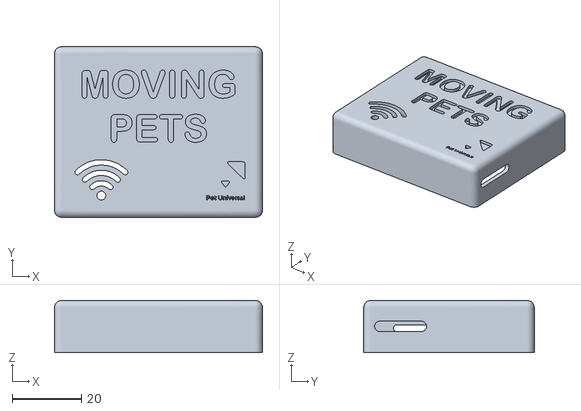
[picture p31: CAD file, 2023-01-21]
Desenvolvimento dos Modelos 3D's/Caixa Main Coleira/Box Coleira - Tampa.stl
60.0 x 49.2 x 15.0

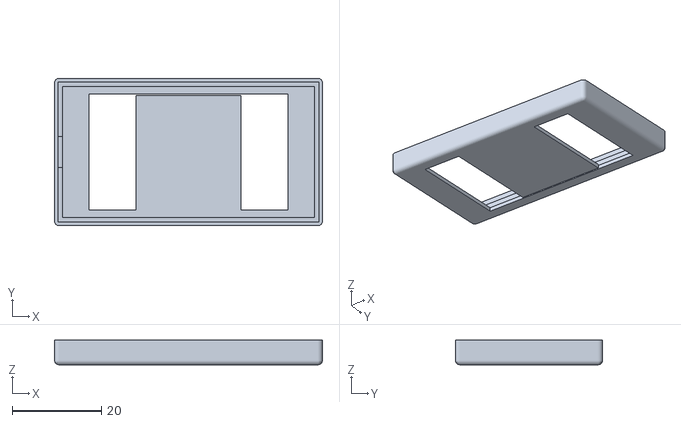
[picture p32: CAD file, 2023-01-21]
Desenvolvimento dos Modelos 3D's/Caixa Sensores Coleira/Caixa Sensores - Tampa.stl
60.0 x 33.0 x 5.50

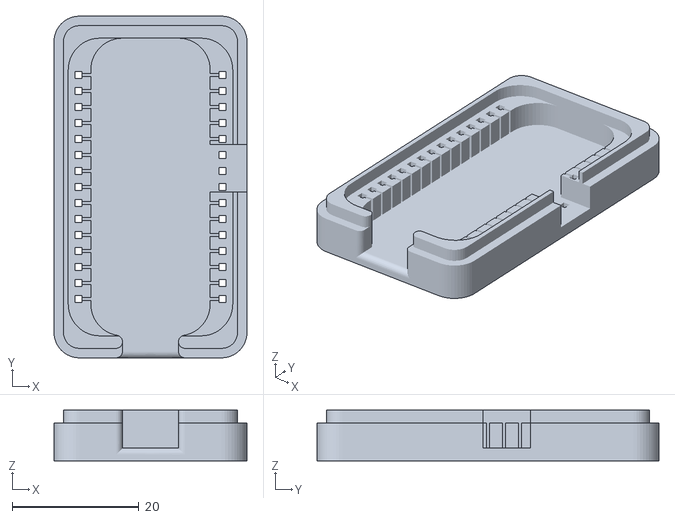
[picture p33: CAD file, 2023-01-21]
Desenvolvimento dos Modelos 3D's/Concentrador/Concentrador_Base.stl
30.5 x 54.0 x 8.00

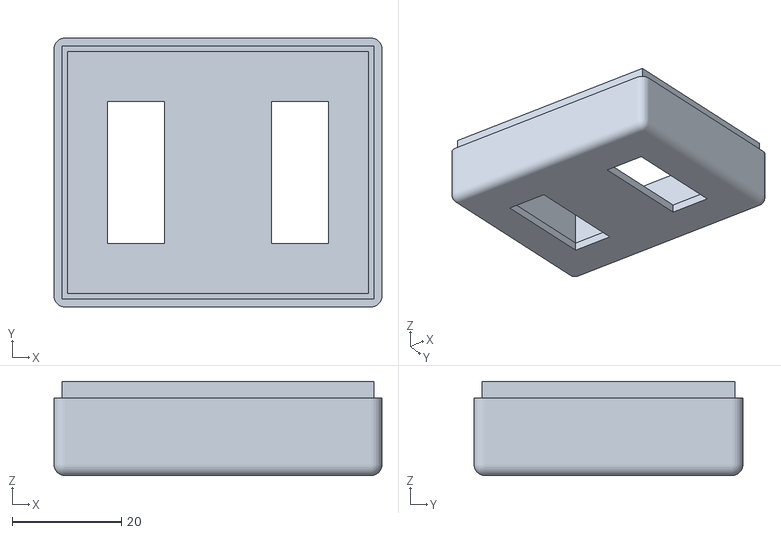
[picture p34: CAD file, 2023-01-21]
Desenvolvimento dos Modelos 3D's/Caixa Main Coleira/Box Coleira_Base.stl
60.0 x 49.2 x 17.2

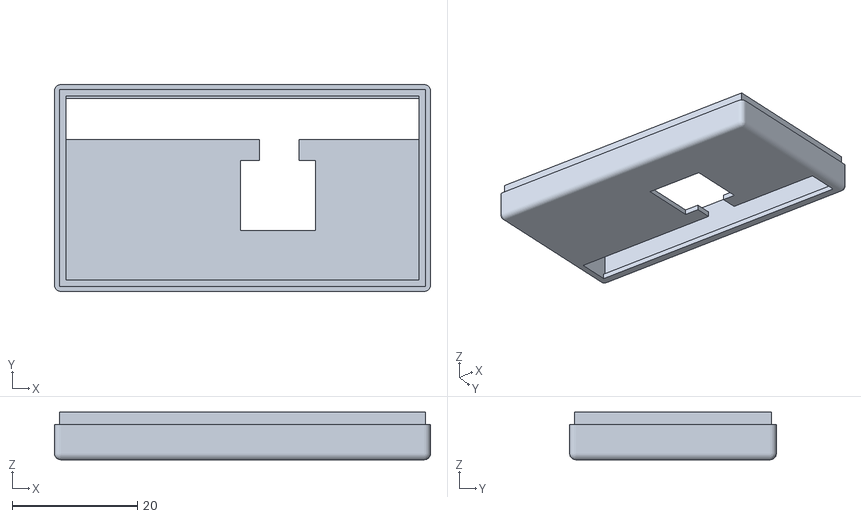
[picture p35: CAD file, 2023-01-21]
Desenvolvimento dos Modelos 3D's/Caixa Sensores Coleira/Caixa Sensores - Base.stl
60.0 x 33.0 x 7.60

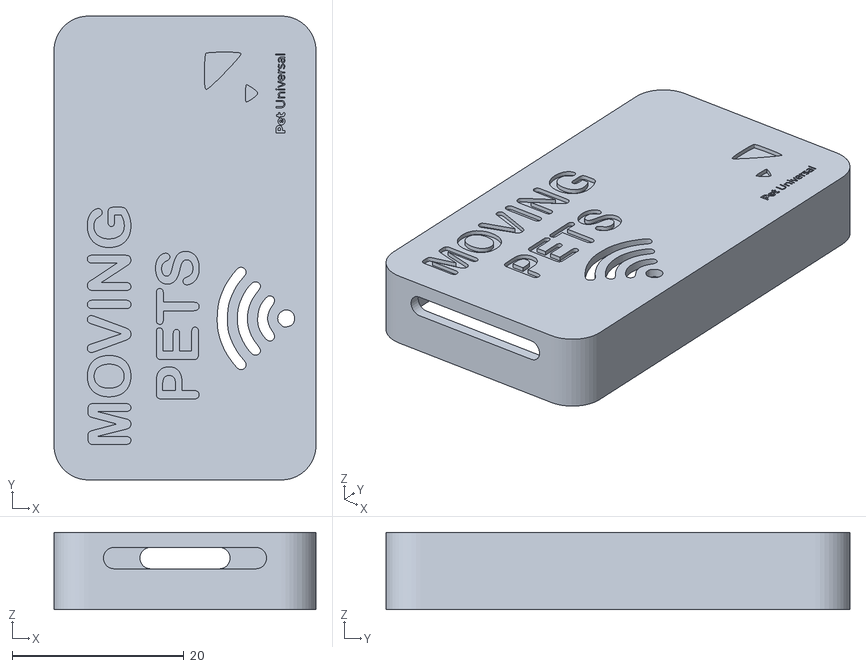
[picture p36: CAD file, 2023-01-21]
Desenvolvimento dos Modelos 3D's/Concentrador/Concentrador_Tampa.stl
30.5 x 54.0 x 9.00

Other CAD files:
Desenvolvimento dos Modelos 3D's/Caixa Main Coleira/Box Coleira - Base.f3d
Desenvolvimento dos Modelos 3D's/Caixa Main Coleira/Box Coleira - Tampa.f3d
Desenvolvimento dos Modelos 3D's/Caixa Sensores Coleira/Caixa Sensores - Base.f3d
Desenvolvimento dos Modelos 3D's/Caixa Sensores Coleira/Caixa Sensores - Tampa.f3d
Desenvolvimento dos Modelos 3D's/Concentrador/Concentrador_Base.f3d
Desenvolvimento dos Modelos 3D's/Concentrador/Concentrador_Tampa.f3d

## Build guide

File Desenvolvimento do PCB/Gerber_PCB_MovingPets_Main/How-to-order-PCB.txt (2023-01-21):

How to Order PCB

Please refer to:
https://docs.easyeda.com/en/PCB/Order-PCB

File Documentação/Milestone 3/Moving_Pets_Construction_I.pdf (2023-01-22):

## 42088 – Projeto Industrial

# Relatório do estado do projeto

## Milestone 3 – Construção I

Nome do Projeto: | Moving Pets
Empresa: | Pet Universal
Orientador da Empresa: | Eng. Luís Pinto
Data: | 07/12/2022
Membros da Equipa: | Contacto principal: Bruna Pires | bruna.ramos.pires@ua.pt | +351 936 038 835 Membros do grupo: André Santos | andre.ssantos@ua.pt | +351 910 848 545 Daniel Almeida | danielba@ua.pt | +351 960 436 934 Gonçalo Martins | goncalom23@ua.pt | +351 934 554 483 João Francisco | joaofpedrosa@ua.pt | +351 962 478 430
Orientador: | Prof. Osvaldo Pacheco
Orientador de Aula: | Prof. Pedro Fonseca

## Índice

## I. Introdução

O presente documento, referente à Milestone 3 e que engloba a primeira fase da etapa da construção, encontra-se dividido em dez secções, além da atual.

Começa-se por fazer um breve resumo, de forma a situar o leitor acerca das tarefas referentes ao projeto Moving Pets que já se encontram concluídas, para que, a partir daí, se possam aprofundar mais os detalhes inerentes ao trabalho já efetuado.

O terceiro ponto descrito, a Arquitetura, faz referência a diagramas de blocos e ao fluxograma, elementos desenvolvidos como parte da apresentação da solução idealizada para este produto.

De seguida, são apresentados os Marcos principais, englobando a explanação do progresso e desvio do plano inicial, bem como evidenciando o plano de trabalho para a próxima iteração, para que seja possível aferir, de uma forma mais detalhada, o que foi relatado no resumo previamente referido nesta secção.

O quinto tópico a abordar refere-se aos Riscos que podem afetar o desenvolvimento do trabalho previsto, provocando, em caso de ocorrência, alterações na forma como foi planeado e distribuído, quer temporalmente, quer com base nos recursos humanos disponíveis no momento inicial.

Segue-se uma análise ao orçamento apresentado na última entrega, com a respetiva retificação que se encontra detalhada e justificada no ponto Estado financeiro.

No sétimo ponto deste documento é elencado o trabalho que cada elemento da equipa desenvolveu, de uma forma mais pormenorizada, sendo possível aferir qual a contribuição individual de cada elemento para o bom desempenho que o grupo tem apresentado até ao momento.

Já numa fase final, o tópico Outras questões é utilizado para realçar algum do trabalho que foi realizado e não se enquadrou nos pontos referidos até então, como por exemplo: testes realizados em contextos reais, testes realizados em alguns animais dos elementos do grupo, visita a uma clínica veterinária e também o armazenamento e apresentação dos dados recolhidos no Google Sheets.

Por fim, o último ponto deste documento pretende evidenciar as principais conclusões a retirar do trabalho já efetuado, bem como deixar uma perspetiva clara acerca das tarefas a desenvolver até à próxima iteração.

## II. Breve sumário do estado do projeto

Até ao momento, uma vez concluída a fase de construção I, o projeto já possui um progresso significativo do que será a solução a ser implementada.

De salientar que a equipa de hardware, responsável pela parte de sensorização do projeto, já estabeleceu conectividade entre o microcontrolador - ESP8266 - e os três sensores utilizados no projeto:

- Sensor de temperatura;
- Sensor de ritmo cardíaco e níveis de oxigénio;
- Módulo acelerómetro.

Por sua vez, a equipa de backend, encarregue pelo desenvolvimento de um web service - que permita expor, numa tabela, os dados recolhidos pelos sensores - encontra-se a formular um setup que possibilite aos médicos veterinários definir o tempo de recolha de dados que considerem mais adequado.

Tendo em consideração as fases de um projeto (Inception, Elaboration, Construction e Transition), bem como os objetivos principais inerentes às mesmas, e ainda a planificação destinada ao desenvolvimento do projeto, representada no Gantt Chart (em anexo), desenvolvido na fase Inception, podemos considerar que o projeto se encontra alinhado, de forma a cumprir as datas de entrega estipuladas.

No que concerne ao orçamento do projeto, este encontra-se dentro dos limites estabelecidos pela empresa Pet Universal. O orçamento contemplado tem em consideração possíveis danos em componentes, isto é, tem em conta um componente extra, caso exista algum percalço.

Como referido acima, o projeto está a decorrer como previsto. O único ponto ainda por ser decidido, prende-se com a definição do local onde serão integradas as coleiras: se numa coleira standard ou se numa coleira dorsal.

Esta questão surgiu pela necessidade de obter informação fidedigna, proveniente dos dados recolhidos pelos sensores.

## III. Arquitetura

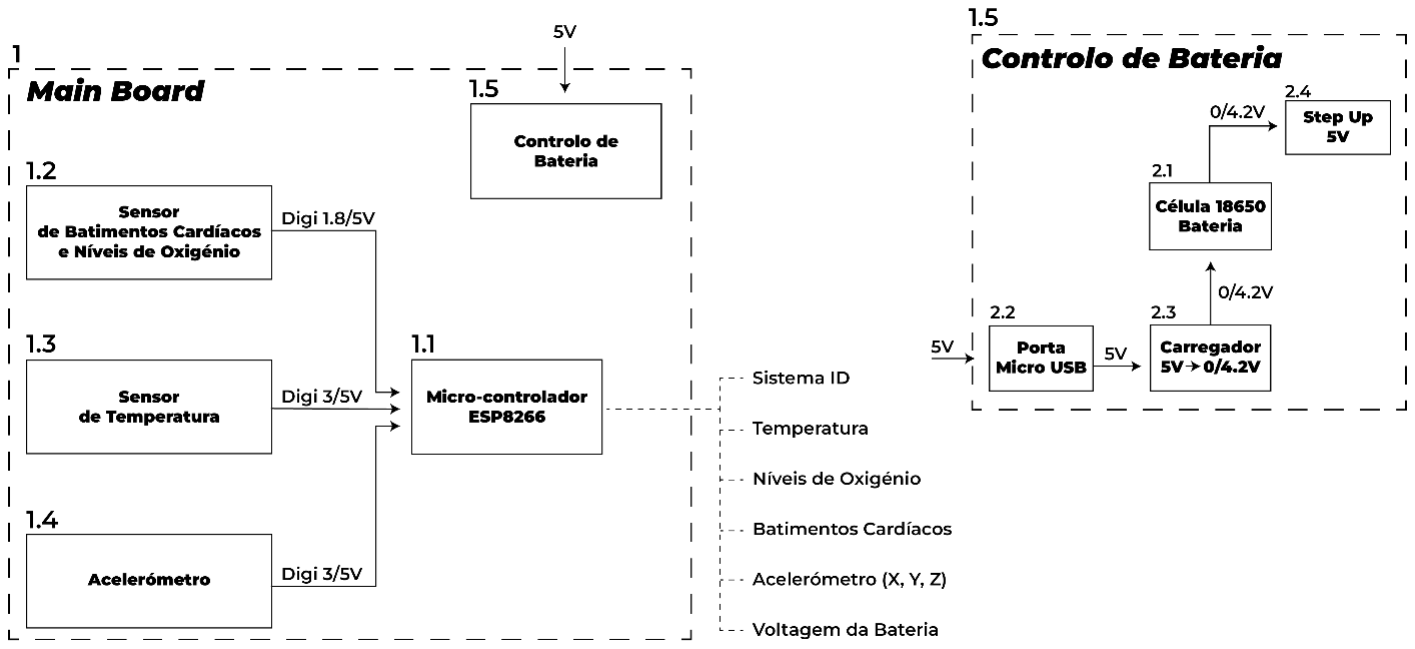
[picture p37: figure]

Figura 1 - Solução: Diagrama de Blocos

Em relação à arquitetura do sistema, contamos com dois diagramas de blocos, que correspondem ao sistema que vai estar presente na coleira do animal, e ao concentrador, que vai permitir o envio dos variados pacotes recebidos da coleira para a internet do hospital veterinário (Figura 1).

No fluxograma apresentado de seguida (Figura 2), temos os diferentes estados que o sistema empregue na coleira irá possuir.

Começamos pelo “DeepSleep” da ESP8266, que se concretiza por um modo de poupança de energia, com a duração de 5 minutos, onde esta estará desligada.

Após a passagem do tempo definido, a ESP8266 irá ligar-se, pedir valores aos sensores (Acelerómetro, Temperatura e Oxímetro) e posteriormente criar um pacote de dados que irá ser enviado via WiFi para o concentrador.

De seguida, a ESP8266 irá voltar ao estado “DeepSleep”, o que resulta num período de operação de 1 segundo no seu estado ativo, intervalado por 5 minutos inativa. Com isto, temos um consumo 192mA por dia, tendo por base que a ESP8266 irá estar ativa durante 2.4horas/dia.

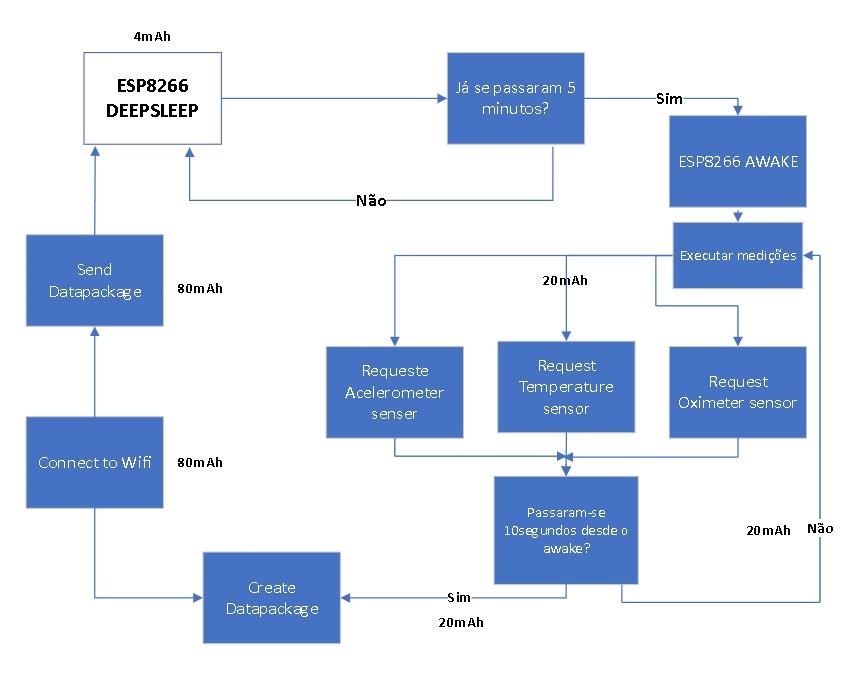
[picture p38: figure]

Figura 2 - Solução: Fluxograma

## IV. Marcos principais

ID | Descrição | Data original para o término da tarefa | Data planeada para o término da tarefa | Data real para o término da tarefa
1 | Especificação, escolha e aquisição dos sensores | 2ª e 3ª semana de outubro | Data original | Data original
2 | Especificação do concentrador | 2ª e 3ª semana de outubro | Data original | Data original
3 | Estudo e especificação do layout da coleira | 2ª e 3ª semana de outubro | Data original | Data original
4 | Design da arquitetura do sistema: Diagrama de blocos | 4ª semana de outubro à 1ª semana de novembro | Data original | Data original

5

Implementação da componente de hardware: conectividade entre o microcontrolador (ESP8266) e os três sensores aplicados no projeto (sensor de temperatura, módulo acelerómetro e sensor de ritmo cardíaco e níveis de oxigénio)

2ª semana de
novembro à 3ª
semana de
dezembro

3ª semana de
novembro

3ª semana de
novembro
6 | Implementação do concentrador: comunicação entre microcontroladores e visualização em dashboard dos dados recebidos | 2ª semana de novembro à 3ª semana de dezembro | 3ª semana de novembro | 4ª semana de novembro
7 | Interligação Backend-Hardware | 1ª, 2ª e 3ª semana de dezembro | 4ª semana de novembro à 2ª semana de dezembro | 4ª semana de novembro
8 | Especificação da implementação do hardware na coleira | 1ª, 2ª e 3ª semana de dezembro | Data original | -
9 | Testes do produto | 1ª, 2ª e 3ª semana de dezembro | Data original | -
10 | Validação | 4ª semana de dezembro e 1ª semana de janeiro | Data original | -
11 | Montagem do produto | 2ª e 3ª semana de janeiro | Data original | -

## a) Progresso e desvio do plano

No que concerne ao layout da coleira, o plano inicial que o grupo equacionou consistia no desenvolvimento de uma caixa, onde estaria contida a parte de hardware - sensores e microcontrolador, e que, posteriormente, seria integrada numa coleira standard, como se encontra representado na Figura 3.

Porém, de forma a conseguir recolher a informação mais fidedigna possível, o grupo irá também considerar o layout de uma coleira dorsal, como se encontra representado na Figura 4, fazendo com que a recolha dos dados seja feita em dois locais diferentes, e se possam fazer testes, de forma a que a escolha entre coleira standard e a coleira dorsal, para o produto final, seja feita segundo a que mostre recolher melhores resultados.

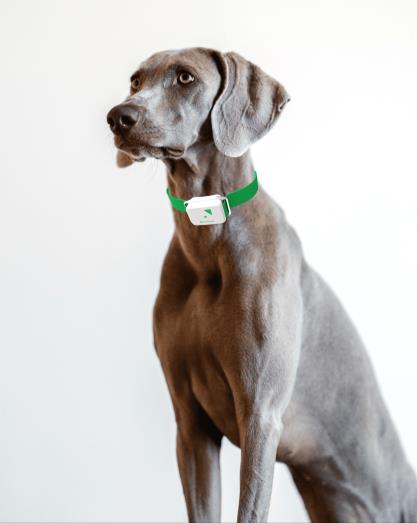
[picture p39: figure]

Figura 3 - Protótipo inicial da coleira a desenvolver

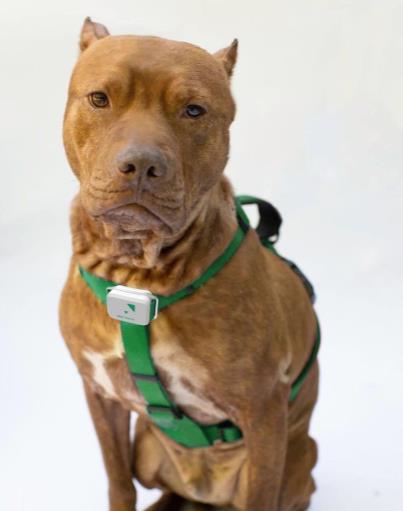
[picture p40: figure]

Figura 4 - Protótipo a considerar da coleira a desenvolver

## b) Plano de trabalho para a próxima iteração

Tendo em conta o trabalho desenvolvido até ao momento, uma das próximas etapas passa por desenvolver um setup que permita aos médicos veterinários definir o tempo de recolha de dados que pretendem, isto porque cada animal irá necessitar de um tipo de vigilância diferente.

Tendo em consideração que o hardware a ser integrado nas coleiras possui uma bateria - Li-Po - que poderá tornar-se perigosa quando possui uma baixa carga, a próxima fase passa por desenvolver um alerta para quando se verificam níveis de bateria fracos.

No que respeita ao protótipo da coleira, o desenvolvimento do modelo 3D - no Fusion 360 - da caixa a ser integrada nas coleiras está dependente da impressão do PCB, uma vez que é necessário saber as dimensões que este irá apresentar.

Em relação ao progresso da aplicação móvel para tablet, a próxima etapa foca-se no armazenamento dos dados recolhidos pelos sensores numa base de dados - Firebase - para que, posteriormente, sejam apresentados numa página, a definir, da aplicação móvel.

No que concerne ao tipo de coleira a considerar - standard ou dorsal - irão realizar-se testes em animais com características diferenciadas, nomeadamente: espécies, pelagens e dimensões.

Em última instância, irá optar-se pela opção que permita aos sensores conceder dados mais fidedignos.

## V. Riscos

Em relação aos riscos, não serão abordados os riscos de nível 4, uma vez que a probabilidade de se verificarem é muito baixa.

Iniciaremos pelos riscos que, caso ocorram, irão provocar mais problemas, ou seja, os riscos de nível 2.

O primeiro ponto a referir passa pelo software de visualização dos dados recolhidos. Caso haja alguma falha de comunicação, que impossibilite o acesso aos dados dos sensores, não será possível mostrar ao cliente os dados sobre os animais. Em casos onde o animal tenha alguma necessidade de receber suporte após a cirurgia, a mesma não vai ser detetada rapidamente.

Outro risco a evidenciar é o desvio do objetivo inicial, isto é, com o decorrer dos trabalhos, o produto que se está a desenvolver não corresponder ao idealizado pelo cliente. Como forma de mitigar este risco, utilizamos um método Agile para o desenvolvimento deste projeto, de forma a garantir a sinergia entre o que é desenvolvido pela equipa e o que é pretendido pelo cliente.

O terceiro maior risco a abordar, passa pela existência de defeitos no software. Estes podem não ser detetados até à implementação total dos componentes, ou seja, durante os testes individuais podem funcionar como pretendido, mas quando o produto estiver concluído e for testado no ambiente real, podem surgir falhas, provenientes de fatores não considerados em testes individuais dos módulos funcionais.

De forma a colmatar situações como a descrita acima, serão efetuados testes em vários ambientes reais e será feita uma revisão do código frequente.

Apontando agora os riscos de nível 3, identificamos três riscos que vão ter influência direta no desenvolvimento do trabalho.

O primeiro prende-se com a eventualidade de ocorrer um atraso na impressão do PCB desenvolvido, o que iria provocar demora no progresso dos trabalhos que, por sua vez, iria afetar a calendarização planeada. Para que não surjam percalços deste género, optámos por criar uma margem de erro na calendarização, para minimizar o efeito de eventuais imprevistos como este.

Uma situação que pode afetar o desenvolvimento do trabalho passa por existir um (ou mais) elemento(s) com dificuldade(s) de integração na equipa, o que pode afetar o desenvolvimento do projeto. De forma a colmatar esta situação, fomentamos a mobilidade dentro do grupo, o que faz com que as funções não sejam definitivas e possa haver permuta entre elementos.

O último risco a evidenciar prende-se com a imprecisão dos dados recolhidos pelos sensores, o que pode resultar no envio de valores pouco precisos para a aplicação. Uma situação deste género, além de desvalorizar o produto, trará uma vertente de incerteza e desconfiança por parte dos utilizadores, que não sabem se podem confiar nos dados apresentados. Especificando, podem pensar que está tudo bem e o animal necessita de cuidados, e o inverso. Como medida para mitigar este risco, vamos testar, sempre que possível, em ambiente real.

De seguida, são apresentadas as tabelas de gestão de riscos.

11

Tabela 1 - Análise Inicial

Análise Inicial

# | Risco | Consequência | Probabilidade | Gravidade | Nível | Solução

1 | Imprecisão dos dados recolhidos pelos sensores | Alertas errados para a aplicação | Ocasional | Marginal | 3 | Recolha de informação + Testes
2 | Calendarização inadequada | Trabalho em atraso | Ocasional | Negligenciável | 3 | Calendarização com margens para erro e/ou reformulação
3 | Software de visualização dos dados re- colhidos desenvolvido pela empresa (tempo útil) | Não ser possível analisar os dados | Remoto | Crítico | 2 | Feature extra: Aplicação Móvel

4

Dificuldades na integração com a
equipa

Mau ambiente durante o
trabalho
| | | Remoto | Marginal | 3 | Reformulação das equipas/elemento "móvel"

### 5 Doença Inesperada

| | Falta de funcionamento num dos componentes | Remoto | Negligenciável | 4 | Ter o trabalho sempre dentro dos prazos
6 | Desvio do objetivo inicial do trabalho | Alterações de última hora | Remoto | Crítico | 2 | Utilizar método: Agile

### 7 Mudanças Orçamentais

Não obtenção do produto
desenhado
| | | Remoto | Negligenciável | 4 | Criar um modelo de planeamento do projeto para esclarecer possíveis custos, e ir revendo regularmente o orçamento e como vão os gastos
8 | Sobrecarga/Burnout da equipa | Incumprimento de tarefas | Improvável | Marginal | 4 | Melhor divisão do trabalho
9 | Defeitos no software que poderão não ser detetados até à sua implementação | Alterações de última hora | Ocasional | Crítico | 2 | Revisões dos programas e testagens sobre qualquer ambiente

### 10 Falta de coordenação entre as equipas

| | Atraso na obtenção do produto | Remoto | Negligenciável | 4 | Calendarização bem organizada

12

Tabela 2 - Análise Riscos Residuais

Análise Riscos Residuais

Consequência | R_Likel. | R_Sever. | R_Level
Alertas com uma imprecisão de percentagem baixa | Remoto | Negligenciável | 4
Ter de alterar datas | Remoto | Negligenciável | 4
Nem todos os dados serem possíveis para análise | Ocasional | Marginal | 3
O elemento mesmo assim não conseguir trabalhar | Improvável | Negligenciável | 4
Sobrecarga de um dos elementos | Remoto | Negligenciável | 4
Produto ligeiramente desviado do pretendido | Remoto | Negligenciável | 4
Mais tempo gasto a reorganizar | Improvável | Negligenciável | 4
Cenário de utilização inesperado | Ocasional | Marginal | 3
Equipa pode continuar a ter dificuldade a realizar a tarefa | Improvável | Negligenciável | 4

## VI. Estado financeiro

Tabela 3 - Orçamento

# | Categoria | Descrição | Estado | Valor/un

4 | Microcontrolador | Microcontrolador com acesso ao WiFi (ESP8266) | Adquirido | 5,99 €
2 | Sensores | Módulo acelerómetro digital-3 eixos (ADXL-345) | Adquirido | 4,94 €
2 | Sensores | Sensor de temperatura | Adquirido | 3,70 €
2 | Sensores | Sensor de ritmo cardíaco e níveis de oxigenação | Adquirido | 7,32 €
2 | Botões e Interrupto-res/ Deslizantes | Interruptor deslizante 2 posições estáveis - ON-ON -250VAC 1A (6 pinos) | Adquirido | 0,73 €
1 | Baterias | 18650 cell | Adquirido | 5,48 €
2 | Baterias e Pilhas | Bateria Lítio Polímero 3.7v 500 mAh | Adquirido | 7,66 €
3 | Carregamento de ba-terias e BMS | Módulo carregador de bateria Li-Ion 1A - entrada Mi-cro-USB | Adquirido | 1,96 €
3 | Conversores Step Up | Módulo Boost Step Up - 0.9..4.2V para 5V -40..480mA | Adquirido | 2,05 €
6 | Terminais | Ficha Micro-USB (fêmea) | Adquirido | 0,85 €
Total: | 95,27 €

Foi adquirido um componente de cada tipo, para que fosse possível começar a realizar testes. Nesta primeira fase foi feito um investimento total de 45,27 €.

Após a aquisição anteriormente referida, no momento da montagem, em placa branca, da componente de hardware, o grupo deparou-se com dois componentes não funcionais, o que originou a necessidade de encomendar, novamente, esses componentes - módulo carregador de bateria Li-Ion 1A e módulo Boost Step Up.

Relativamente à bateria das coleiras, o grupo adquiriu, na primeira fase de compras, uma bateria 18650, porém optou-se pela escolha de uma bateria Li-Po ao invés da referida anteriormente, uma vez que o peso destas é um fator a ter em conta, não podendo este apresentar um valor significativo, já que nos referimos a uma coleira destinada a animais.

Desta forma, até ao momento, foi realizado um investimento total de 60,61 € (45,27 € + 15,34 €).

Se a testagem apresentar resultados positivos, está planeada a aquisição dos restantes componentes, para que se possa terminar o projeto com duas coleiras funcionais bem como dois concentradores, o que vai culminar no orçamento total descrito na tabela acima (Tabela 3).

## VII. Contribuição do grupo

Membro do

Grupo | Maior(es) Contribuição(ões) | Percentagem de trabalho (%)

Bruna Pires

Fase Inicial até à fase de Elaboração, inclusive:
- Desenvolvimento da documentação referente a três propostas de projetos;
- Pesquisa: sensores a utilizar e métodos de implementação da solução idealizada;
- Desenvolvimento da apresentação referente à Milestone 1 e Milestone 2;
- Desenvolvimento do documento “Planeamento do Projeto”;
- Participação no desenvolvimento do Excel “Gestão Dos Riscos”;
- Participação no desenvolvimento do documento “Relatório do Estado do Projeto”;
- Realização da conectividade entre o microcontrolador - ESP8266 - e o sensor de ritmo cardíaco e níveis de oxigénio e posterior testagem do mesmo.
Fase de Construção I:
- Desenvolvimento da apresentação referente à Milestone 3;
- Participação no desenvolvimento de testes em animais do hardware a ser implementado nas coleiras;
- Desenvolvimento de uma aplicação móvel para tablet;
- Desenvolvimento do documento “Relatório do Estado do Projeto”.

22%

André
Santos

Fase Inicial até à fase de Elaboração, inclusive:
- Pesquisa: sensores a utilizar, métodos de implementação da solução idealizada, consumos energéticos e receção de dados com o Google Sheets;
- Participação no desenvolvimento do documento “Visão do Projeto”;
- Participação no desenvolvimento do Excel “Gestão Dos Riscos”;
- Participação no desenvolvimento do documento “Relatório do Estado do Projeto”;
- Criação de um esboço no Fusion 360 do modelo da coleira.
Fase de Construção I:
- Participação no desenvolvimento do modelo 3D da caixa do concentrador no Fusion 360;
- Participação no desenvolvimento de testes em animais do hardware a ser implementado nas coleiras.

19%

Daniel
Almeida

Fase Inicial até à fase de Elaboração, inclusive:
- Participação no desenvolvimento do documento “Visão do Projeto”;
- Participação no desenvolvimento do Excel “Gestão Dos Riscos”;
- Participação no desenvolvimento do documento “Relatório do Estado do Projeto”;
- Formulação da comunicação entre dois microcontroladores - ESP8266 - e visualização em dashboard de dados recebidos.
Fase de Construção I:
- Participação no desenvolvimento do PCB no Fusion 360.

19%

Membro do

Grupo | Maior(es) Contribuição(ões) | Percentagem de trabalho (%)

Gonçalo
Martins

Fase Inicial até à fase de Elaboração, inclusive:
- Pesquisa: sensores a utilizar, métodos de implementação da solução idealizada, consumos energéticos e receção de dados com o Google Sheets;
- Participação no desenvolvimento do documento “Visão do Projeto”;
- Desenvolvimento dos diagramas de blocos presentes na apresentação referente Milestone 2;
- Participação no desenvolvimento do documento “Relatório do Estado do Projeto”;
- Realização da conectividade entre o microcontrolador - ESP8266 - e o sensor de temperatura bem como o módulo acelerómetro;
- Programação do módulo ESP8266 pela IDE do Arduíno;
Fase de Construção I:
- Participação no desenvolvimento do modelo 3D da caixa do concentrador no Fusion 360;
- Impressão 3D do modelo desenvolvido da caixa do concentrador;
- Participação no desenvolvimento de testes em animais do hardware a ser implementado nas coleiras.

21%

João
Pedrosa

Fase Inicial até à fase de Elaboração, inclusive:
- Participação no desenvolvimento do documento “Visão do Projeto”;
- Participação no desenvolvimento do Excel “Gestão Dos Riscos”;
- Participação no desenvolvimento do documento “Relatório do Estado do Projeto”;
- Formulação da comunicação entre dois microcontroladores - ESP8266 - e visualização em dashboard de dados recebidos.
Fase de Construção I:
- Participação no desenvolvimento do PCB no Fusion 360;
- Participação no desenvolvimento de testes em animais do hardware a ser implementado nas coleiras.

19%

## VIII. Outras questões

No decorrer da primeira fase de construção, o grupo testou o hardware desenvolvido que, posteriormente, será implementado nas coleiras. Esta ação teve como finalidade verificar a operacionalidade dos sensores, bem como a precisão dos dados recolhidos, quando empregues em animais.

Para isso, o primeiro teste realizado teve como cobaia uma gata de seis meses. O hardware implementado em placa branca, constituído por um microcontrolador - ESP8266 - e três sensores, foi aproximado junto do pescoço do animal e os dados recolhidos pelos sensores foram armazenados e apresentados num Google Sheets concretizado para o efeito – [Testes] - Coleira. (https://uapt33090-my.sharepoint.com/:f:/g/personal/bruna_ramos_pires_ua_pt/EoT96MfmKVpOvyAZ0qaJJScBB-0CUR4OS664QRZ63gWRUQ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)

Alternativamente, o hardware foi aproximado na região tórax do animal a fim de verificar a variação dos dados recolhidos, permitindo concluir em que zona os dados se mostravam mais fidedignos e estáveis.

O resultado destes testes teve parecer positivo, porém o grupo quis generalizar mais esta testagem, por isso deslocou-se até ao Hospital Veterinário de Aveiro. Este contexto permitiu que o grupo realiza-se ensaios, tanto em cães, como em gatos, com características diferenciadas, tais como: pelagens e dimensões.

Em suma, este primeiro período de testagens permitiu concluir que os dados recolhidos pelos sensores são mais satisfatórios quando são retirados junto do pescoço do animal, ou seja, existe a propensão de uma coleira standard para o protótipo do produto final.

## IX. Comentários e observações

Nada a assinalar.

## X. Conclusões

Dado o atual progresso deste projeto, pode-se aferir que os objetivos essenciais, propostos numa fase inicial, vão ser cumpridos com sucesso.

De uma forma mais detalhada, o facto de já ser possível recolher dados com valores credíveis provenientes de todos os sensores, de conseguir que estes comuniquem eficazmente com o concentrador e de armazenar e apresentar esses mesmos dados (no Google Sheets), todos estes fatores espelham o bom rumo do trabalho efetuado, até ao momento.

No seguimento do anteriormente referido, os avanços significativos alcançados pela equipa, fazem com que seja possível alocar alguns dos elementos a tarefas distinguidas inicialmente como secundárias, com vista a aumentar a utilidade e o valor do produto que se está a desenvolver, no seu mercado alvo.

Segue-se uma fase onde o protótipo a ser utilizado nos testes se aproxima bastante do que será o produto final, o que vai ser um fator relevante e benéfico aquando da realização desses mesmos testes, uma vez que vai permitir que praticamente todos os fatores sejam semelhantes a um contexto real, em detrimento do que aconteceu nos testes realizados anteriormente, por exemplo, onde o facto dos sensores estarem alocados a uma placa branca, tornava os testes mais difíceis para o grupo e para os animais também, já que requeria que estes se encontrassem quietos e é de conhecimento geral a dificuldade que é conseguir esse cenário.

Uma vez que se consiga ter o hardware condensado com PCB's, dentro das devidas caixas e colocadas em coleiras, todo o produto vai ser submetido a um conjunto final de testes, para os quais a equipa se encontra bastante otimista, uma vez que os resultados obtidos até este momento foram bastante favoráveis.

## XI. Anexos Anexo 1 – Gantt Chart

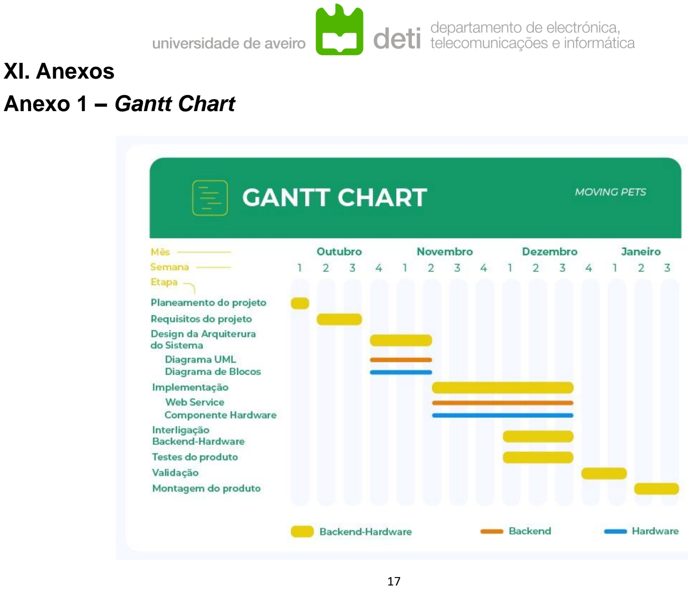
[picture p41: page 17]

17

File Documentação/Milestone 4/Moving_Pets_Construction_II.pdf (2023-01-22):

## 42088 – Projeto Industrial

# Relatório do estado do projeto

## Milestone 4 – Construção II

Nome do Projeto: | Moving Pets
Empresa: | Pet Universal
Orientador da Empresa: | Eng. Luís Pinto
Data: | 04/01/2023
Membros da Equipa: | Contacto principal: Bruna Pires | bruna.ramos.pires@ua.pt | +351 936 038 835 Membros do grupo: André Santos | andre.ssantos@ua.pt | +351 910 848 545 Daniel Almeida | danielba@ua.pt | +351 960 436 934 Gonçalo Martins | goncalom23@ua.pt | +351 934 554 483 João Francisco | joaofpedrosa@ua.pt | +351 962 478 430
Orientador: | Prof. Osvaldo Pacheco
Orientador de Aula: | Prof. Pedro Fonseca

## Índice

## I. Introdução

Atualmente, em situações onde um animal é sujeito a uma intervenção cirúrgica e se mostra necessário ficar hospitalizado, surge a necessidade, por parte da equipa veterinária, de verificar regularmente o estado de saúde destes seres, para garantir que está tudo bem com eles e acompanhar a sua evolução.

Neste sentido, o projeto Moving Pets vem solucionar este problema, uma vez que permitirá a monitorização do nível de atividade dos animais internados em box hospitalar.

Com o referido em mente, a solução idealizada pelo grupo é baseada na implementação de uma coleira com um microcontrolador - ESP8266 - e um conjunto de sensores, tais como: temperatura, batimentos cardíacos e níveis de oxigénio, como também um módulo acelerómetro digital. No que respeita à bateria, será utilizada uma Li-Po, que visa uma autonomia mínima de, aproximadamente, 5 dias.

Os dados recolhidos pelos sensores, face à interligação que terão com o microcontrolador, serão encaminhados via WiFi para um concentrador, também este composto por um microcontrolador - ESP8266.

Este concentrador irá estar ligado à rede WiFi da clínica veterinária e enviará os dados para uma base de dados (Firebase).

Através de uma aplicação móvel para tablet, o utilizador final terá acesso aos valores dos dados recolhidos pelos sensores.

O presente documento, referente à Milestone 4, aborda o progresso no desenvolvimento do projeto até ao momento e engloba a segunda fase da etapa da construção, encontrando-se dividido em dez secções, além da atual.

Começa-se por fazer um breve resumo, de forma a situar o leitor acerca das tarefas referentes ao projeto Moving Pets que já se encontram concluídas, para que, a partir daí, se possam aprofundar mais os detalhes inerentes ao trabalho já efetuado.

O terceiro ponto descrito, a Arquitetura, faz referência a diagramas de blocos e ao fluxograma, elementos desenvolvidos como parte da apresentação da solução idealizada para este produto.

De seguida, são apresentados as Tarefas especificadas (Calendarização vs. Implementação), englobando a explanação do progresso e desvio do plano inicial, bem como evidenciando o plano de trabalho para a próxima iteração, para que seja possível aferir, de uma forma mais detalhada, o que foi relatado no resumo previamente referido nesta secção.

O quinto tópico a abordar refere-se aos Riscos que podem afetar o desenvolvimento do trabalho previsto, provocando, em caso de ocorrência, alterações na forma como foi planeado e distribuído, quer temporalmente, quer com base nos recursos humanos disponíveis no momento inicial.

Segue-se uma análise ao orçamento apresentado na última entrega, com a respetiva retificação que se encontra detalhada e justificada no ponto Estado financeiro.

No sétimo ponto deste documento é elencado o trabalho que cada elemento da equipa desenvolveu, de uma forma mais pormenorizada, sendo possível aferir qual a contribuição individual de cada elemento para o bom desempenho que o grupo tem apresentado até ao momento.

Já numa fase final, o tópico Outras questões é utilizado para realçar algum do trabalho que foi realizado e não se enquadrou nos pontos referidos até então, como por exemplo: testes realizados em contextos reais, testes realizados em alguns animais dos elementos do grupo, visita a uma clínica veterinária e também o armazenamento e apresentação dos dados recolhidos no Google Sheets.

Por fim, o último ponto deste documento pretende evidenciar as principais conclusões a retirar do trabalho já efetuado, bem como deixar uma perspetiva clara acerca das tarefas a desenvolver até à próxima iteração.

## II. Breve sumário do estado do projeto

Até ao momento, uma vez concluída a fase de construção II, o projeto já possui um progresso significativo do que será a solução a ser implementada.

De salientar que a equipa de hardware, responsável pela parte de sensorização do projeto, já estabeleceu conectividade entre o microcontrolador - ESP8266 - e os três sensores utilizados no projeto:

- Sensor de temperatura;
- Sensor de ritmo cardíaco e níveis de oxigénio;
- Módulo acelerómetro.

Porsua vez, a equipa de backend, encarregue pelo desenvolvimento de um web service - que permita expor, numa tabela, os dados recolhidos pelos sensores - encontra-se a formular um setup que possibilite aos médicos veterinários definir o tempo de recolha de dados que considerem mais adequado.

Além do referido acima, esta equipa encontra-se simultaneamente a desenvolver um alerta para bateria fraca.

No que concerne ao progresso do desenvolvimento da aplicação móvel para tablet, até ao momento, a mesma apresenta as seguintes páginas, a saber:

- Página de Login;
- Escolha do concentrador sobre o qual o utilizador pretende obter informações;
- Indicação do nome do animal associado à coleira especificada;
- Apresentação dos dados recolhidos pelos sensores.

No que diz respeito ao modelo 3D da caixa a incorporar na coleira, este já se encontra elaborado, com o auxílio do Fusion 360, porém, até ao momento, não se encontra impresso.

Tendo em consideração as fases de um projeto (Inception, Elaboration, Construction e Transition), bem como os objetivos principais inerentes às mesmas, e ainda a planificação destinada ao desenvolvimento do projeto, representada no Gantt Chart (em anexo), desenvolvido na fase Inception, podemos considerar que o projeto se encontra alinhado, de forma a cumprir as datas de entrega estipuladas.

No que concerne ao orçamento do projeto, este encontra-se dentro dos limites estabelecidos pela empresa Pet Universal. O orçamento contemplado tem em consideração possíveis danos em componentes, isto é, tem em conta um componente extra, caso exista algum percalço.

Como referido acima, o projeto está a decorrer como previsto. O único ponto ainda por ser decidido, prende-se com a definição do local onde serão integradas as coleiras: se numa coleira standard ou se numa coleira dorsal.

Esta questão surgiu pela necessidade de obter informação fidedigna, proveniente dos dados recolhidos pelos sensores.

## III. Arquitetura

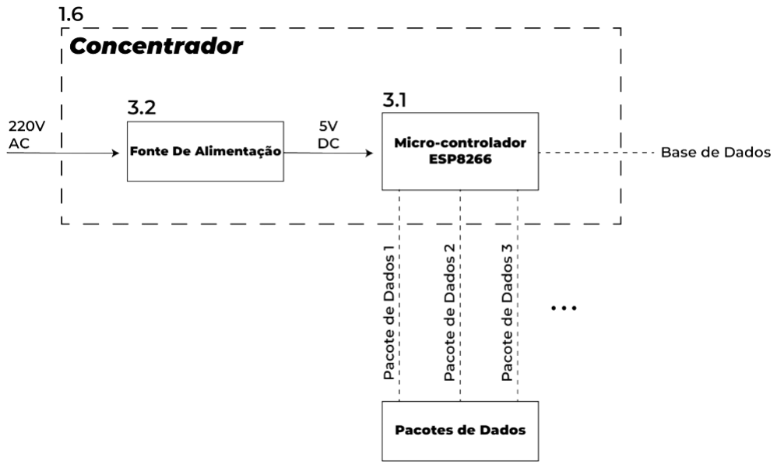
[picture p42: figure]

Figura 1 - Solução: Diagrama de Blocos

Em relação à arquitetura do sistema, contamos com dois diagramas de blocos, que correspondem ao sistema que vai estar presente na coleira do animal, e ao concentrador, que vai permitir o envio dos variados pacotes recebidos da coleira para a internet do hospital veterinário (Figura 1).

No fluxograma apresentado de seguida (Figura 2), temos os diferentes estados que o sistema empregue na coleira irá possuir.

Começamos pelo “DeepSleep” da ESP8266, que se concretiza por um modo de poupança de energia, com a duração de 5 minutos, onde esta estará desligada.

Após a passagem do tempo definido, a ESP8266 irá ligar-se, pedir valores aossensores(Acelerómetro, Temperatura e Oxímetro) e posteriormente criar um pacote de dados que irá ser enviado via WiFi para o concentrador.
De seguida, a ESP8266 irá voltar ao estado “DeepSleep”, o que resulta num período de operação de 1 segundo no seu estado ativo, intervalado por 5 minutos inativa. Com isto, temos um consumo 165mA por dia, o que se traduz em cerca de 5 dias de uso.


Figura 2 - Solução: Fluxograma

IV. Tarefas especificadas (Calendarização vs.

## Implementação)

ID | Descrição | Data original | Data Reformulada | Data Real
1 | Especificação, escolha e aquisição dos sensores | 2ª e 3ª semana de outubro | Data original | Data original
2 | Especificação do concentrador | 2ª e 3ª semana de outubro | Data original | Data original
3 | Estudo e especificação do layout da coleira | 2ª e 3ª semana de outubro | Data original | Data original
4 | Design da arquitetura do sistema: Diagrama de blocos | 4ª semana de outubro à 1ª semana de novembro | Data original | Data original
5 | Implementação da componente de hardware: conectividade entre o microcontrolador (ESP8266) e os três sensores aplicados no projeto (sensor de temperatura, módulo acelerómetro e sensor de ritmo cardíaco eníveis de oxigénio) | 2ª semana de novembro à 3ª semana de dezembro | 3ª semana de novembro | 3ª semana de novembro
6 | Implementação do concentrador: comunicação entre microcontroladores e visualização em dashboard dos dados recebidos | 2ª semana de novembro à 3ª semana de dezembro | 3ª semana de novembro | 4ª semana de novembro
7 | Interligação Backend-Hardware | 1ª, 2ª e 3ª semana de dezembro | 4ª semana de novembro à 2ª semana de dezembro | 4ª semana de novembro
8 | Especificação da implementação do hardware na coleira | 1ª, 2ª e 3ª semana de dezembro | Data original | -
9 | Testes do produto | 1ª, 2ª e 3ª semana de dezembro | Data original | -
10 | Validação | 4ª semana de dezembro e 1ª semana de janeiro | Data original | -
11 | Montagem do produto | 2ª e 3ª semana de janeiro | Data original | -

## a) Progresso e desvio do plano

No que concerne ao layout da coleira, o plano inicial que o grupo equacionou consistia no desenvolvimento de uma caixa, onde estaria contida a parte de hardware - sensores e microcontrolador, e que, posteriormente, seria integrada numa coleira standard, como se encontra representado na Figura 3.

Porém, de forma a conseguir recolher a informação mais fidedigna possível, o grupo irá também considerar o layout de uma coleira dorsal, como se encontra representado na Figura 4, fazendo com que a recolha dos dados seja feita em dois locais diferentes, e se possam fazer testes, de forma a que a escolha entre coleira standard e a coleira dorsal, para o produto final, seja feita segundo a que mostre recolher melhores resultados.


Figura 3 - Protótipo inicial da coleira a desenvolver


Figura 4 - Protótipo a considerar da coleira a desenvolver

## b) Plano de trabalho para a próxima iteração

Tendo em conta o trabalho desenvolvido até ao momento, uma das próximas etapas passa por finalizar o setup que permita aos médicos veterinários definir o tempo de recolha de dados que pretendem, isto porque cada animal irá necessitar de um tipo de vigilância diferente.

Tendo em consideração que o hardware a ser integrado nas coleiras possui uma bateria - Li-Po - que poderá tornar-se perigosa quando possui uma baixa carga, a próxima fase passa por desenvolver um alerta para quando se verificam níveis de bateria fracos.

No que respeita ao protótipo da coleira, o desenvolvimento do modelo 3D da caixa a ser integrada na mesma, realizado no software Fusion 360, encontra-se finalizado, uma vez que já foi possível imprimir o PCB, tendo, portanto, conhecimento das dimensões reais que este irá apresentar (Anexo 2).

Além do referido, também se encontra desenvolvido o modelo 3D do concentrador que, tal como a caixa da coleira, também foi consequência de trabalho realizado no Fusion 360 (Anexo 3).

Em relação ao progresso da aplicação móvel para tablet, neste momento a aplicação já tem operacionais todas as funcionalidades que foram definidas inicialmente como necessárias. Consequentemente, já é possível visualizar a apresentação das medições realizadas pelos sensores.

Até à fase final do projeto, o grupo compromete-se a trabalhar na melhoria das funcionalidades já apresentadas.

No que concerne ao tipo de coleira a considerar - standard ou dorsal - irão realizar-se testes em animais com características diferenciadas, nomeadamente: espécies, pelagens e dimensões.

Em última instância, irá optar-se pela opção que permita aos sensores conceder dados mais fidedignos.

## V. Riscos

Em relação aos riscos, não serão abordados os riscos de nível 4, uma vez que a probabilidade de se verificarem é muito baixa.

Iniciaremos pelos riscos que, caso ocorram, irão provocar mais problemas, ou seja, os riscos de nível 2.
O primeiro ponto a referir passa pelo software de visualização dos dados recolhidos desenvolvido pela empresa não estar terminado (em tempo útil). Num contexto em que este não se encontra-se finalizado, não nos seria possível mostrar ao cliente os dados recolhidos dos animais. A forma que o grupo encontrou para mitigar o risco em questão, passou pela elaboração de uma aplicação móvel para tablet, para que seja possível apresentar o produto final completamente funcional, sem depender de recursos externos para tal.

Outro risco a evidenciar é a qualidade do produto não atingir a expectativa do cliente, isto é, com o decorrer dos trabalhos, o produto que se está a desenvolver não corresponder ao idealizado pelo cliente. Como forma de mitigar este risco, utilizamos um método Agile para o desenvolvimento deste projeto, de forma a garantir a sinergia entre o que é desenvolvido pela equipa e o que é pretendido pelo cliente.

O terceiro maior risco a abordar, passa pela existência de defeitos no software. Estes podem não ser detetados até à implementação total dos componentes, ou seja, durante os testes individuais podem funcionar como pretendido, mas quando o produto estiver concluído e for testado no ambiente real, podem surgir falhas, provenientes de fatores não considerados em testes individuais dosmódulos funcionais.

De forma a colmatar situações como a descrita acima, serão efetuados testes em vários ambientes reais e será feita uma revisão do código frequente.

Apontando agora os riscos de nível 3, identificamos três riscos que vão ter influência direta no desenvolvimento do trabalho.

Um dos riscos que foi apresentado até ao momento, prendeu-se com a possibilidade de ocorrer um atraso na impressão do PCB desenvolvido, risco que acabou por se verificar, o que provocou demora no progresso dos trabalhos que, por sua vez, afetou a calendarização planeada. Na tentativa de evitar percalços deste género, optámos por criar uma margem de erro na calendarização, para minimizar o efeito de eventuais imprevistos como este.

O último risco a evidenciar prende-se com a imprecisão dos dados recolhidos pelos sensores, o que pode resultar no envio de valores pouco precisos para a aplicação. Uma situação deste género, além de desvalorizar o produto, trará uma vertente de incerteza e desconfiança por parte dos utilizadores, que não sabem se podem confiar nos dados apresentados. Especificando, podem pensar que está tudo beme o animal necessita de cuidados, e o inverso. Como medida para mitigar este risco, vamos testar, sempre que possível, em ambiente real.

De seguida, são apresentadas as tabelas de gestão de riscos.

11

Tabela 1 - Análise Inicial

Análise Inicial

# | Risco | Consequência | Probabilidade | Gravidade | Nível | Solução

1 | Imprecisão dos dados recolhidos pelos
| sensores | Alertas errados para a
| | aplicação | Ocasional | Marginal | 3 | Recolha de informação + Testes

3

Software de visualização dos dados recolhidos desenvolvido pela empresa (tempo útil)

Não ser possível analisar
os dados | Remoto | Crítico | 2 | Feature extra: Aplicação Móvel

### 5 Doença Inesperada

Falta defuncionamento
num dos componentes | Remoto | Negligenciável | 4 | Ter o trabalho sempre dentro dos prazos

9

Defeitos no software que poderão não

ser detetados atéà sua implementação Alterações de última hora | Ocasional | Crítico | 2 | Revisões dos programas e testagens sobre
| | | | qualquer ambiente

12

Tabela 2 - Análise Riscos Residuais

Análise Riscos Residuais

Consequência | R_Likel. | R_Sever. | R_Level
Alertas com uma imprecisão de percentagem baixa | Remoto | Negligenciável | 4
Nem todos os dados serem possíveis para análise | Ocasional | Marginal | 3
Produto ligeiramente desviado do pretendido | Remoto | Negligenciável | 4

## VI. Estado financeiro

Tabela 3 - Orçamento

# | Categoria | Descrição | Estado | Valor/un

4 | Microcontrolador | Microcontrolador com acesso ao WiFi (ESP8266) | Adquirido | 5,99 €
2 | Sensores | Módulo acelerómetro digital-3 eixos (ADXL-345) | Adquirido | 4,94 €
2 | Sensores | Sensor de temperatura | Adquirido | 3,70 €
2 | Sensores | Sensor de ritmo cardíaco e níveis de oxigenação | Adquirido | 7,32 €
2 | Botões e Interrupto-res/ Deslizantes | Interruptor deslizante 2 posições estáveis - ON-ON -250VAC 1A (6 pinos) | Adquirido | 0,73 €
1 | Baterias | 18650 cell | Adquirido | 5,48 €
2 | Baterias e Pilhas | Bateria Lítio Polímero 3.7v 500 mAh | Adquirido | 7,66 €
3 | Carregamento de ba-terias e BMS | Módulo carregador de bateria Li-Ion 1A - entrada Mi-cro-USB | Adquirido | 1,96 €
3 | Conversores Step Up | Módulo Boost Step Up - 0.9..4.2V para 5V -40..480mA | Adquirido | 2,05 €
6 | Terminais | Ficha Micro-USB (fêmea) | Adquirido | 0,85 €
Total: | 95,27 €

Foi adquirido um componente de cada tipo, para que fosse possível começar a realizar testes. Nesta primeira fase foi feito um investimento total de 45,27 €.

Após a aquisição anteriormente referida, no momento da montagem, em placa branca, da componente de hardware, o grupo deparou-se com dois componentes não funcionais, o que originou a necessidade de encomendar, novamente, esses componentes - módulo carregador de bateria Li-Ion 1A e módulo Boost Step Up.

Relativamente à bateria das coleiras, o grupo adquiriu, na primeira fase de compras, uma bateria 18650, porém optou-se pela escolha de uma bateria Li-Po ao invés da referida anteriormente, uma vez que o peso destas é um fator a ter em conta, não podendo este apresentar um valor significativo, já que nos referimos a uma coleira destinada a animais.

Desta forma, até ao momento, foi realizado um investimento total de 60,61 € (45,27 € + 15,34 €).

Se a testagem apresentarresultados positivos, está planeada a aquisição dosrestantes componentes, para que se possa terminar o projeto com duas coleiras funcionais bem como dois concentradores, o que vai culminar no orçamento total descrito na tabela acima (Tabela 3).

## VII. Contribuição do grupo

Membro do

Grupo | Maior(es) Contribuição(ões) | Percentagem de trabalho (%)

Bruna Pires

Fase Inicial até à fase de Elaboração, inclusive:
- Desenvolvimento da documentação referente a três propostas de projetos;
- Pesquisa: sensores a utilizar e métodos de implementação da solução idealizada;
- Desenvolvimento da apresentação referente à Milestone 1 e Milestone 2;
- Desenvolvimento do documento “Planeamento do Projeto”;
- Participação no desenvolvimento do Excel “Gestão Dos Riscos”;
- Participação no desenvolvimento do documento “Relatório do Estado do Projeto”;
- Realização da conectividade entre o microcontrolador - ESP8266 - e o sensor de ritmo cardíaco e níveis de oxigénio e posterior testagem do mesmo.
Fase de Construção I:
- Desenvolvimento da apresentação referente à Milestone 3;
- Participação no desenvolvimento de testes em animais do hardware a ser implementado nas coleiras;
- Desenvolvimento de uma aplicação móvel para tablet;
- Desenvolvimento do documento “Relatório do Estado do Projeto”.
Fase de Construção II:
- Arduino IDE: Conectividade entre os sensores e a base de dados (Firebase);
- Apresentação dos dados armazenados na Firebase na aplicação móvel para tablet;
- Desenvolvimento da apresentação referente à Milestone 4;
- Desenvolvimento do documento “Relatório do Estado do Projeto”.

23%

André
Santos

Fase Inicial até à fase de Elaboração, inclusive:
- Pesquisa: sensores a utilizar, métodos de implementação da solução idealizada, consumos energéticos e receção de dados com o Google Sheets;
- Participação no desenvolvimento do documento “Visão do Projeto”;
- Participação no desenvolvimento do Excel “Gestão Dos Riscos”;
- Participação no desenvolvimento do documento “Relatório do Estado do Projeto”;
- Criação de um esboço no Fusion 360 do modelo da coleira.
Fase de Construção I:
- Participação no desenvolvimento do modelo 3D da caixa do concentrador no Fusion 360;
- Participação no desenvolvimento de testes em animais do hardware a ser implementado nas coleiras.
Fase de Construção II:
- Desenvolvimento do modelo 3D da caixa a incorporar na coleira por intermédio do Fusion 360.

19%

Membro do Grupo | Maior(es) Contribuição(ões) | Percentagem de trabalho (%)
Daniel Almeida | Fase Inicial até à fase de Elaboração, inclusive: - Participação no desenvolvimento do documento “Visão do Projeto”; - Participação no desenvolvimento do Excel “Gestão Dos Riscos”; - Participação no desenvolvimento do documento “Relatório do Estado do Projeto”; - Formulação da comunicação entre dois microcontroladores - ESP8266 - e visualização em dashboard de dados recebidos. Fase de Construção I: - Participação no desenvolvimento do PCB no Fusion 360. Fase de Construção II: - Configuração da UI que permite ao utilizador configurar a ligação à rede com acesso à internet. | 19%

Gonçalo
Martins

Fase Inicial até à fase de Elaboração, inclusive:
- Pesquisa: sensores a utilizar, métodos de implementação da solução idealizada, consumos energéticos e receção de dados com o Google Sheets;
- Participação no desenvolvimento do documento “Visão do Projeto”;
- Desenvolvimento dos diagramas de blocos presentes na apresentação referente Milestone 2;
- Participação no desenvolvimento do documento “Relatório do Estado do Projeto”;
- Realização da conectividade entre o microcontrolador - ESP8266 - e o sensor de temperatura bem como o módulo acelerómetro;
- Arduino IDE: Programação do módulo ESP8266.
Fase de Construção I:
- Participação no desenvolvimento do modelo 3D da caixa do concentrador no Fusion 360;
- Impressão 3D do modelo desenvolvido da caixa do concentrador;
- Participação no desenvolvimento de testes em animais do hardware a ser implementado nas coleiras.
Fase de Construção II:
- Desenvolvimento do PCB no EasyEDA;
- Impressão 3D do modelo desenvolvido da caixa a incorporar na coleira

22%

João Pedrosa

Fase Inicial até à fase de Elaboração, inclusive:
- Participação no desenvolvimento do documento “Visão do Projeto”;
- Participação no desenvolvimento do Excel “Gestão Dos Riscos”;
- Participação no desenvolvimento do documento “Relatório do Estado do Projeto”;
- Formulação da comunicação entre dois microcontroladores - ESP8266 - e visualização em dashboard de dados recebidos.
Fase de Construção I:
- Participação no desenvolvimento do PCB no Fusion 360;
- Participação no desenvolvimento de testes em animais do hardware a ser implementado nas coleiras.
Fase de Construção II:
- Formulação do setup que possibilite aos médicos veterinários definir o tempo de recolha de dados que considerem mais adequado.

17%

## VIII. Outras questões

No decorrer da primeira fase de construção, o grupo testou o hardware desenvolvido que, posteriormente, será implementado nas coleiras. Esta ação teve como finalidade verificar a operacionalidade dos sensores, bem como a precisão dos dados recolhidos, quando empregues em animais.

Para isso, o primeiro teste realizado teve como cobaia uma gata de seis meses. O hardware implementado em placa branca, constituído por um microcontrolador - ESP8266 - e três sensores, foi aproximado junto do pescoço do animal e os dados recolhidos pelos sensores foram armazenados e apresentados num Google Sheets concretizado para o efeito – [Testes] - Coleira.

Alternativamente, o hardware foi aproximado na região tórax do animal a fim de verificar a variação dos dados recolhidos, permitindo concluir em que zona os dados se mostravam mais fidedignos e estáveis. O resultado destes testes teve parecer positivo, porém o grupo quis generalizar mais esta testagem, por isso deslocou-se até ao Hospital Veterinário de Aveiro. Este contexto permitiu que o grupo realiza-se ensaios, tanto em cães, como em gatos, com características diferenciadas, tais como: pelagens e dimensões.

Em suma, este primeiro período de testagens permitiu concluir que os dados recolhidos pelos sensores são maissatisfatórios quando são retirados junto do pescoço do animal, ou seja, existe a propensão de uma coleira standard para o protótipo do produto final.

## IX. Comentários e observações

Nada a assinalar.

## X. Conclusões

Dado o atual progresso deste projeto, pode-se aferir que os objetivos essenciais, propostos numa fase inicial, vão ser cumpridos com sucesso.

De uma forma mais detalhada, o facto de já ser possível recolher dados com valores credíveis provenientes de todos os sensores, de conseguir que estes comuniquem eficazmente com o concentrador e de armazenar e apresentar esses mesmos dados (no Google Sheets), todos estes fatores espelham o bom rumo do trabalho efetuado, até ao momento.

No seguimento do anteriormente referido, os avanços significativos alcançados pela equipa, fazem com que seja possível alocar alguns dos elementos a tarefas distinguidasinicialmente como secundárias, com vista a aumentar a utilidade e o valor do produto que se está a desenvolver, no seu mercadoalvo.

Segue-se uma fase onde o protótipo a ser utilizado nos testes se aproxima bastante do que será o produto final, o que vai ser um fator relevante e benéfico aquando da realização desses mesmos testes, uma vez que vai permitir que praticamente todos osfatoressejam semelhantes a um contexto real, em detrimento do que aconteceu nos testes realizados anteriormente, por exemplo, onde o facto dos sensores estarem alocados a uma placa branca, tornava os testes mais difíceis para o grupo e para os animais também, já que requeria que estes se encontrassem quietos e é de conhecimento geral a dificuldade que é conseguir esse cenário.

Uma vez que se consiga ter o hardware condensado com PCB's, dentro das devidas caixas e colocadas em coleiras, todo o produto vai ser submetido a um conjunto final de testes, para os quais a equipa se encontra bastante otimista, uma vez que osresultados obtidos até este momento foram bastante favoráveis.

## XI. Anexos Anexo 1 – Gantt Chart

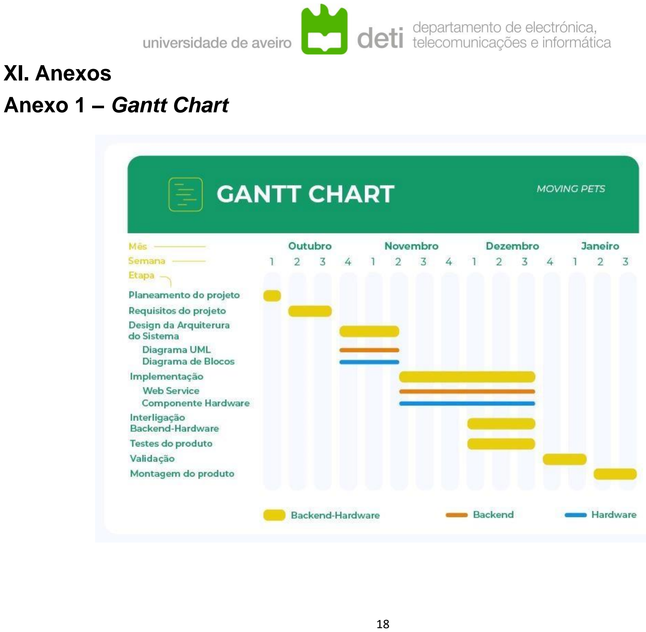
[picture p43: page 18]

18


18

## Anexo 2 – Protótipo da caixa a incorporar na coleira

Figura 5 – Tampa da caixa

Figura 6 – Base da caixa

19


18

## Anexo 3 – Protótipo da caixa do concentrador

Figura 7 – Tampa do concentrador

Figura 8 – Base do concentrador

20

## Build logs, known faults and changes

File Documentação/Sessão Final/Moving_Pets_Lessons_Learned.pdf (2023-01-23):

## 42088 – Projeto Industrial

# Lições Aprendidas

Nome do Projeto: | Moving Pets
Empresa: | Pet Universal
Orientador da Empresa: | Eng. Luís Pinto
Data: | 23/01/2023
Membros da Equipa: | Contacto principal: Bruna Pires | bruna.ramos.pires@ua.pt | +351 936 038 835 Mem-bros do grupo: André Santos | andre.ssantos@ua.pt | +351 910 848 545 Daniel Almeida | danielba@ua.pt | +351 960 436 934 Gonçalo Martins | goncalom23@ua.pt | +351 934 554 483 João Francisco | joaofpedrosa@ua.pt | +351 962 478 430
Orientador: | Prof. Osvaldo Pacheco

O que foi feito corretamente
Maiores Sucessos do Projeto | Fatores que promoveram este sucesso | Ações para promover o sucesso
Protótipo completamente funcional. | - Trabalho paralelo; - Montagem do protótipo em placa branca. | - Organização do grupo; - Cedência de materiais por conta própria; - Boa gestão temporal por parte de cada elemento do grupo.
Rapidez no desenvolvimento do projeto. | - Rápida organização/comunicação com a empresa; - Reuniões eficientes. | - Encomenda rápida de componentes; - Criação de um Gantt Chart.

O que foi feito corretamente
Outros sucessos que a equipa gostaria de destacar | Fatores que promoveram este sucesso | Ações para promover o sucesso
Protótipos 3D. | - Dedicação do elemento responsável à tarefa. | Pesquisa por parte do elemento responsável por informação sobre o tema.
Aplicação. | - Dedicação do elemento responsável à tarefa. | Pesquisa por parte do elemento responsável por informação sobre o tema.

O que foi feito de errado
Falhas no projeto | Fatores que contribuíram para o fracasso | Ações corretivas
Comunicação com a Pet Universal. | Falta de interesse pela empresa. | Não aceitar empresas que não estão realmente interessadas em colaborar com a universidade no programa desta cadeira.
Comunicação e organização do grupo. | Falta de reuniões em fases iniciais de modo a organizar de uma forma correta a divisão de trabalhos. | Realizar reuniões mais organizadas e constantes ao longo do período de desenvolvimento do projeto.

O que foi feito de errado
Outros problemas que a equipa gostaria de destacar | Fatores que causaram o problema | Ações corretivas
Erros no desenvolvimento do PCB. | A universidade não colaborou com a ajuda da criação do PCB, não foram enviadas nem regras de “routes”, nem dicas para promover um bom PCB. | - Encomenda a instituições mais especializadas na produção de PCBs.

Disponibilidade orçamental.

A empresa não se mostrou disponível a cobrir os custos do projeto.

- Estudo por parte da empresa sobre o funcionamento orçamental de um projeto de eletrónica;
- Por parte da universidade, mais disponibilidade de momentos para encomenda de componentes.

O que poderia ter sido feito melhor
O que seria feito de forma diferente no futuro | Fatores que podem contribuir para melhorar
o desempenho | Ações para melhorar o desempenho

Otimizar o produto físico.

- Componentes SMD;
- Coleira apropriada.
- Fazer esquemas com componentes SMD;
- Fazer o design da coleira.
Teste de sensores mais variada. | Disponibilidade orçamental.
- Por parte da universidade, mais disponibilidade de momentos para encomenda de componentes para o projeto.
- Aumentar a duração de desenvolvimento do projeto.

Artigos diversos
Nada a assinalar.

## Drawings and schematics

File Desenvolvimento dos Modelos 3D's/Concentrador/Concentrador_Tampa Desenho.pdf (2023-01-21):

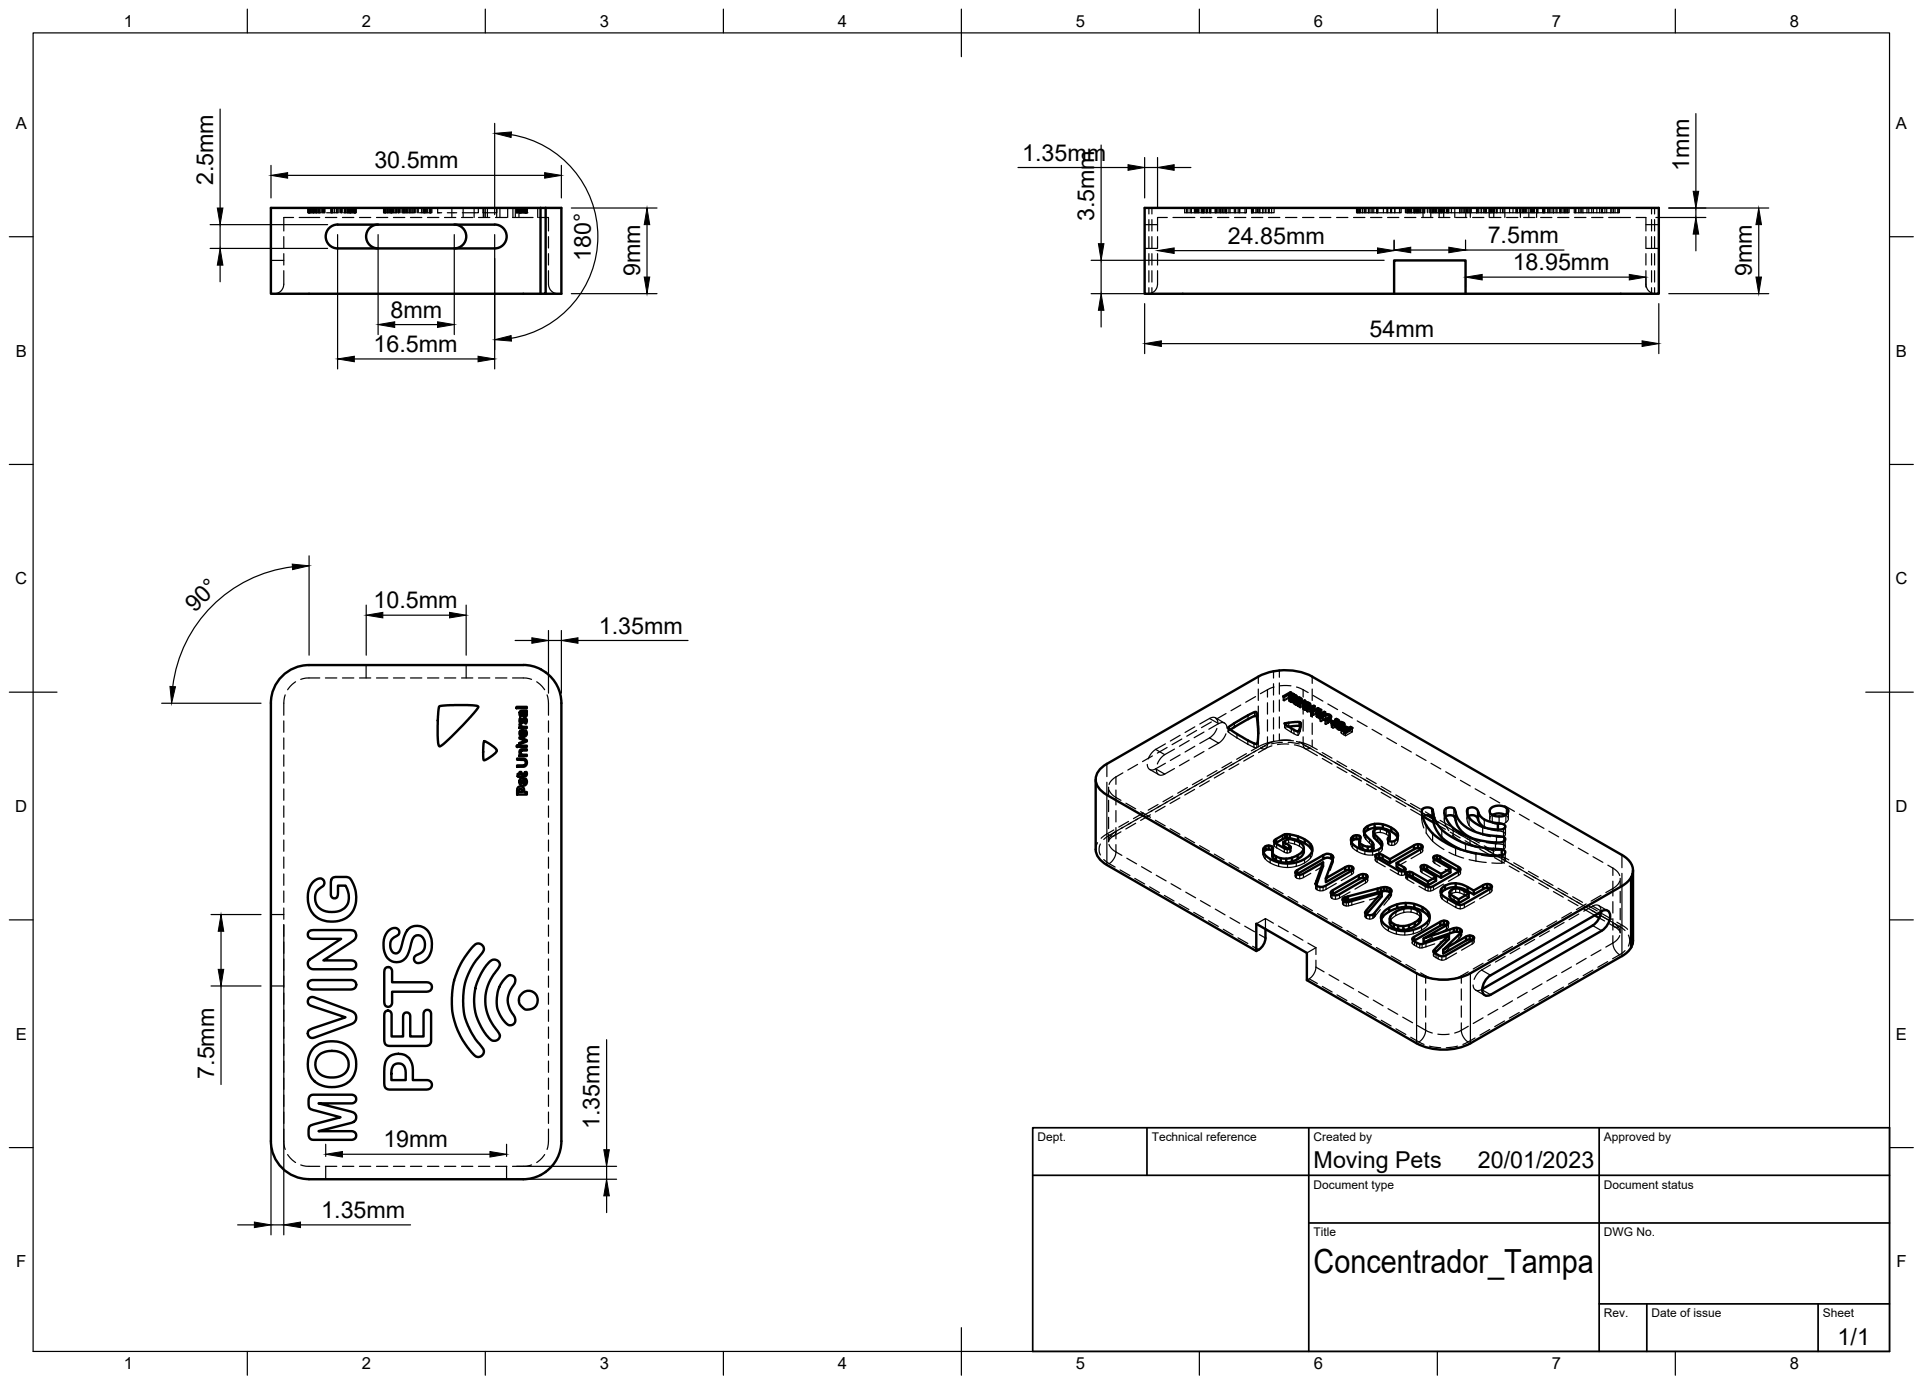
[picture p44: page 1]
Title; DWG No.; Rev.; Date of issue; Sheet; Moving Pets 9mm

Dept. | Technical reference | Created by 20/01/2023 | Approved by

Document type | Document status

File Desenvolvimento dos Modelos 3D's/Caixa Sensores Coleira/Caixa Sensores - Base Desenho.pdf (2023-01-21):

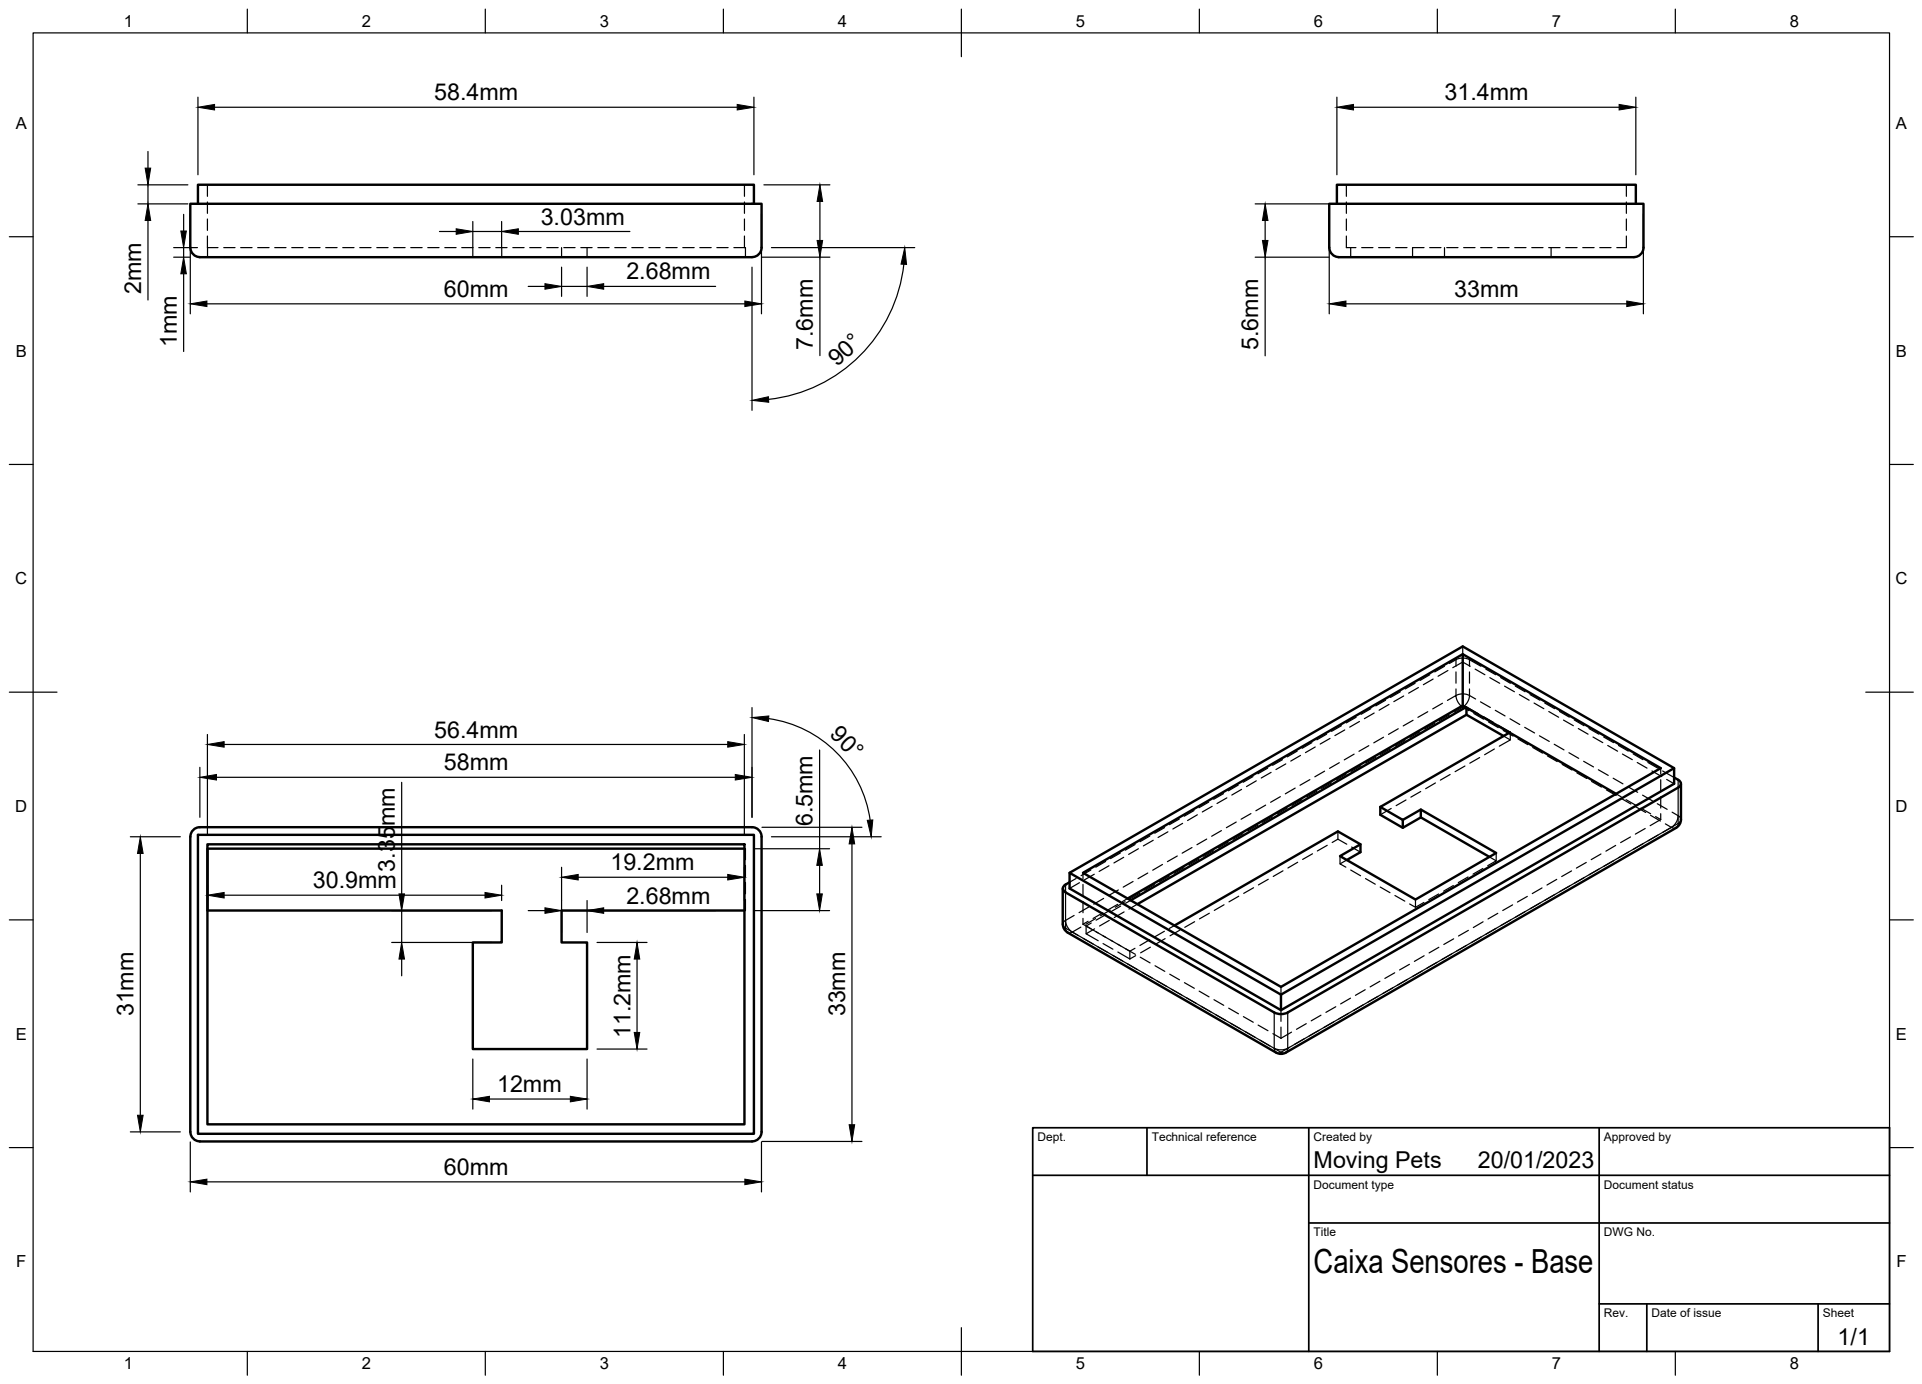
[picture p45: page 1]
Title; DWG No.; Rev.; Date of issue; Sheet

Dept. | Technical reference | Created by Moving Pets 20/01/2023 | Approved by

Document type | Document status

Caixa Sensores - Base

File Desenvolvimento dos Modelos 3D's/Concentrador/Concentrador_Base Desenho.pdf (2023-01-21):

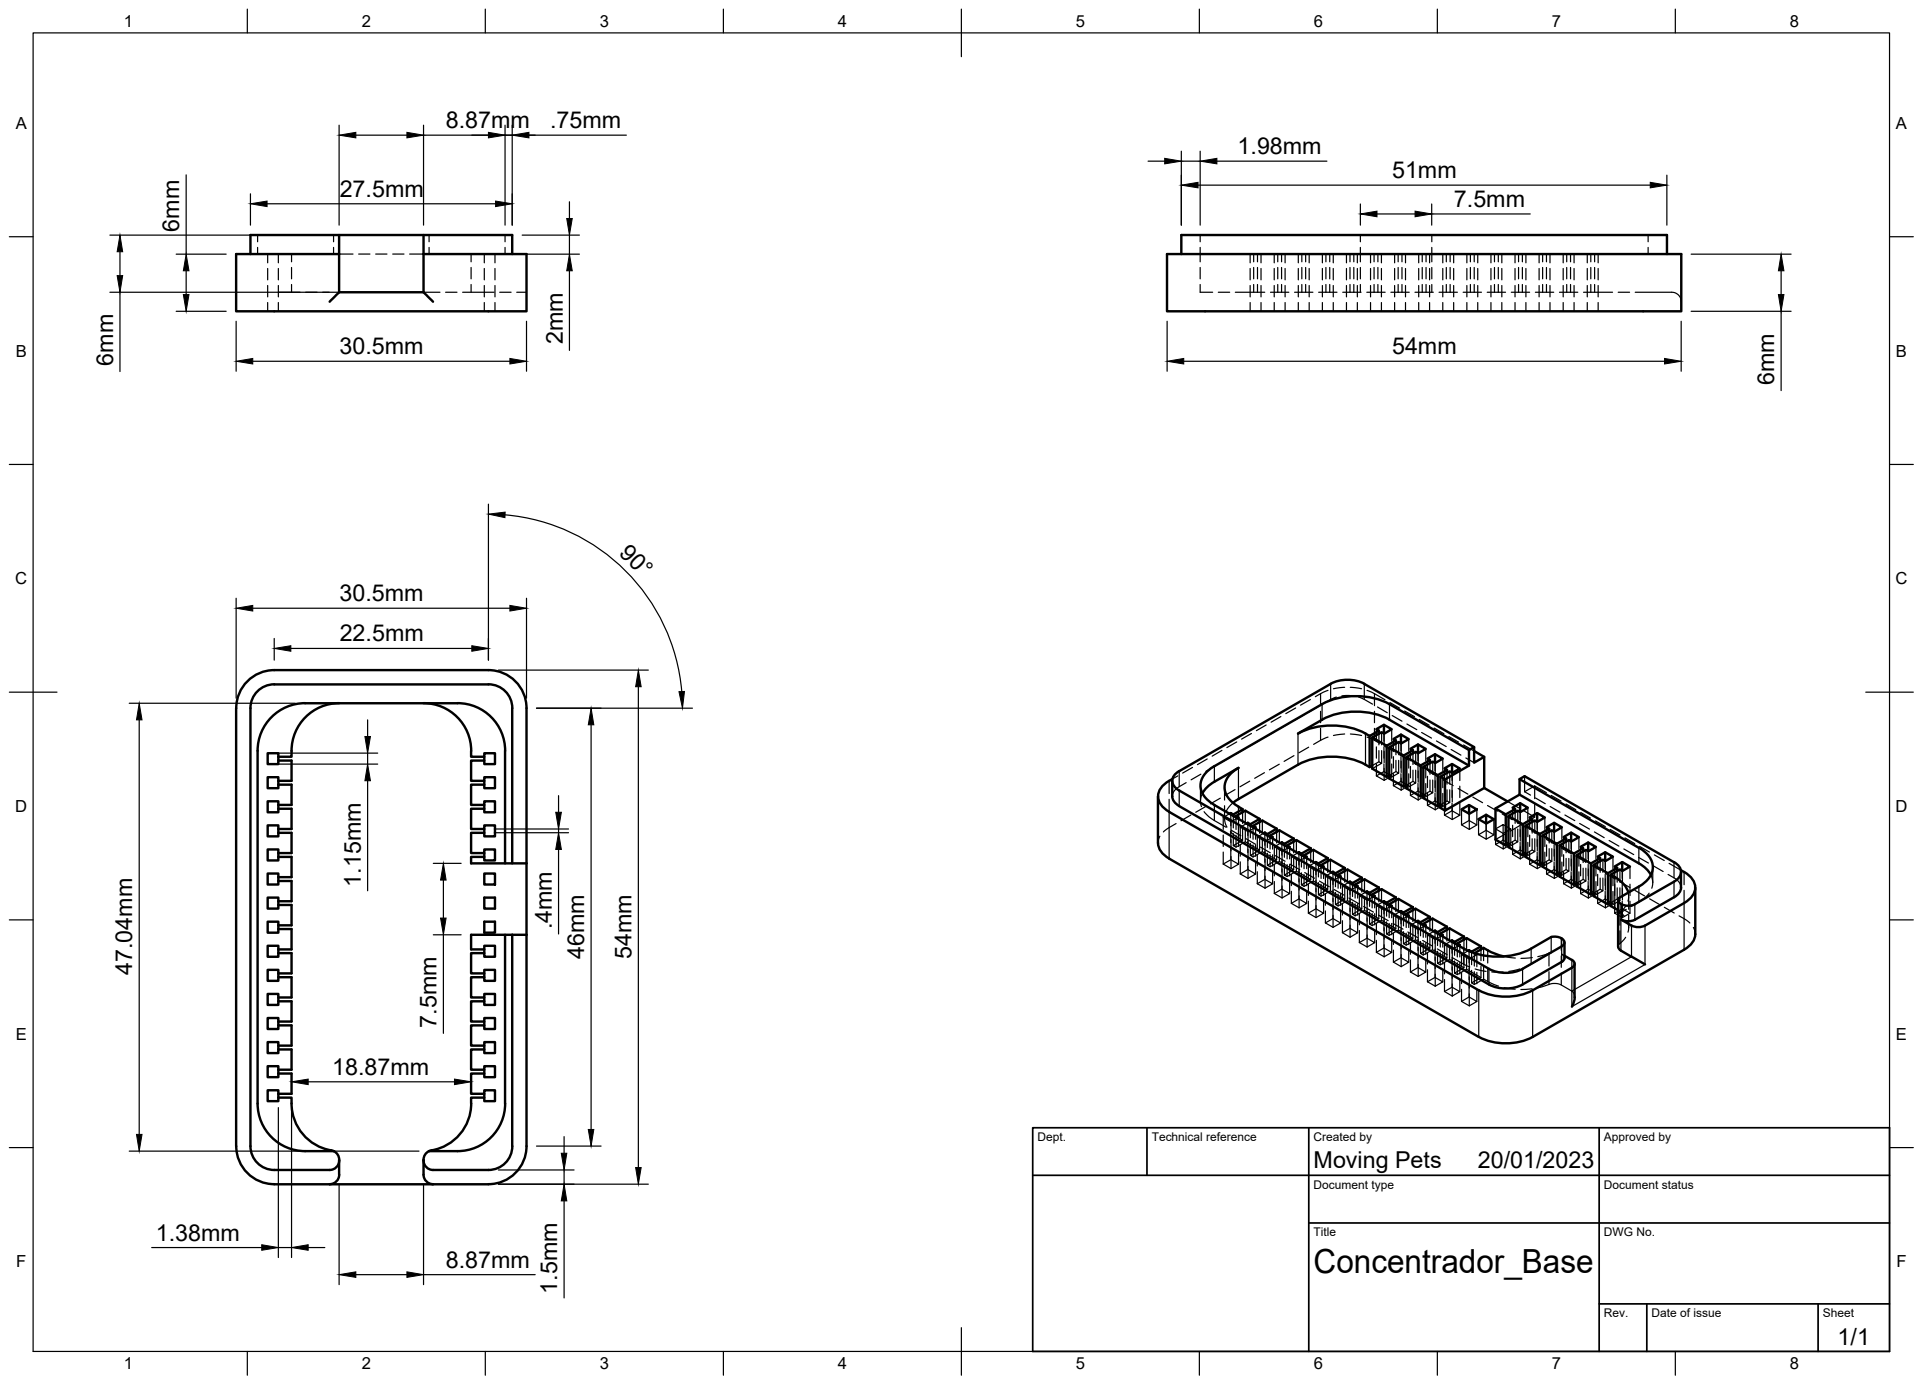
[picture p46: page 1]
Dept.; Technical reference; Created by; Approved by; Document type; Document status; Title; DWG No.; Rev.; Date of issue; Sheet; Moving Pets

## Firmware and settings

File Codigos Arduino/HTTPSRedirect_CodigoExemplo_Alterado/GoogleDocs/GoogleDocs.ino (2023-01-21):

/*  HTTPS on ESP8266 with follow redirects, chunked encoding support
 *  Version 3.0
 *  Author: Sujay Phadke
 *  Github: @electronicsguy
 *  Copyright (C) 2018 Sujay Phadke <electronicsguy123@gmail.com>
 *  All rights reserved.
 *
 *  Example Arduino program
 */

#include <ESP8266WiFi.h>
#include "HTTPSRedirect.h"
#include "DebugMacros.h"

// Fill ssid and password with your network credentials
const char* ssid = "Vodafone-DBCD72"; // Your wifi name or SSID.
const char* password = "2D7KNEEGyc93VFHF"; // Your wifi password.

const char* host = "script.google.com";
// Replace with your own script id to make server side changes
const char *GScriptId = "AKfycbwT1wa5zj8vJ5HfNJbkjFAaKWO28ACZHhboZ3Ebi5raXaXJejtfGNYl7IorFEH8FVNWkQ";

const int httpsPort = 443;

// echo | openssl s_client -connect script.google.com:443 |& openssl x509 -fingerprint -noout
const char* fingerprint = "";
//const uint8_t fingerprint[20] = {};

// Write to Google Spreadsheet
String url = String("/macros/s/") + GScriptId + "/exec?value=Hello";
// Fetch Google Calendar events for 1 week ahead
String url2 = String("/macros/s/") + GScriptId + "/exec?cal";
// Read from Google Spreadsheet
String url3 = String("/macros/s/") + GScriptId + "/exec?read";

String payload_base =  "{\"command\": \"appendRow\", \
                    \"sheet_name\": \"Sheet1\", \
                    \"values\": ";
String payload = "";

HTTPSRedirect* client = nullptr;
// used to store the values of free stack and heap
// before the HTTPSRedirect object is instantiated
// so that they can be written to Google sheets
// upon instantiation
unsigned int free_heap_before = 0;
unsigned int free_stack_before = 0;

void setup() {
  Serial.begin(9600);
  Serial.flush();
  
  free_heap_before = ESP.getFreeHeap();
  free_stack_before = ESP.getFreeContStack();
  Serial.printf("Free heap: %u\n", free_heap_before);
  Serial.printf("Free stack: %u\n", free_stack_before);
  
  Serial.println();
  Serial.print("Connecting to wifi: ");
  Serial.println(ssid);
  // flush() is needed to print the above (connecting...) message reliably, 
  // in case the wireless connection doesn't go through
  Serial.flush();

  WiFi.begin(ssid, password);
  while (WiFi.status() != WL_CONNECTED) {
    delay(500);
    Serial.print(".");
  }
  Serial.println("");
  Serial.println("WiFi connected");
  Serial.println("IP address: ");
  Serial.println(WiFi.localIP());

  // Use HTTPSRedirect class to create a new TLS connection
  client = new HTTPSRedirect(httpsPort);
  client->setInsecure();
  client->setPrintResponseBody(true);
  client->setContentTypeHeader("application/json");
  
  Serial.print("Connecting to ");
  Serial.println(host);

  // Try to connect for a maximum of 5 times
  bool flag = false;
  for (int i=0; i<5; i++){
    int retval = client->connect(host, httpsPort);
    if (retval == 1) {
       flag = true;
       break;
    }
    else
      Serial.println("Connection failed. Retrying...");
  }

  if (!flag){
    Serial.print("Could not connect to server: ");
    Serial.println(host);
    Serial.println("Exiting...");
    return;
  }

/*  
  if (client->setFingerprint(fingerprint)) {
    Serial.println("Certificate match.");
  } else {
    Serial.println("Certificate mis-match");
  }
*/ 

  // Send memory data to Google Sheets
  payload = payload_base + "\"" + free_heap_before + "," + free_stack_before + "\"}";
  client->POST(url2, host, payload, false);
  payload = payload_base + "\"" + ESP.getFreeHeap() + "," + ESP.getFreeContStack() + "\"}";
  client->POST(url2, host, payload, false);
  
  // Note: setup() must finish within approx. 1s, or the the watchdog timer
  // will reset the chip. Hence don't put too many requests in setup()
  // ref: https://github.com/esp8266/Arduino/issues/34
  
  Serial.println("\nGET: Write into cell 'A1'");
  Serial.println("=========================");

  // fetch spreadsheet data
  client->GET(url, host);

  // Send memory data to Google Sheets
  payload = payload_base + "\"" + ESP.getFreeHeap() + "," + ESP.getFreeContStack() + "\"}";
  client->POST(url2, host, payload, false);
  
  Serial.println("\nGET: Fetch Google Calendar Data:");
  Serial.println("================================");

  // fetch spreadsheet data
  client->GET(url2, host);

  // Send memory data to Google Sheets
  payload = payload_base + "\"" + ESP.getFreeHeap() + "," + ESP.getFreeContStack() + "\"}";
  client->POST(url2, host, payload, false);
  
  Serial.println("\nSeries of GET and POST requests");
  Serial.println("===============================");
  
  Serial.printf("Free heap: %u\n", ESP.getFreeHeap());
  Serial.printf("Free stack: %u\n", ESP.getFreeContStack());

  // delete HTTPSRedirect object
  delete client;
  client = nullptr;
}

void loop() {
  static int error_count = 0;
  static int connect_count = 0;
  const unsigned int MAX_CONNECT = 20;
  static bool flag = false;
  //Serial.printf("Free heap: %u\n", ESP.getFreeHeap());
  //Serial.printf("Free stack: %u\n", ESP.getFreeContStack());
  
  if (!flag){
    free_heap_before = ESP.getFreeHeap();
    free_stack_before = ESP.getFreeContStack();
    client = new HTTPSRedirect(httpsPort);
    client->setInsecure();
    flag = true;
    client->setPrintResponseBody(true);
    client->setContentTypeHeader("application/json");
  }

  if (client != nullptr){
    if (!client->connected()){
      client->connect(host, httpsPort);
      payload = payload_base + "\"" + free_heap_before + "," + free_stack_before + "\"}";
      client->POST(url2, host, payload, false);
    }
  }
  else{
    DPRINTLN("Error creating client object!");
    error_count = 5;
  }
  
  if (connect_count > MAX_CONNECT){
    //error_count = 5;
    connect_count = 0;
    flag = false;
    delete client;
    return;
  }

  Serial.println("GET Data from cell 'A1':");
  if (client->GET(url3, host)){
    ++connect_count;
  }
  else{
    ++error_count;
    DPRINT("Error-count while connecting: ");
    DPRINTLN(error_count);
  }

  Serial.println("POST append memory data to spreadsheet:");
  payload = payload_base + "\"" + ESP.getFreeHeap() + "," + ESP.getFreeContStack() + "\"}";
  if(client->POST(url2, host, payload)){
    ;
  }
  else{
    ++error_count;
    DPRINT("Error-count while connecting: ");
    DPRINTLN(error_count);
  }

  /*
  if (!(client.reConnectFinalEndpoint())){
    ++error_count;
    DPRINT("Error-count while connecting: ");
    DPRINTLN(error_count);
  }
  else
    error_countunt = 0;
  */
  
  if (error_count > 3){
    Serial.println("Halting processor..."); 
    delete client;
    client = nullptr;
    Serial.printf("Final free heap: %u\n", ESP.getFreeHeap());
    Serial.printf("Final stack: %u\n", ESP.getFreeContStack());
    Serial.flush();
    ESP.deepSleep(0);
  }
  
  // In my testing on a ESP-01, a delay of less than 1500 resulted 
  // in a crash and reboot after about 50 loop runs.
  delay(4000);
                          
}

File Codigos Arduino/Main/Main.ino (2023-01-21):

#include "acelerometro.h"
#include "oximeter.h"
#include "wifi.h"
#include "leitor_bateria.h"
#include "temperatura.h"
#include "create_package.h"


unsigned long int timer_acelerometro = 0;
unsigned long int timer_oximeter = 0;
unsigned long int timer_temperatura = 0;
unsigned long int timer_battery = 0;
unsigned long int timer_package = 0;
unsigned long int timer_prints = 0;
unsigned long int timer_sensores = 0;


int DeviceID = 1;
float BatteryVoltage;
float BatimentosCardiacos;
float NiveisOxigenio;
float acelerometro[3];
float Aceleracao;
float Temperatura;
float Calibracao_temperatura = 1.9;

IPAddress ip( 192, 168, 25, DeviceID + 1);// pick your own suitable static IP address
IPAddress gateway( 192, 168, 25, 1 ); // may be different for your network
IPAddress subnet( 255, 255, 255, 0 ); // may be different for your network (but this one is pretty standard)
IPAddress dns(192,168,25,1);


void setup()                                 
{
  Serial.begin(9600);
  Serial.println();
  pinMode(LED_BUILTIN, OUTPUT);     // Initialize the LED_BUILTIN pin as an output
  //pinMode(A0, INPUT);
  //ADC_MODE(33);

  WiFi.disconnect(); 
  WiFi.mode(WIFI_OFF);
  WiFi.forceSleepBegin();
  delay(1);

  setup_acelerometro();         //Fazer uma média de 1segundo
  setup_oximeter();
  setup_temperatura();


  timer_sensores = millis();
  while(millis() - timer_sensores <= 60000)
  {
  update_oximeter();
  delay(10);
  update_acelerometro(&acelerometro[0]);
  delay(10);
  }
  Aceleracao = update2_acelerometro();
  update2_oximeter(&BatimentosCardiacos,&NiveisOxigenio);

    
  Temperatura = update_temperatura() + Calibracao_temperatura;
  BatteryVoltage = update_battery();
  wifi_setup(ip,dns, gateway, subnet);
  ReCheckConection();
  //create_send_package(DeviceID,BatteryVoltage,BatimentosCardiacos,NiveisOxigenio,&acelerometro[0],Temperatura);
  create_send_package(DeviceID,BatteryVoltage,BatimentosCardiacos,NiveisOxigenio,Aceleracao,Temperatura);

  WiFi.disconnect( true );
  delay( 1 );
  Serial.println("vou dormir 10segundos");
  ESP.deepSleep(10e6, WAKE_RF_DISABLED);
}

void loop()
{
/*//------------------------- acelerometro --------------------------------
  if(millis() - timer_acelerometro >= 1000)
  {
  update_acelerometro(&acelerometro[0]);
  timer_acelerometro = millis();
  }
//------------------------------ oximeter ---------------------------
  if(millis() - timer_oximeter >= 10)
  {
  update_oximeter();
  timer_oximeter = millis();
  }
//---------------------- temperatura -----------------------------------
  if(millis() - timer_temperatura >= 1000)
  {
  Temperatura = update_temperatura();
  timer_temperatura = millis();
  }

//---------------------- Batery_voltage -----------------------------------
  if(millis() - timer_battery >= 1000)
  {
  update_battery();
  timer_battery = millis();
  }

//---------------------- create package -----------------------------------
  if(millis() - timer_package >= 1000)
  {
  ReCheckConection();
  create_send_package(DeviceID,BatteryVoltage,BatimentosCardiacos,NiveisOxigenio,&acelerometro[0],Temperatura);
  timer_package = millis();
  }

  //---------------------- prints -----------------------------------
  //if(millis() - timer_prints >= 1000)
  //{
  //print_acelerometro();
  //print_oximeter();
  //print_temperatura();
  //timer_prints = millis();
  //}*/
}
